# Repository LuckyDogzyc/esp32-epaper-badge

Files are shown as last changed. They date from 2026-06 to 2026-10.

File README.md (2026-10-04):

> ⚠️ **当前有效需求为 V2.2：《[改板需求说明-V2.2-ESP32C3-降本](改板需求说明-V2.2-ESP32C3-降本.md)》**（Word 版同名 `.docx`）
> **V2.2 = 换主控 ESP32-C6 → ESP32-C3-MINI-1-N4（pin-to-pin 兼容，省 ¥4.73/台）+ 全线降本**，单台降本约 **¥7.6–10.7**（屏若由三色改黑白可再省 ¥8–13）。
> **器件选型以《[BOM锁定表-V2.2](BOM锁定表-V2.2.md)》为准**（含立创编号、库存、"不接受"项）。
> V2.2 要点：C3 主控（重排引脚：**USB 改到模组脚 26/27**、**脚 15/17/24/25 在 C3 上是 NC**、电量采样改 **IO4/ADC1_CH4**、VBUS 检测改 **IO20**）+ 板载 **AHT20 温湿度**（IO0/IO1，外壳需透气孔）+ 板 **67×28×0.6mm**、无安装孔、堆叠"屏朝外 → 电芯 → PCB"、电芯 ≤4mm、两个侧按键、整机厚 ≈9.1–9.6mm。
> ⚠️ **出图前红线**：FPC 针数/间距/金手指朝向（图纸 ↔ 屏厂规格 ↔ 实机来料）必须核对一致。
> **以下"硬件方案/GPIO 分配"等段落描述的是 V1 版本，仅作对照，冲突处一律以 V2.2 为准。**

## 文档索引

| 文件 | 版本 | 用途 |
|---|---|---|
| `改板需求说明-V2.2-ESP32C3-降本.md` / `.docx` | **V2.2（当前有效）** | 换 C3 + 降本：C3 引脚映射全表、USB 走线变更、降本项清单、温湿度要求、验收 |
| `BOM锁定表-V2.2.md` / `.xlsx` | **V2.2（当前有效）** | 器件锁定 BOM：锁定件给立创编号与库存，参数锁定件给硬指标与"不接受"项 |
| `改板需求说明-V2.1-ESP32C6-含温湿度.md` / `.docx` | V2.1（历史） | C6 版 + 温湿度增补；仅作沿革对照 |
| `BOM锁定表-V2.1.md` / `.xlsx` | V2.1（历史） | C6 版锁定表；仅作对照 |
| `改板需求说明-V2-ESP32C6.md` / `.docx` | V2（历史） | 换 C6、删桥片与烧录开关、修正电池分压、新增 VBUS 检测 |
| `外包需求文档.md` | V1（历史） | 初版外包需求 |

低功耗 ESP32 + 2.13" 三色电子纸显示器，用于每日自动更新数据展示。当前参考原理图版本为 v1.2：已补充 USB-C 直供电、电池自动切换、103040 软包电池 PH2.0 接口、电池电量检测，以及独立的 USER_BTN 用户按键。**本版本仅用于下一版 PCB/reference schematic；现有外部原型 GPIO 映射不同，不能据此改线或直接刷写。**

## 硬件方案

| 模块 | 方案 | 说明 |
|---|---|---|
| MCU | ESP32-WROOM-32D | WiFi + BLE，deep sleep 10µA |
| 屏幕 | DEPG0213RWS 2.13" | 三色(黑白红)，SSD1680 驱动 |
| 充电/直供电 | TP4056 + D3/D4 SS14 | USB-C 充电，支持无电池 USB 直供电 |
| 保护 | DW01A + FS8205A | 过充/过放/过流保护 |
| LDO | HT7333-1 | 超低 Iq=1µA |
| 电池 | 103040 软包锂电池 PH2.0 | 1200mAh，外接插头，deep sleep 续航目标 >1 年 |

## 电路模块

1. **ESP32 最小系统** — 抄 Espressif 官方设计指南 v4.4
2. **SSD1680 驱动电路** — 抄已验证驱动板 v1.3 原理图
3. **TP4056 充电 + D3/D4 电源路径切换** — USB-C VBUS 与 VBAT 通过 SS14 汇聚到 VCC_RAIL
4. **DW01A+FS8205A 保护** — 抄数据手册参考设计
5. **HT7333 LDO** — VCC_RAIL 转 3.3V 系统电源
6. **VBAT_SENSE 电量检测** — R12/R13 100k 分压 + C21 100nF 滤波 → GPIO34
7. **USER_BTN 独立用户按键** — SW2 常开按键把 `USER_BTN_N` 拉低；R14 10k 外部上拉至 3V3，C22 100nF 去抖；连接 GPIO33，绝不接 ESP32 EN/RST

## GPIO 分配

| GPIO | 功能 | 目标 |
|---|---|---|
| 18 | SPI CLK | SSD1680.CLK |
| 23 | SPI MOSI | SSD1680.DIN |
| 5 | Reset | SSD1680.RST |
| 17 | D/C | SSD1680.DC |
| 16 | CS | SSD1680.CS |
| 4 | Busy | SSD1680.BUSY |
| 2 | Debug Switch | SW1 (LOW=调试) |
| 19 | LED | D5 状态指示 |
| 33 | USER_BTN | `USER_BTN_N`，独立 active-low 用户按键（短按状态；按住 ≥5 秒网络配网） |
| 34 | ADC | VBAT_SENSE 电池电量检测 |

### USER_BTN firmware contract (next PCB)

- Configure GPIO33 as an input; `USER_BTN_N` is **active-low** and has the fitted external R14 10k pull-up, so firmware must not rely on an internal pull-up.
- Apply a ≥20 ms software debounce; on a debounced press/release shorter than 5 seconds, show the device status.
- On a continuous debounced low level of **at least 5 seconds**, enter/keep awake for network provisioning. It is not a reset action.
- ESP32 EN/RST remains the normal reset/enable circuit only; do not connect USER_BTN firmware or PCB wiring to EN.

## 文件说明

| 文件 | 说明 |
|---|---|
| `esp32-epaper.kicad_pro` | KiCad 7 项目文件 |
| `esp32-epaper.kicad_sch` | v1.2 下一版 PCB 参考原理图，55 个组件已放置（含 GPIO33 USER_BTN） |
| `esp32-epaper-lib.kicad_sym` | 自定义符号库 |
| `DESIGN.md` | 完整设计文档 (BOM/网络表/引脚定义) |
| `schematic-preview.html` | 浏览器可查看的可视化原理图 |
| `gen_symbols.py` | 符号库生成脚本 (kiutils) |
| `gen_schematic.py` | 原理图生成脚本 (kiutils) |

## 使用方法

1. 安装 [KiCad 7+](https://www.kicad.org/)
2. 打开 `esp32-epaper.kicad_pro`
3. 运行 ERC 检查
4. 审查所有连线，重点检查 D3/D4 电源路径、J3 电池接口和 VBAT_SENSE
5. 分配封装 (footprints)
6. 进入 PCB 布局

## 设计原则

- 每块电路抄原厂参考设计，不发明电路
- 所有被动件值严格遵循数据手册
- HT7333 (Iq=1µA) 是续航关键，不用 AMS1117 (Iq=5mA)
- SSD1680 外围电路完全复制已验证的驱动板 v1.3

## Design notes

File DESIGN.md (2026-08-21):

# ESP32 电子纸显示器 — 硬件设计文档

## 项目概述
- 每日自动唤醒、WiFi连接、更新数据、刷新屏幕、deep sleep
- 拨动开关切调试/正常模式
- USB-C 充电 + USB 直供电 + 103040 软包电池 PH2.0 接口供电
- 2.13" 三色电子纸 (DEPG0213RWS, SSD1680)
- **v1.2 is the next-PCB/reference schematic only.** The external prototype has a different GPIO map; do not apply this wiring to it without a board-specific review.

## 方案确认
- MCU: ESP32-WROOM-32D (经典款，与用户现有开发板一致)
- 屏幕: DEPG0213RWS (2.13" 黑白红三色, SSD1680驱动)
- 供电: USB-C VBUS / 103040 VBAT → D3/D4 SS14 自动切换 → VCC_RAIL → HT7333 → 3.3V

---

## 1. GPIO 分配表

| 功能 | ESP32 GPIO | 方向 | 说明 |
|---|---|---|---|
| SPI CLK | GPIO18 | OUTPUT | VSPI CLK |
| SPI MOSI  | GPIO23 | OUTPUT | VSPI MOSI |
| EPD_RST | GPIO5 | OUTPUT | 屏幕复位 |
| EPD_DC | GPIO17 | OUTPUT | 数据/命令选择 |
| EPD_CS | GPIO16 | OUTPUT | SPI 片选 |
| EPD_BUSY  | GPIO4 | INPUT  | 屏幕忙状态 |
| DEBUG_SW  | GPIO2 | INPUT  | LOW=调试模式, HIGH=正常|
| LED | GPIO19 | OUTPUT | 状态指示灯(刷新时亮) |
| USER_BTN  | GPIO33 | INPUT  | `USER_BTN_N`，独立 active-low 按键；非 strapping GPIO；短按状态、连续按住 ≥5s 配网 |
| VBAT_SENSE| GPIO34 | INPUT  | 电池电量 ADC1_CH6 |

## 2. 电路模块

### 模块A: ESP32-WROOM-32 最小系统
来源: ESP32 Hardware Design Guidelines v4.4

组件:
- U1: ESP32-WROOM-32D 模组
- C1: 10μF 0805 (3.3V退耦)
- C2: 100nF 0805 (3.3V高频退耦)
- C3: 10μF 0805 (EN脚滤波)
- R1: 10kΩ 0805 (EN上拉)
- R2: 10kΩ 0805 (IO0上拉)
- R3: 10kΩ 0805 (IO2上拉, 调试开关)

连接:
- VDD (Pin 2) → 3V3
- GND (Pin 1,15,38,39) → GND
- EN (Pin 3) → R1上拉到3V3, C3到GND
- IO0 (Pin 25) → R2上拉到3V3
- IO2 (Pin 24) → R3上拉到3V3, 拨动开关到GND

### 模块B: SSD1680 电子纸驱动电路
来源: 用户提供的墨水屏驱动板v1.3原理图 (已验证可用)

组件:
- U2: SSD1680 (EPD驱动IC)
- L1: 68μH (电荷泵电感, 贴片功率电感)
- Q1: AO3400A (N-MOSFET SOT-23)
- D6, D7, D8: MBR0530 (肖特基二极管 SOD-123)
- R7: 10kΩ 0805
- R8: 0.47Ω (470mΩ) 0805
- C7~C15: 9× 1μF 0805
- C16: 100nF 0805
- C17: 100nF 0805
- C18: 4.7μF 0805
- FPC1: 26P 0.5mm FPC座 (下接或双侧触点)

SSD1680 SPI连接:
- CLK ← GPIO18
- DIN (SDA) ← GPIO23 (MOSI)
- CS ← GPIO16
- DC ← GPIO17
- RST ← GPIO5
- BUSY → GPIO4

### 模块C: TP4056 充电电路
来源: TP4056 Datasheet Rev 1.05 Typical Application

组件:
- U3: TP4056 (SOP-8)
- R4: 1.2kΩ 0805 (PROG, 设定充电电流500mA)
- C4: 10μF 0805 (BAT滤波)
- C5: 10μF 0805 (IN滤波)

连接:
- VCC (Pin 4) ← USB-C 5V (VBUS)
- GND (Pin 3) → GND
- BAT (Pin 5) → VBAT → 103040软包电池正极/J3 pin1
- PROG (Pin 2) → R4到GND
- CHRG (Pin 1) → 悬空或接LED指示
- STDBY (Pin 6) → 悬空或接LED指示
- CE (Pin 8) → VBUS (有USB时自动使能)

### 模块D: DW01A + FS8205A 电池保护电路
来源: DW01A Datasheet Typical Application

组件:
- U4: DW01A (SOT-23-6)
- U5: FS8205A (双N-MOSFET, TSSOP-8)
- R5: 100Ω 0805 (CS电阻)
- C6: 100nF 0805 (滤波)

连接: 标准DW01A+FS8205A参考设计

### 模块E: D3/D4 电源路径切换 + HT7333-1 超低功耗LDO
来源: HT7333 Datasheet

组件:
- U6: HT7333-1 (SOT-89)
- C19: 10μF 0805 (输入滤波)
- C20: 10μF 0805 (输出滤波)

连接:
- VIN ← VCC_RAIL（D3/D4 汇聚后的 USB 或电池输入）
- VOUT → 3V3 系统电源
- GND → GND

电源路径:
- USB-C VBUS → D3(SS14) → VCC_RAIL
- VBAT/J3 pin1 → D4(SS14) → VCC_RAIL
- USB 插入且无电池时，VBUS 经 D3 直接给 HT7333 供电，系统可运行
- USB 拔掉且有电池时，VBAT 经 D4 给 HT7333 供电

### 模块F: USB-C 母座
组件:
- J1: USB-C 16pin 母座 (沉板式)
- R9: 5.1kΩ 0805 (CC1下拉)
- R10: 5.1kΩ 0805 (CC2下拉)

连接:
- VBUS → TP4056 VCC
- CC1 → R9 → GND
- CC2 → R10 → GND
- GND → GND
- D+/D- → 预留给 USB 转串口/调试，如不贴 CH340 可悬空

### 模块H: 103040 电池接口 + 电量检测
组件:
- J3: PH2.0 2pin 电池接口
- R12/R13: 100kΩ/100kΩ 电池分压
- C21: 100nF 滤波

连接:
- J3 pin1 BAT+ → VBAT
- J3 pin2 BAT- → GND
- VBAT → R12 → VBAT_SENSE → R13 → GND
- C21 与 R13 并联到 GND
- VBAT_SENSE → ESP32 GPIO34 (ADC1_CH6)

### 模块G: 调试开关 + 状态LED
组件:
- SW1: 拨动开关 (3pin贴片)
- R11: 1kΩ 0805 (LED限流)
- D5: LED 0805 (绿色)

连接:
- SW1 COM → GND
- SW1 NO → GPIO2
- D5正极 → R11 → GPIO19
- D5负极 → GND

### 模块I: USER_BTN 独立用户按键（v1.2，下一版 PCB）
组件:
- SW2: 常开轻触按键，`Button_Switch_SMD:SW_SPST_TL3301AN`
- R14: 10kΩ 0603，外部上拉
- C22: 100nF 0603，硬件去抖/EMI 滤波（RC = 1ms）

连接:
- `USER_BTN_N` → ESP32 GPIO33（U1 pin 23）
- R14: 3V3 → `USER_BTN_N`
- C22: `USER_BTN_N` → GND
- SW2: `USER_BTN_N` → GND；按下时为低电平
- **EN/RST 仅保留 ESP32 正常 reset/enable 网络；SW2 与 EN 没有任何连接。** GPIO33 在当前原理图中未使用，且不是 ESP32 strapping pin；GPIO34 保留给 VBAT_SENSE。

Firmware contract:
- GPIO33 作为输入，使用外部上拉；以 ≥20ms 软件去抖。
- 小于 5 秒的已去抖按键动作用于状态显示；连续低电平 ≥5 秒进入并保持唤醒的网络配网流程，绝不复位芯片。

---

## 3. 完整 BOM

| Ref | 值/型号 | 封装 | 数量 | 参考单价(¥) |
|---|---|---|---|---|
| U1 | ESP32-WROOM-32D | 模组 | 1 | 7.00 |
| U2 | SSD1680 | QFN-48 | 1 | 1.50 |
| U3 | TP4056 | SOP-8 | 1 | 0.50 |
| U4 | DW01A | SOT-23-6 | 1 | 0.20 |
| U5 | FS8205A | TSSOP-8  | 1 | 0.30 |
| U6 | HT7333-1 | SOT-89 | 1 | 0.30 |
| L1 | 68μH | 4×4mm | 1 | 0.50 |
| Q1 | AO3400A | SOT-23 | 1 | 0.15 |
| D5 | LED 0805 | 0805 | 1 | 0.05 |
| D6 | MBR0530 | SOD-123  | 1 | 0.10 |
| D7 | MBR0530 | SOD-123  | 1 | 0.10 |
| D8 | MBR0530 | SOD-123  | 1 | 0.10 |
| C1~C5 | 10μF 0805 | 0805 | 5 | 0.25 |
| C6 | 100nF 0805 | 0805 | 1 | 0.05 |
| C7~C15| 1μF 0805 | 0805 | 9 | 0.45 |
| C16~C17| 100nF 0805 | 0805 | 2 | 0.10 |
| C18 | 4.7μF 0805 | 0805 | 1 | 0.05 |
| C19~C20| 10μF 0805 | 0805 | 2 | 0.10 |
| R1~R3 | 10kΩ 0805 | 0805 | 3 | 0.06 |
| R4 | 1.2kΩ 0805 | 0805 | 1 | 0.02 |
| R5 | 100Ω 0805 | 0805 | 1 | 0.02 |
| R7 | 10kΩ 0805 | 0805 | 1 | 0.02 |
| R8 | 0.47Ω 0805 | 0805 | 1 | 0.05 |
| R9~R10| 5.1kΩ 0805 | 0805 | 2 | 0.04 |
| R11 | 1kΩ 0805 | 0805 | 1 | 0.02 |
| J1 | USB-C 16pin母座 | 沉板式 | 1 | 0.30 |
| FPC1  | 26P 0.5mm FPC座 | 下接 | 1 | 0.50 |
| SW1 | 拨动开关 3pin | 贴片 | 1 | 0.20 |
| BT1 | 103040软包电池标注 | 外购 | 1 | - |
| J3 | PH2.0 2P电池接口 | 卧式/贴片 | 1 | 0.10 |
| D3,D4 | SS14肖特基二极管 | SMA | 2 | 0.10 |
| R12,R13| 100kΩ | 0402/0805 | 2 | 0.02 |
| R14 | 10kΩ | 0603 | 1 | 0.01 |
| C21 | 100nF | 0402/0805 | 1 | 0.01 |
| C22 | 100nF | 0603 | 1 | 0.01 |
| SW2 | USER_BTN, 常开轻触按键 | TL3301AN/SMD | 1 | 0.15 |

**BOM总计(不含屏幕电池): ~¥15.17**
**含屏幕(¥9) + 103040电池(¥12): ~¥36.17**

---

## 4. 网络连接表 (Netlist)

### 电源网络
- VBUS: USB-C 5V → TP4056 VCC → D3 阳极
- VBAT: TP4056 BAT / DW01A+FS8205A / J3 BAT+ / D4 阳极 / R12 上端
- VCC_RAIL: D3/D4 阴极汇聚 → HT7333 VIN
- 3V3: HT7333 VOUT / ESP32 VDD / SSD1680 VDD / 所有上拉电阻
- GND: 公共地
- VBAT_SENSE: R12/R13 中点 + C21 → ESP32 GPIO34

### SPI 总线
- EPD_CLK:  GPIO18 → SSD1680 CLK → FPC1
- EPD_MOSI: GPIO23 → SSD1680 DIN → FPC1
- EPD_CS:   GPIO16 → SSD1680 CS
- EPD_DC:   GPIO17 → SSD1680 DC
- EPD_RST:  GPIO5  → SSD1680 RST
- EPD_BUSY: GPIO4  ← SSD1680 BUSY

### SSD1680 电荷泵
- GDR:   SSD1680 → L1 → D6/D7/D8 → PREVGH/PREVGL
- RESE:  SSD1680 → R8
- PREVGH: D6/D7 → C10/C11/C12 → SSD1680
- PREVGL: D8 → C13/C14/C15 → SSD1680

### 其他
- DEBUG: GPIO2 ← SW1 (开关到GND)
- LED:   GPIO19 → R11 → D5 → GND
- USER_BTN_N: GPIO33 ↔ R14(3V3 上拉) + C22(GND 去抖) + SW2(GND，按下为 LOW)；EN/RST 不参与
- CC1:   J1 CC1 → R9 → GND
- CC2:   J1 CC2 → R10 → GND

---

## 5. 参考文档
1. ESP32 Hardware Design Guidelines v4.4 — 模组最小系统
2. SSD1680 Datasheet v1.2 — 驱动IC参考设计
3. 墨水屏驱动板 v1.3 原理图 (用户提供, 已验证) — SSD1680外围电路
4. TP4056 Datasheet Rev 1.05 — 充电电路
5. DW01A+FS8205A Datasheet — 电池保护
6. HT7333 Datasheet — LDO

---

## 6. SSD1680 FPC 26P 引脚定义 (DEPG0213RWS)

| Pin | 名称 | 连接到 |
|-----|---|---|
| 1 | GND | GND |
| 2 | GND | GND |
| 3 | GDR | Q1 Gate, L1 |
| 4 | GDR | Q1 Gate, L1 |
| 5 | PREVGL  | D8, C13-C15 |
| 6 | PREVGL  | D8, C13-C15 |
| 7 | PREVGH  | D6-D7, C10-C12 |
| 8 | PREVGH  | D6-D7, C10-C12 |
| 9 | GDR | Q1 Gate |
| 10  | GDR | Q1 Gate |
| 11  | RESE | R8 |
| 12  | RESE | R8 |
| 13  | PREVGH  | D6-D7 |
| 14  | PREVGH  | D6-D7 |
| 15  | PREVGL  | D8 |
| 16  | PREVGL  | D8 |
| 17  | RESE | R8 |
| 18  | RESE | R8 |
| 19  | 3V3 | 3V3 |
| 20  | 3V3 | 3V3 |
| 21  | EPD_CLK | SSD1680 CLK |
| 22  | EPD_DIN | SSD1680 DIN |
| 23  | EPD_RST | SSD1680 RST |
| 24  | EPD_DC  | SSD1680 DC |
| 25  | EPD_CS1 | SSD1680 CS |
| 26  | EPD_BUSY| SSD1680 BUSY  |

注: 实际引脚顺序以DEPG0213RWS数据手册为准，此处基于常见2.13寸三色屏FPC定义。

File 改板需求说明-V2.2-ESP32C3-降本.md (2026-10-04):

# ESP32 墨水屏胸牌 —— PCB 改板需求说明（V2.2 · 换 ESP32-C3 主控并全线降本）

> **文件性质**：本文件是在《ESP32 墨水屏胸牌 PCB 设计外包需求（V1）》基础上的**变更说明**。
> 未提到的内容**沿用 V1**；凡与本文件冲突处，**以本文件为准**。
> 适用对象：PCB 设计外包方。变更原因栏为实测/原理依据，可据此判断改动的必要性。
>
> **V2.2 说明（本版核心变更）**：主控由 **ESP32-C6-MINI-1-N4 改为 ESP32-C3-MINI-1-N4**（**封装焊盘完全兼容**，仅**引脚映射与 USB 走线**需按 §5.1 重排），并同步执行 §3.5 的**降本项**。**单台可省约 ¥10–17**（主控 ¥4.7 + 其余项）。
> 除标注 V2.2 的条款外，**其余一切沿用 V2.1**；冲突处**以 V2.2 为准**。
>
> **换 C3 的依据（实测/数据手册）**：C3-MINI-1 与 C6-MINI-1 **pin-to-pin 兼容**（乐鑫官方口径，模组焊盘与外形一致）；C3 实测固件 **1,331,535 B（1.27MB）**，比 C6 还小 22KB；原生 USB-Serial/JTAG **同样具备**（免按键烧录保住了）；ADC1 有 5 路（我们只用 1 路）；strapping 脚只剩 **GPIO2/GPIO8/GPIO9**。代价是 **Wi-Fi 4 而非 Wi-Fi 6/TWT**——本产品一天连一次、每次十几秒，**该差异无实际影响**。
> **价格**：C3-MINI-1-N4（立创 C2838502）**¥12.48 @650+** vs C6-MINI-1-N4（C5736265）**¥17.21 @1300+** → **省 ¥4.73/台（27%）**。
>
> **器件选型以附件《BOM锁定表-V2.1》为准**（需求方出具，与本文同等效力；两文件冲突处以 BOM 锁定表为准）。
> 锁定件必须照单采购；参数锁定件可等效替代，但**替代须经需求方书面同意**。

---

## 一、变更摘要（一句话）

主控由 **经典 ESP32-WROOM-32D + CH340N USB 转串口桥片**，更换为 **ESP32-C3-MINI-1-N4（自带 PCB 天线、原生 USB、4MB 片内 Flash）**（V2.2：由 C6 调整为 C3，原因与价格见文首）；随之**删除 USB 转串口电路、手动烧录按键与拨动开关**，**修正电池电量采样电路**，并**重新定义两个按键的功能**。

**V2.2 一句话**：主控换 **ESP32-C3-MINI-1-N4**（同封装，省 ¥4.73/台），按 §5.1 重排引脚与 USB 走线，并按 §3.5 执行降本。
**V2.1 已定**：尾部区/板边加一颗 I2C 温湿度传感器（U7 = AHT20），配 **2×10kΩ 上拉 + 100nF**，接 **IO0(SDA)/IO1(SCL)**；外壳对应位置留透气孔（§5.7 末）。

**本文件的使用方式**：你们（设计方）已交付并制作过 V1 板，本文件即**在你们那版 V1 基础上的改板制造说明**——请按"三、器件变更总表"逐项增删改，未提及处一律沿用 V1 画法与你们既有的工艺。有冲突处以本文件为准。

**机械结论（本版已定）**：板 **67 × 28 mm**（屏区 + 8mm 尾部区）；堆叠为 **屏朝外 → 电芯 → PCB（元件面朝卡片背面）**；电芯 **≤4mm 厚**；USB-C 与两个侧按键布置在**屏外尾部区**；**板厚 0.6mm、不设安装孔**，整机总厚 **≈9.1–9.6mm**。详见 §5.5。**V2.1 增补**：温湿度传感器置于**尾部区靠板边**（高度 ≤1.0mm，**不影响总厚**），外壳需在该位置留透气孔（§5.7）。

---

## 二、变更原因（实测依据，供理解改动必要性）

| 序号 | 问题 | 实测/原理 |
|---|---|---|
| 1 | 烧录必须手动拨开关进下载模式 | 板上 **CH340N 是 SOP-8 精简版，只有 UART+RTS，没有 DTR**；ESP32 自动下载时序必须同时用 DTR 和 RTS，因此这版硬件**做不出自动下载**。另外该拨动开关接在 **IO2**（strapping 脚）上，上电拉低会影响启动/下载判定，属隐患 |
| 2 | 换 C6/C3 后是否还会卡在烧录 | **C3（与 C6 相同）**具备**片内 USB-Serial/JTAG**，由 ROM 控制：常规烧录**不需要任何按键**，固件损坏也仍可恢复（砖了能救）。**注意 C3 的 USB 固定在 GPIO18/19（模组脚 26/27）** |
| 3 | 16MB Flash 是否必要 | 用本项目固件实测编译（`arduino-cli` 真编）：**经典 ESP32 = 1,355,704 B；ESP32-C6 = 1,353,644 B；ESP32-C3 = 1,331,535 B**。**4MB Flash 足够**（C3 上余量更大），原 16MB 要求取消 |
| 4 | 电池电量显示无效 | 实测：**采样脚直连 VBAT，满电时 ADC 饱和（raw=4095、≈3.14V）**；图纸标注的 GPIO34 分压点**无信号**。直连 4.2V 超出 ADC 量程，且经输入 ESD 二极管向 3.3V 轨漏电、影响待机功耗。**必须补分压并固定采样脚** |
| 5 | 体积/成本 | 模组面积由 18.0×25.5 = **459mm²** 降至 13.2×16.6 = **219mm²**（**-52%**），厚度 3.1→**2.4mm**；删除器件再省约 **165mm²** |
| **6（V2.1）** | **新增温湿度检测的代价** | **固件侧已实测**：同一 C6 目标用 `arduino-cli` 真编对比，加自写最小 I2C 驱动后 **Flash +1,086 B（1.06 KB）**、**常驻 RAM +16 B**（基线 1,327,460 B / 55,876 B）→ 3MB app 槽里占 **0.03%**，**空间上可忽略** |
| **7（V2.1）** | **检测一次要多久（会不会拖慢每日刷新）** | 传感器**自身测量时间**：AHT20 **80 ms**（规格书原文「Wait for 80ms…」）、SHT4x **8.3 ms**（Sensirion 规格书 −6.9/+8.3 ms）；**I2C 传输**在 100kHz 下 10 字节 ≈ **0.9 ms** → **单次合计 9–81 ms**。相对一次唤醒刷新的主耗时（Wi-Fi 连接 + 取价 + 三色墨水屏全刷，**秒级~十几秒级**）占 **0.05%–0.4%**，**完全可并入每日启动刷新，无感知** |

---

## 三、器件变更总表

### 3.1 删除项（V1 位号）

| 位号 | 器件 | 处理 | 原因 |
|---|---|---|---|
| U6 | CH340N USB 转串口 | **删除** | C6 使用原生 USB，不需要桥片 |
| R8, R9 | 1kΩ（TX/RX 串阻） | **删除** | 随 CH340N 一并废弃 |
| J4 | 排针 2×3 2.54mm（烧录口） | **删除** | USB-C 直连即可烧录/调试，无需排针 |
| C（CH340 相关） | CH340 的 V3/VCC 去耦 | **删除** | 随 U6 删除（具体位号由设计方在网表中识别） |
| SW（IO2 拨动开关） | 调试模式拨动开关 | **删除** | 功能移入固件；且 IO2 为 strapping 脚，不可外挂开关 |
| R2 | 10kΩ（IO0 上拉） | **删除** | BOOT 按键取消，上拉一并废弃 |
| **J3** | **PH2.0 电池插座** | **删除** | 本版改为**电芯极耳直接焊在 PCB 背面**，PCB 上新增 B+/B- 焊接焊盘（见 §5.4） |

### 3.2 替换项

| 位号 | 原 | 新 | 说明 |
|---|----|----|---|
| U1 | ESP32-WROOM-32D（18.0×25.5×3.1） | **ESP32-C3-MINI-1-N4**（13.2×16.6×2.4，自带 PCB 天线，4MB Flash 片内） | **V2.2 由 C6 改为此颗**：与 C6-MINI-1 **pin-to-pin 兼容**（焊盘/外形不变），**省 ¥4.73/台**。**注意选型：必须 `ESP32-C3-MINI-1`（PCB 天线版），不要 -1U（外置天线版）** |

### 3.3 保留项（不要动）

- EN 上拉 **R1(10k) + C10(100nF)**（EN 脚不可悬空，模组数据手册明确要求）
- 电源路径 **D3/D4（SS14）**、**FB1**、**HT7333（U2）**：**本版确认保留、不更换**（需求方决定：不换 LDO、不加 buck-boost）。请在 3.3V 侧加强储能——模组旁 **100µF 低 ESR + 10µF + 100nF**，用于顶住 Wi-Fi 发射的毫秒级峰值电流
- 充电与保护 **TP4056(U3) / DW01A(U4) / 8205A(U5)** 及**指示 LED D1/D2（保留，行为与现在一致：充电中红灯亮、充满绿灯亮）**
  - 请确保 U3 的 **CHRG → R4 → D1**、**STDBY → R5 → D2** 两条支路连线完整（按 V1 §4.2），否则指示灯不亮
- **USB-C（J1）及 CC 5.1k×2 下拉、USB ESD 保护**（USB-C 供电必需，切勿删）
- **墨水屏 FPC（J2）及其 SPI 网络**
- **板载电池保护（DW01A+8205A）继续使用**：因取消 PH2.0 插座、电芯直接焊接，过充/过放/短路保护必须依靠板载保护电路，不可省略
- 电池分压 **R12/R13（100kΩ）+ C21(100nF)**（见 §5.2，仅接线改向）

### 3.4 新增项（V2.1）

| 位号 | 器件 | 规格 | 说明 |
|---|---|---|---|
| **U7** | **温湿度传感器（I2C）** | **AHT20**（DFN-4，3.0×3.0×1.0mm，广州奥松，地址 **0x38**） | **本版按 AHT20 出图**。如需更高精度（±1.8%RH/±0.2℃、测量 8.3ms）可改 **Sensirion SHT40/SHT41**（1.5×1.5mm，地址 0x44），但**封装与走线需另开一版**，请先与需求方确认 |
| **R16、R17** | I2C 上拉电阻 | **10kΩ 1%（0402）**，上拉到 **3.3V** | 缺上拉会导致 I2C 完全不通（这是最常见的返工原因，务必装） |
| **C23** | 去耦电容 | **100nF（0402）** | 靠近 U7 的 VDD 脚（≤2mm） |

- 总线速率按 **100 kHz** 出图（本产品一天只读一次，无需 400kHz）
- U7 供电直接挂 **3.3V 常供**：AHT20 待机约 **0.25µA**，对整机日均耗电（1–6 mAh/天）**无影响**，因此**不需要**做 GPIO 供电门控（少两颗器件、少一处失效点）
- **封装高度 1.0mm**，低于屏区最高件（FPC 座 2.0mm）→ **不改变整机总厚**

> **U7 与整份 BOM 的选型依据见附件《BOM锁定表-V2.1》**：U7 锁定 **AHT20（立创 C2757850）**；
> 若要换 Sensirion SHT40/SHT41（封装不同）**必须另开一版并书面通知需求方**；
> **不接受** DHT11/DHT22 等单总线器件替代（待机 50–60µA，超出本产品日均耗电预算）。

### 3.5 降本项（V2.2，逐项说明取舍）

| 项 | 原 | 现 | 省 | 依据/风险 |
|----|----|----|----|---|
| U1 主控 | ESP32-C6-MINI-1-N4 | **ESP32-C3-MINI-1-N4** | **¥4.73** | pin-to-pin；仅丢 Wi-Fi 6/TWT，本产品用不到 |
| 电芯 | 电芯需带保护板 PCM | **改为不带 PCM 的裸电芯 + 镍带** | **¥0.5–1.0** | **板载已有 DW01A+8205A**，重复保护没必要；电芯厂按焊盘间距点焊镍带 |
| 充电指示 | （保持） | **保留 TP4056（CHRG+STDBY 双灯）** | — | **不改**：需求方要求"充电中红、充满绿"，换 SOT23-5 单灯充电 IC 会丢掉 STDBY ✗ |
| 电芯采购 | 经销 | **电芯厂直供**（去中间层） | ¥0.5–1.0 | 需供应商确认可下单型号 |
| PCB 表面处理 | 沉金 | **喷锡（HASL）** | ¥0.1–0.3 | 本板无细间距 BGA，喷锡足够；**FPC 座焊盘仍建议局部加厚** |
| PCB 拼板 | 单片 | **多拼一板**（拼板出货） | ¥0.2–0.5 | 提高贴片与打件效率 |
| SMT | — | **单面贴装 + 拼板** | ¥0.5–1.5 | 本板元件全在元件面（电芯在板背面但不贴片），单面可省一次过炉 |
| 阻容/磁珠/LED | — | **国产通用件、按参数采购** | ¥0.2–0.5 | 不锁 C 编号（见 BOM 锁定表说明） |
| 侧按键 | 进口/松下 | **国产 2×4mm 卧式侧按** | ¥1.0–1.5 | 只要满足 **160–250gf、寿命≥10 万次**；型号仍由需求方锁定 |
| U4/U5 保护 | 高价品牌 | 可选更便宜品牌（如 JSMSEMI ¥0.061 / TSOP-6 类 ¥0.13） | ¥0.05 | **不建议为 5 分钱换品牌**，优先保留现货好的（HL/台舟）；如换需书面确认 |
| **屏** | 2.13″ 三色 | **三选一：①继续三色但多厂比价直采 ②改黑白双色** | **①¥2–8 ②¥8–13** | **最大杠杆**。**改黑白是产品决策**：省 ¥8–13/台，**且黑白屏可局部刷新**（更快更省电）；代价是丢掉红色（现固件用红色显示 "NO DATA" 等强调信息） |

**降本合计**：主控 ¥4.73 + 电芯/采购 ¥1.0–2.0 + PCB/SMT ¥0.8–2.3 + 通用件/按键 ¥1.2–2.0 = **约 ¥7.7–11.0/台**；**若屏改黑白再省 ¥8–13**（合计最高约 **¥20/台**）。

> ⚠️ **不做的事（明确列出，避免为省小钱踩大坑）**：不换裸芯片 chip-down（RF/认证风险 ✗）、不换非乐鑫模组（封装不兼容 ✗）、不换单灯充电 IC（丢 STDBY ✗）、不砍充电/保护/ESD（安全件 ✗）、不砍 EN 的 RC（起振不可靠 ✗）。

---

## 四、按键与用户交互（重新定义，重要）

V1 中的"SW1-SW2 = RST/BOOT"作废。新定义如下（两个键都保留，**均为侧按式**）：

| 位号 | 功能 | 连接 | 说明 |
|---|---|---|---|
| **SW1** | **复位（实体键）** | **EN** → SW1 → GND（保留 R1 10k 上拉、C10 100nF） | **本版按实体按键出图**；硬件复位，也是固件卡死/深睡时唯一的恢复手段 |
| **SW2** | **功能键** | **IO3** → SW2 → GND，配 **10kΩ 外部上拉**（R10），可选并联 100nF 去抖 | 低电平有效；详见下方功能定义 |

**SW2 功能定义（固件侧实现）**
- **短按（<1s）**：立即刷新——取价 + 重刷墨水屏
- **长按 ≥5s**：进入配网模式——清除 Wi-Fi 配置并开启 AP 热点（手机连接配网）
- **长按 ≥15s**（可选档，建议保留）：恢复出厂设置（清除全部配置）

**按键选型与结构（本版全部改为「侧按式」，需求方已确认）**
- **SW1、SW2 都改用"侧按式"贴片轻触开关**：作动方向**平行于板面**、从卡片**侧边**按压；开关贴板边安装，按钮端突出板边约 **0.3–1.0mm**
- 可选型号（三选一，或由设计方提供等效件并注明型号）：
  | 型号 | 尺寸 | 关键参数 |
  |------|------|---------|
  | **Panasonic EVQ-P7A01P 类** | 3.5 × 2.9mm，安装高度 1.35mm | 侧按、约 220gf、回流焊，通用性最好 |
  | Panasonic EVP-AK 系列 | 3.8 × 1.9mm | 行程 0.12mm，寿命可达 500,000 次（最薄） |
  | 国产等效（2×4mm / 2.3×2.95mm 卧式贴片侧按键） | 约 2×4mm | 成本更低、交期更快 |
- 共同要求：**操作力 160–250gf**、**寿命 ≥100,000 次（推荐 200,000+）**、回流焊、RoHS
- **位置**：放在**屏外尾部区的侧边**（见 §5.5/§5.6），两键中心距 ≥6mm 防连按；避开墨水屏 FPC 弯折区与电芯位置
- **按键位置**：置于尾部区板边、作动方向朝板外；机械按压通道由需求方后续处理（见 §5.6）
- 建议按键两侧加小电容/TVS 抗 ESD（人手接触）
- 仍建议在 EN/GND 旁并两个测试盘（产线复位用，与 SW1 并联）

**技术约束（务必遵守，否则按键唤不醒芯片）**
- 功能键必须接在 **RTC/LP GPIO（IO0–IO7 之一）**，才支持深睡中被按键唤醒；本方案选 **IO3**
- **禁止**将按键接在 strapping 脚 **IO4、IO5、IO8、IO9、IO15** 上
- **IO8、IO9 必须保持默认（不外挂上拉/下拉）**——它们决定启动模式；**IO15 也不得外挂上下拉**（决定 JTAG 信号源，默认即片内 USB）

---

## 五、原理图连线变更（Pin-to-Pin，请按此重连）

### 5.1 主控引脚映射（ESP32-C3-MINI-1-N4，V2.2 重排）

⚠️ **本节的引脚号与 V2.1（C6 版）完全不同，请勿沿用旧表。** 两份数据手册的**同一脚号对应的 GPIO 不同**，且 C6 用过的 **脚 15、17、24、25 在 C3 上是 NC**、**USB 在 C3 上是脚 26/27（C6 是 17/18）**。

| 功能 | 模组脚号 | GPIO | 备注 |
|---|---|---|---|
| EPD_SCLK | 20 | **IO6** | 默认 FSPICLK，信号完整性最佳 |
| EPD_MOSI | 21 | **IO7** | 默认 FSPID |
| EPD_CS | 16 | **IO10** | 默认 FSPICS0，最合适 |
| EPD_DC | 23 | **IO9** | strapping 脚，**仅作输出**（GPIO9 片内弱上拉保证启动为高）；**不得外挂上下拉** |
| EPD_RST | 22 | **IO8** | strapping 脚。C3 数据手册 Table 4-3：SPI 启动模式下 **GPIO8“任意值均可”**，故可安全用作输出；**不得外挂上下拉** |
| EPD_BSY | 19 | **IO5** | 普通 GPIO，输入 |
| VBAT_SENSE | 18 | **IO4** | **ADC1_CH4**（ADC1 仅 GPIO0–GPIO4）；见 §5.2 |
| USER_BTN（SW2） | 6 | **IO3** | LP_GPIO3，支持深睡唤醒；10k 上拉 + 按下接地（§4） |
| TH_SDA | 12 | **IO0** | ADC1_CH0 兼 I2C；**10k 上拉到 3.3V**（R16） |
| TH_SCL | 13 | **IO1** | ADC1_CH1 兼 I2C；**10k 上拉到 3.3V**（R17） |
| VBUS_DET | 30 | **IO20（RXD0）** | VBUS 检测；见 §5.3。用作 GPIO 输入后，串口日志请走 **USB CDC** |
| USB_D− | 26 | **IO18** | **V2.2 改接**（V2.1 接的是脚 17） |
| USB_D+ | 27 | **IO19** | **V2.2 改接**（V2.1 接的是脚 18） |
| EN（SW1 复位） | 8 | EN | 10k 上拉 + 100nF 到 GND，不可悬空 |
| 3V3 | 3 | 3V3 | 加 10µF + 100nF 去耦 |
| GND | 1、2、11、14、36–53 | GND | 全部接地 |
| 备用（建议留测试盘） | 5、31 | IO2、TXD0(IO21) | 留测试盘；**IO2 为 strapping 脚，不得外挂上下拉/按键**（数据手册建议上拉，故直连测试盘即可） |
| NC（C3 上无功能，勿接） | 4、7、9、10、15、17、24、25、28、29、32–35 | — | **V2.1 曾用到的脚 15/17/24/25 在此为空脚**，务必核对 |

**换 C3 必须同步改动的地方（清单，供设计方逐条勾）**

1. **USB 网络改向**：D−/D+ 从脚 17/18 → **脚 26/27**（C3 的 USB 固定占 IO18/IO19）
2. **EPD 六根线全部改脚**（见上表）；SPI 三根落到 FSPI 默认脚 IO6/IO7/IO10
3. **电量采样脚由 IO2 改到 IO4**（IO2 在 C3 上是 strapping 脚，不可挂分压电阻）
4. **VBUS 检测由脚 24 改到脚 30（IO20）**
5. 脚 **15/17/24/25 是 NC**，请检查旧版图上有无残留网络
6. 固件侧同步项（需求方负责，告知设计方以便核对）：ADC 通道常量改为 **ADC1_CH4**、深睡唤醒仍用 **ext1**（C3 无 ext0，与 C6 相同）、串口日志改走 **USB CDC**

### 5.2 电池电量采样（必须修正，V1 §4.7 作废）

```
VBAT(电池正极) ── R12(100kΩ) ──┬── VBAT_SENSE ── ESP32-C3 IO4 (脚 18, ADC1_CH4)
                               │
                            C21(100nF)
                               │
                            R13(100kΩ)
                               │
                              GND
```

- 分压比 **2:1**（4.2V → 2.1V，落在 ADC 量程内）
- **禁止把 VBAT 直接接到任何 GPIO**（V1 当前的实测问题即由此产生）
- 采样节点（IO2）到 GND 之间加 **100nF** 滤波
- **可选优化（建议）**：在 R12 前串一个高边 P-MOS 开关，仅在测量瞬间导通，可把分压常耗电流从约 21µA 降到 0（对深睡电流目标有意义）

### 5.3 USB 供电检测（新增，V1 无此电路）

现状说明：**V1 及目前实物均没有 USB 检测电路**（固件注释明确写着 "No USB-present signal is wired"），现在界面上的"USB/未接电池"只是固件在 ADC 读数无效时的兜底文案，并非真实检测。

```
USB-C VBUS(5V) ── R14(100kΩ) ──┬── VBUS_DET ── ESP32-C3 IO20 (脚 30, RXD0)
                               │
                            C22(100nF)
                               │
                            R15(100kΩ)
                               │
                              GND
```

- 分压比 2:1（5V → 2.5V），插 USB 时 IO18 读到高电平，固件据此显示"USB 供电 / 充电中"
- **该分压接在 VBUS 侧，不插 USB 时不通电，不会消耗电池**（与 §5.2 的电池分压不同）
- 保留 §5.2 的电池分压，两者配合即可实现"供电来源 + 电池电量"同时显示

### 5.4 电池：取消插座，改为背贴焊接（本版变更）

**取消 J3（PH2.0 插座）**，电芯极耳直接焊到 PCB 背面焊盘。要求：

1. **新增焊盘**：BAT+ / BAT- 两个焊盘，位置与所选电芯极耳位置对应；丝印标注极性（B+/B-），**极性标反会烧板，务必双人复核**
2. **电芯必须带焊片/镍带（Tab）**，不接受裸极耳；焊接工艺：烙铁 ≤350℃、单点 ≤3s、焊点离电芯本体 ≥2mm，焊后用硅胶/UV 胶加固
3. **背面电池区域**：不得有过孔、不得有裸露走线（防刺穿短路）；电芯与 PCB 之间垫绝缘片（青稞纸/PET）
4. **必须避开模组天线净空区**：电芯不得压在天线正下方及其前方净空区内（见 §6）
5. 四周留 **0.5mm** 膨胀余量，厚度方向留 **1mm**；电芯与板边平行放置

**电芯选型（依 §5.5 堆叠：电芯夹在墨水屏与 PCB 之间；已锁定厚度 ≤4mm）**

| 方案 | 尺寸（厚×宽×长 mm） | 标称容量 | 说明 |
|---|---|---|---|
| 标准现货（推荐先打样用） | **402550：4×25×50** | **450mAh** | 现货可买，长度 50mm ≤ 可用 52mm ✓ |
| 标准现货（备选） | 402540：4×25×40 | 400–420mAh | 更短，容量略小 |
| 定制（量产最优） | **4×27×52** | **约 560–620mAh** | 面积做满；软包按尺寸裁切，一般 MOQ 500–1000 |

**可用电芯区**（板 67×28，见 §5.5）：**约 52 × 27 mm**

**续航估算**（可用容量按 80%、自放电 2%/月计；"不刷屏"= 价格未变化时跳过墨水屏刷新）

| 电芯 | 60 分钟唤醒 | 60min + 不刷屏 | 120 分钟唤醒 | 120min + 不刷屏 |
|---|---|---|---|---|
| 402540（420mAh） | 41 天 | 58 天 | 77 天 | 108 天 |
| **402550（450mAh）** | **43 天** | **62 天** | **82 天** | **115 天** |
| 定制 4mm（600mAh） | 57 天 | 81 天 | 107 天 | 148 天 |
| 定制 4mm（620mAh） | 59 天 | 84 天 | 110 天 | 153 天 |

> 说明：4mm 厚度下容量由**面积**决定，因此定制 27×52 比标准 25×50 多约 30% 容量。若续航不满意，最有效的杠杆是**延长唤醒周期**（60→120 分钟几乎翻倍）与**价格未变不刷屏**，而不是加厚电芯。

### 5.5 整机堆叠与厚度（本版新增，决定性章节）

**堆叠顺序（由外到内）**

```
[卡片正面] 墨水屏（屏幕朝外）
              ↓
           电芯（夹在屏与板之间，可用约 55×27mm）
              ↓
           PCB（元件面朝卡片背面：模组、USB-C、按键、电源）
              ↓
[卡片背面] 背壳（塑料，需留按键按点与 USB 开孔）
```

**射频判断**：该堆叠下模组的 PCB 天线位于**元件面**，朝卡片背面辐射；屏与电芯都在板的另一侧，不再挡在天线正前方 → **射频环境比"屏盖板"方案好得多，方向性判断成立**。但仍须遵守三条：

1. **天线净空区必须全层无铜**（天线下方、模组投影区内，板的正反两面都不铺铜、不走线）——这条与堆叠无关，是硬要求；
2. **电芯的投影不要压在天线正上方**：虽然电芯在板的另一侧，但大面积金属膜仍会失谐 → 建议电芯与天线区间隔 **≥5mm**；
3. **背壳本体必须是塑料（非金属）**；装配后**必须实测 RSSI 与连接距离**（不能只看理论）。
4. **V2.2 新增：外壳含"正面外观金属件"（拉丝质感，纯外观、仅正面）**。**正面金属的射频风险远小于背面金属**，原因是：模组的 PCB 天线位于**元件面、朝卡片背面辐射**，而正面金属与天线之间**隔着 PCB 的地平面**。但仍须遵守以下要求：
   - **不得覆盖墨水屏显示区**：只做**前框/装饰环**，按屏可见区（**48.55 × 23.71mm**）开显示窗，四周留 **0.3–0.5mm**
   - **不得遮挡温湿度透气孔**（§5.7）——外观件与透气通道不能互相打架
   - **尽量避让天线正对的那一段（尾部区）**：前框在尾部区一侧**尽量收窄或断开**；若结构上无法避免，金属件边缘与天线区投影**至少留 15mm**
   - **材料建议：用"拉丝铝 + 阳极氧化"，不要用铁/碳钢**——①**铁会生锈**，必须电镀/喷涂，盐雾风险高；②**铁是铁磁性材料**，对磁吸/磁场不友好；③**重量差 3 倍**（同 0.3mm：铝 **1.5g** vs 铁 **4.4g**，本表下方已实算）；④铝拉丝+阳极的**质感与抗指纹**更好
   - **验收必须做**：装配完整机（塑料壳 + 正面金属件 + 电芯 + 屏）后**实测 RSSI 与可用连接距离**，与"裸板"对比，**衰减超过 6dB 即判不合格**，需调整金属件位置/面积

   **附：外观件重量实算（67×28mm 未扣窗，厚 0.3 / 0.5mm）**

   - 铝（2.7 g/cm³）：**1.52g / 2.53g**
   - 铁·钢（7.87 g/cm³）：**4.43g / 7.38g**

**厚度账（分区域取最大值，单位 mm）**

厚度**不是各层相加**，而是"屏区"与"尾部区"各自计算后**取较大值**（模组、USB-C 都在尾部区，不与屏/电芯叠加）：

- **屏区** = 屏 1.05 + 屏胶 0.2 + 电芯 T + 缓冲 0.3 + **PCB** + 屏区最高元件 + 背壳内隙 0.4 + 背壳 0.6
- **尾部区** = PCB + 模组 2.4 + 背壳内隙 0.4 + 背壳 0.6 + 前壳 0.6 ≈ 4.6（**不是瓶颈**）

| PCB 厚度 | 电芯 3.0mm | 电芯 3.5mm | 电芯 4.0mm |
|---|---|---|---|
| **0.6mm（推荐）** | ≈8.6 | ≈9.1 | **≈9.6** |
| 0.8mm | ≈8.8 | ≈9.3 | ≈9.8 |

（屏区最高元件按 FPC 座 2.0mm 计；若屏区元件压到 1.5mm，可整体再减 0.5mm）

**✅ 本版已确定的机械配置**

| 项目 | 取值 |
|---|---|
| 板子尺寸 | **67 × 28 mm**（屏区 59.2 + 尾部区 8） |
| **板厚** | **0.6mm（推荐）**，可选 0.8mm |
| **安装孔** | **不设安装孔/定位孔**（板在壳内以双面胶/泡棉胶固定） |
| USB-C 位置 | 屏外尾部区（不在屏下 → 3.2mm 不计入总厚） |
| 电芯 | 厚度 **≤4mm**，面积约 52×27mm（见 §5.4） |
| 整机总厚 | **≈9.1–9.6mm**（0.6mm 板 + 4mm 电芯） |

**尾部区（8mm）建议布置**：模组（天线朝卡片外端）+ USB-C（与模组并排于短边）+ 两个侧按键；屏的 FPC 座放在屏区外侧短边。

**再减薄的空间（可选）**：电芯 3.5mm → -0.5；屏区最高元件压到 1.5mm → -0.5；缓冲 0.3→0.2、背壳 0.6→0.5 → 各 -0.1。

**结构要求**
- 电芯四周留 **0.5mm**、厚度方向留 **1mm** 膨胀空间；电芯与屏之间加 **0.2–0.3mm** 缓冲垫（防压屏）
- 电芯极耳/镍带走向与 PCB 焊盘对齐（见 §5.4），**不得跨过 FPC 弯折区**
- **板子固定方式**：双面胶/0.5mm 泡棉胶贴装（3M 200MP 类）→ 因此**板面不设螺丝孔与定位孔**
- **0.6mm 板注意**：USB-C 座的焊接强度会下降，请加大固定焊盘/加锡量或做局部补强（**不要因此改回 1.6mm**）

### 5.6 结构固定与按键通道（与外壳解耦）

- **本版不与外壳/开孔绑定**：设计方按 §5.5 的板尺寸与堆叠出图即可，**无需等待外壳资料，也不必做外壳干涉核对**
- **板子不设安装孔**：靠双面胶/泡棉胶固定在壳内（省下孔位及周围禁布区约 40–120mm²，也省掉螺丝高度）
- **两个侧按键**：位于板边、作动方向朝板外、按钮端突出板边 **0.3–1.0mm**；机械按压通道由需求方后续与外壳方案一并处理。设计方只需保证：位于**尾部区侧边**、两键中心距 ≥6mm、不与电芯/FPC 冲突、丝印标注功能（SW1 复位 / SW2 短按刷新·长按重置）
- **屏与板的相对定位**由电芯缓冲垫与胶带保证；屏 59.2mm 与板 67mm 的 8mm 差值即尾部区

### 5.7 温湿度检测（V2.1 新增）

**电路（请按此连线）**

```
3V3 ── R16(10kΩ) ──┬── TH_SDA ── ESP32-C3 IO0 (脚 12)
                   └── U7 SDA (AHT20 pin 1)

3V3 ── R17(10kΩ) ──┬── TH_SCL ── ESP32-C3 IO1 (脚 13)
                   └── U7 SCL (AHT20 pin 2)

3V3 ──┬── U7 VDD (pin 4)
      └── C23(100nF) ── GND

U7 GND (pin 3) ── GND
```

- **R16/R17 必须装**（10kΩ 上拉到 3.3V）；AHT20 地址固定 **0x38**，无需地址配置
- **禁止**把 I2C 改到 **IO4/IO5/IO8/IO9/IO15**——这些是 strapping 脚，**不允许外挂上拉电阻**
- 若贵方布局上 IO0/IO1 不便，可改用 **IO22/IO23**（同为普通 GPIO，非 strapping），但需在文件与丝印中同步修改，并通知需求方（固件要跟着改）

**布局要求（有 datasheet 依据，请照做）**

1. **传感器下方与四周尽量少铺铜**：AHT20 规格书明确要求「保持外壳良好通风，AHT20 与板面其他部分的铺铜应尽可能小，或在两者之间留出间隙」——IO0/IO1 与 U7 周围做**禁铺铜/稀疏地**，U7 与 3.3V 地铜之间留 ≥1mm 间隙
2. **远离热源**：U7 距 ESP32 模组、TP4056、HT7333、充电回路及 USB-C 至少 **10mm**（充电/LDO/模组发热会直接抬高温度读数）；**不要放**在模组投影区与电源入口附近
3. **U7 尽量靠板边**，与外壳的透气开孔对齐（见下）；远离开水（FPC 弯折区）与电芯投影区
4. I2C 两根线**短而平行、不跨分割、不加长分支**；时钟线与 SPI/USB 差分线保持间距
5. 传感器位置**不需要**做元件面/焊接面特殊处理，按常规 SMT 贴装（DFN-4，回流焊）

**结构要求（本版明确）**

- **外壳必须在传感器位置留透气通道**：小孔（建议 **≥φ1.5mm** 或等效面积缝隙）或**防水透气膜（Gore 类）**；**完全密封的壳体内测出的湿度是壳体内部值，毫无意义**——这是本项目对结构的**硬要求**
- 传感器**不得被电芯、屏、胶带覆盖**；感湿面朝向外壳开孔方向
- 若无开孔空间，需**提前反馈**，由需求方调整结构方案（不要默认按密封做）

**产品用途与由此产生的硬要求（V2.1 补充，务必按此执行）**

本产品的温湿度功能**面向卡牌/球星卡收藏的保存环境监测**（不是消费级"室内舒适度"），因此下面几条**是产品功能的一部分，不是可选的优化项**：

1. **测点必须与壳体外部空气相通**：传感器感湿面**不得**被灌封胶、泡棉、双面胶、标签、结构件或电芯遮挡。产线**禁止在 U7 上点胶/覆膜**（这是最常见的返工点）
2. **透气通道加防水透气膜（Gore 类）或细密网**：既保证空气交换，又防止灰尘/水汽直接冲击感湿孔；**不得用密封胶堵孔**
3. **量程与精度要求**：0–100%RH、−20~+60℃ 级；**精度优于 ±2%RH / ±0.3℃**——这是为了能判读"目标区 40–50%RH"与"报警线 65%RH"。AHT20（±2%RH/±0.3℃）满足；若换用更差精度的器件，需求方不认可
4. **热源隔离量化（理由）**：U7 距模组/TP4056/HT7333/USB-C **≥10mm**。器件**自发热会同时抬高温度读数、拉低湿度读数**——这是"读数不可信"的主要原因，不是纯粹的理论担忧
5. **外壳材料限制（保存场景特有）**：外壳与壳内配件**不得使用 PVC 或含增塑剂塑料、木质/密度板(MDF)、普通纸板、酸性胶粘剂/泡棉**——它们会逸出乙酸/甲醛类污染物或使增塑剂迁移，对卡纸是长期损伤；建议 **PP / ABS / PC** 壳体 + **中性（无酸）双面胶**；**壳内不得贴酸性标签/纸卡**
6. **展示面（墨水屏/前框）不承担透气功能**：透气孔独立于显示区，避免影响外观与密封

---

## 六、布局与射频要求（更新 V1 §3.2）

1. **PCB 天线净空（重点）**：模组天线端应**伸出板边**；**天线区域及其正下方所有层不得铺铜、不得走线**；天线前方约 **15mm** 范围内不放置金属件/电池/大块铜箔；模组尽量远离电芯与大块金属。**V2.2 补充：外壳的正面外观金属件（拉丝铝/铁）按 §5.5 第 4 条执行；天线净空区内不得有任何金属（含外观件伸入）。**
2. **USB 差分线 D+/D-**：尽量短、等长、避免跨分割，串阻/ESD 器件靠近 USB-C。
3. **SPI（模组→墨水屏）走线尽量短**；EPD 的去耦电容靠近 FPC 座。
4. **ADC 分压（VBAT_SENSE）**远离 SPI、USB、充电电路等高频/大电流区域。
5. **充电电路**（TP4056）走线足够宽；D3/D4 靠近电源入口。
6. 模组下方地平面完整，模组四周多打地过孔（散热与射频回流）。
7. **电芯区（屏与板之间，见 §5.5）**：PCB 上该区域对应的走线/过孔允许（电芯不在 PCB 表面），但**丝印须标出电芯外形与极性**；电芯投影不得进入天线净空区，且与天线区间隔 ≥5mm。
8. **两个侧按键（SW1/SW2）**位于尾部区板边，丝印标注功能（SW1 复位 / SW2 短按刷新·长按重置）；**板面不设安装孔**。
9. **（V2.1）温湿度传感器 U7**：尾部区靠板边；周围**稀疏铺铜**、距热源 ≥10mm；I2C 上拉电阻（R16/R17）**靠近 U7** 放置；丝印标注 **U7 用途**与**感湿面朝向**（见 §5.7）

---

## 七、Flash 与分区要求（需求方固件侧负责，设计方仅需按此选型/留分区）

- **Flash 容量 4MB 即可**（C3 实测固件 **1,331,535 B / 1.27MB**）；选型后缀 **-N4**（**片内 Flash，模组内已含，无需外挂**）；如需 OTA 余量可选 -N8，但非必须
- 分区表必须包含：
  - `nvs` ≥ 20KB（设备配置、渲染指令、槽位参数）
  - **`fat`（FFat）分区 ≥ 64KB** —— 固件用 FFat 存放位图帧文件（约 8KB）。**若分区表中只有 spiffs 分区，FFat 将挂载失败**，请务必保留一个 `data, fat` 分区
  - `app` ≥ 2MB
- **注意**：Arduino 默认的 4MB 分区方案（app 槽仅 1.2MB）**装不下本固件**，请使用自定义分区表

---

## 八、交付物与验收标准（增补 V1 §3.3 / §七）

**交付物（在 V1 基础上补充）**
1. KiCad 7 原理图（已完成全量连线、ERC 通过）+ PDF
2. PCB 源文件 + Gerber（RS-274X）+ 钻孔（Excellon）+ BOM（Excel）+ 贴片坐标
3. **位号图/装配图**（标注 SW1/SW2 位置与功能）
4. BOM 中 U1 必须写**完整型号**（`ESP32-C3-MINI-1-N4`），且**整份 BOM 须与附件《BOM锁定表-V2.2》逐项一致**（位号、型号、品牌、封装、参数）；凡锁定件不得自行替换

**验收标准（新增/修改）**
1. ✅ 原理图 ERC 通过、PCB DRC 通过，所有网络连通
2. ✅ **天线区域净空检查通过**（天线区及正下方无铜、无走线）
3. ✅ **USB-C 直连电脑即可烧录，全程不需要按任何按键**
4. ✅ **电池分压输出实测**：满电时采样点电压 ≈ VBAT/2（约 2.1V），不得出现饱和
5. ✅ 两个侧按键按压力/手感正常（160–250gf），短按与长按均能被固件识别（电气验证由需求方固件侧完成）
6. ✅ 无电池时插 USB-C 系统可正常运行
7. ✅ 分区表含 fat 分区（见 §7）
8. ✅ **插 USB 时 VBUS_DET（IO18）读到高电平**，拔掉后为低电平
9. ✅ **充电电流按所选电芯的 0.5C 实测**（R3 按 §5.4 调整），充电中红灯亮、充满绿灯亮
10. ✅ 电池焊盘极性丝印正确、电芯可完整放入"屏与板之间"的位置且不压天线净空区
11. ✅ **两个侧按键按压力 160–250gf 手感正常**，按钮端突出板边 0.3–1.0mm
12. ✅ **板面无安装孔**；整机总厚按 §5.5 区域法计算 **≤9.6mm**（0.6mm 板 + 4mm 电芯）
13. ✅ **（V2.1）I2C 上拉电阻 R16/R17 已装**（10kΩ → 3.3V），且 U7 的 SDA/SCL 走线无断线、无短路
14. ✅ **（V2.1）U7 位置检查**：距模组/TP4056/HT7333/USB-C ≥10mm；U7 下方与四周铺铜已按要求稀疏化；丝印标注完整
15. ✅ **（V2.1）上电后固件读数合理**：温度接近室温、湿度在 20–80%RH 区间（不在密封壳内时的读数才算数；样机阶段可先不装壳验证）

---

## 九、改板步骤（建议顺序，供设计方参考）

1. 在 V1 工程中**替换 U1** 库符号/封装为 `ESP32-C3-MINI-1`（含 keepout 区，**焊盘与 C6 版一致**），按 §5.1 **重排全部网络**；⚠️ 重点是 **USB D−/D+ 改到脚 26/27**、**脚 15/17/24/25 在 C3 上是 NC 需清残留网络**、**IO8/IO9 不得外挂上下拉**
2. **删除** CH340N 及其外围、R2、R8/R9、J4、IO2 拨动开关（§3.1）
3. **USB 网络改向**：USB-C D+/D- 直接接模组 IO12/IO13（§5.1）
4. **补/改电池分压**：R12/R13/C21 接到 IO2（§5.2）
5. **按键重接**：SW1（侧按键）→ EN、SW2（侧按键）→ IO3 + 10k 上拉（§4）
6. **删除 J3**，背面新增 BAT+/BAT- 焊盘，按 §5.4 布置电芯区（避开天线净空）
7. **新增 VBUS 检测**（VBUS→100k→IO18→100k→GND + 100nF，§5.3），并**按最终电芯容量调整 R3**（§5.4）
8. 按 §5.5/§5.6 核对板尺寸、**板厚 0.6mm**、**无安装孔**三项，再按 §6 完成布局与净空，跑 ERC/DRC，导出制造文件
9. **（V2.1）新增温湿度检测**：按 §5.7 放置 U7、R16/R17、C23；I2C 走 IO0/IO1；U7 靠板边、周围稀疏铺铜、远离开关电源与充电回路；同步在结构件上留透气孔（§5.7）
10. 样机回来后按下述顺序验证：USB 直连烧录（免按键）→ 电池分压电压（≈VBAT/2）→ VBUS 检测电平 → **温湿度 I2C 读数（温度≈室温、湿度合理）** → 充电电流与 LED → 按键短按刷新/长按重置

---

## 十、待确认事项（请贵方答复或标注）

**已确认（需求方答复，设计方照此执行）**
1. ✅ **D1/D2 充电指示 LED 保留**，行为与现在一致（充电中红、充满绿）
2. ✅ **增加 USB VBUS 检测**（§5.3），与本版电量显示配合实现"供电来源 + 电池电量"
3. ✅ **取消 PH2.0 插座**，电芯极耳直接焊在 PCB 上；**电芯位置改为夹在屏与 PCB 之间**（§5.5）
4. ✅ **SW1、SW2 两个按键都做实体键**（§4）
5. ✅ **整机堆叠：屏朝外 → 电芯 → PCB（元件面朝背面）**（§5.5）
6. ✅ 电芯走"**减薄 + 面积做满**"路线，**厚度 ≤4mm**（§5.4）

7. ✅ **接受"屏外尾部区"**：板尺寸定为 **67×28mm**（屏区 59.2 + 尾部 8），USB-C 放尾部区
8. ✅ **电芯厚度 ≤4mm**（容量 450–620mAh，见 §5.4）

9. ✅ **两个按键改为侧按式**（从卡片侧边按，型号见 §4）
10. ✅ **外壳条件不纳入本版约束**：设计方无须等待外壳资料、无须做外壳干涉核对
11. ✅ **HT7333 保留不换**，3.3V 侧加强储能电容（见 §3.3）
12. ✅ **板厚 0.6mm、板面不设安装孔**（双面胶/泡棉胶固定）

**需设计方反馈（不影响开工，出图后一并答复）**
- 所选侧按键的**具体型号与尺寸**（需求方据此确认手感与采购）
- 电芯容量最终档：**现货 402550（4×25×50，450mAh）** 还是 **定制 4×27×52（≈560–620mAh）**——请给交期与单价
- 若 0.6mm 板影响 USB-C 座焊接强度，请提出**加强做法**（加大焊盘/补强），不要改回 1.6mm

- **【V2.2 待需求方提供】正面外观件资料**：**尺寸/厚度/开窗（显示窗 + 透气孔）/拉丝方向/阳极颜色**，以及**是否含磁吸件**。用于与天线净空区做干涉核对（§5.5 第 4 条）。**资料未到前**，天线净空区按"正对区域全避让"出图，并在图纸/丝印上标出**天线禁布区边界**，便于结构件对齐。**材料按"拉丝铝 + 阳极氧化"准备**（不建议铁/碳钢）。
- **【V2.2 已更新成本口径】**墨水屏按 **¥9（需求方给定）** 计入；详见《BOM锁定表-V2.2》。**请确认该 ¥9 屏是"黑白双色"还是"红黑白三色"**——两者 **FPC 针数可能不同**，且影响固件是否使用红色。

**⚠️ 出图前必须先闭环的红线项（不闭环不许打样）**

- **FPC 针数/间距/金手指朝向核对**：V1 图纸用的是 **FPC-26P**；本版选定的屏为 **GDEY0213Z98**，而现役实机面板是 **QYEG0213RYF661**。三者（图纸 ↔ 屏厂规格书 ↔ 实机来料）**必须逐一核对一致**。请设计方**在打样前向屏厂索取该型号的 FPC 定义图**并与图纸比对，把结论写回文件——**此项不一致会导致整批屏装不上**。

**V2.1 需设计方反馈**
- 温湿度传感器选型确认：**按 AHT20 出图**（推荐，¥2.68/片 @1000pcs 级），还是改 **SHT40/SHT41**（±1.8%RH、测量 8.3ms，约 ¥6.5/片，**封装不同需另开一版**）？
- **外壳透气方案**：设计方是否同步负责开孔？孔径/膜方案请给建议——**密封壳体内测湿度无效，此项为硬要求**
- IO0/IO1 改用 I2C 后，贵方原计划的测试盘是否受影响？若不便请提出，改用 IO22/IO23（需双方同步确认）
- **【V2.2 待需求方最终确认】屏是否由"三色"改"黑白双色"？** 可再省 **¥8–13/台**，并换来**局部刷新**（更快、更省电）；代价是丢掉红色强调显示。**未确认前，设计方按现有"三色 + FPC 定义"出图**，但**请把 FPC 座的选型留到最后确认**（针数可能不同）。
- **【V2.2 待设计方确认】C3 引脚重排后**，请回报：①USB 走线已改到脚 26/27；②脚 15/17/24/25 无残留网络；③IO8/IO9 仅作输出、**无任何外挂上下拉**；④电量采样已到 IO4（ADC1_CH4）。
- **【待需求方决定，不在本版出图范围】是否预留一个环境光/UV 传感器位？** 保存场景里"褪色"的主因之一是**直射光与 UV**，若后续做"被晒到提醒"，**本期留位成本最低**（1 路 I2C 从机位，可与 U7 共总线，或用一个普通 GPIO）。**不预留则本期按不加处理**，请贵方在图中预留一个 0603/DFN 空位即可（是否贴件由需求方决定）

**关于 HT7333（第 6 项的区别说明）**
- HT7333-A：3.3V、额定输出 **150mA 级**（部分渠道标 250mA）、**静态电流低（µA 级）**，但**额定电流远低于 Wi-Fi 发射瞬态峰值**
- 500mA 级替代品的差别在三个指标上互相拉扯：
  - **TPS77x33 类**：500mA、压差 169mV@500mA，但 **Iq ≈ 92µA** → 直接打破 deep sleep <20µA 的目标，**不可用**
  - **ME6211 类**：500mA，Iq ≈ 40µA → 同样超预算
  - **TPS7A02 类**：Iq 仅 25nA，但只有 200mA，且压差 270mV(max)@200mA → 电池 3.4V 时输出不足 3.3V，**压差不够**
- **结论（建议）**：本版**保持 HT7333 不变**，把 3.3V 侧储能做足（模组旁 100µF 低 ESR + 10µF + 100nF），用容性储能顶住 Wi-Fi 发射的毫秒级峰值——这与现版做法一致，C3 的峰值电流与 C6/WROOM-32 同量级，**不会比现在更差**。若样机实测出现发射瞬间掉线/复位，再改 **TPS63802 类 buck-boost（2A、Iq ≈11µA）** 根治（需加电感，增加面积与成本）。

---

## 十一、参考文档（新增）

- **ESP32-C3-MINI-1 数据手册（本版采用）**：Table 3-1 引脚定义、Table 4-1/4-3 strapping 与启动模式、ADC1 = GPIO0–GPIO4、USB = GPIO18/19
- ESP32-C6-MINI-1 / C6 系列数据手册（**仅作 V2.1 沿革对照，本版不采用**）
- V1 文件：《ESP32 墨水屏胸牌 PCB 设计外包需求》
- **AHT20 规格书**（广州奥松）：测量时间 80ms、上电等待 40ms、建议 ≥2s 测一次、**要求外壳通风与铺铜稀疏**
- **Sensirion SHT4x 规格书**（可选方案）：高重复率测量 **−6.9/+8.3 ms**
- **GoodDisplay GDEY0213Z98** 面板规格（本机所用 2.13" 三色屏，控制器 SSD1680）
- **ESP32-C3-MINI-1 数据手册**（Table 3-1 引脚定义、Table 4-1/4-3 strapping 与启动模式、ADC1 = GPIO0–GPIO4、USB = GPIO18/19）

---
*本说明由需求方出具；如与 V1 冲突，以本说明为准。*

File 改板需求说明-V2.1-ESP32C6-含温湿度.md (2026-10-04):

# ESP32 墨水屏胸牌 —— PCB 改板需求说明（V2.1 · 增补温湿度检测）

> **文件性质**：本文件是在《ESP32 墨水屏胸牌 PCB 设计外包需求（V1）》基础上的**变更说明**。
> 未提到的内容**沿用 V1**；凡与本文件冲突处，**以本文件为准**。
> 适用对象：PCB 设计外包方。变更原因栏为实测/原理依据，可据此判断改动的必要性。
>
> **V2.1 说明（本次增补）**：在 V2 已定稿的 C6 改板方案上，**新增板载温湿度检测**（I2C 数字传感器，占用 2 个 GPIO 与约 15mm² 板面）。
> 除本文件标注 V2.1 的条款外，**其余一切沿用 V2**；V2 与 V2.1 冲突处，以 V2.1 为准。
>
> **器件选型以附件《BOM锁定表-V2.1》为准**（需求方出具，与本文同等效力；两文件冲突处以 BOM 锁定表为准）。
> 锁定件必须照单采购；参数锁定件可等效替代，但**替代须经需求方书面同意**。

---

## 一、变更摘要（一句话）

主控由 **经典 ESP32-WROOM-32D + CH340N USB 转串口桥片**，更换为 **ESP32-C6-MINI-1-N4（自带 PCB 天线、原生 USB、4MB Flash）**；随之**删除 USB 转串口电路、手动烧录按键与拨动开关**，**修正电池电量采样电路**，并**重新定义两个按键的功能**。

**V2.1 新增一句话**：在尾部区/板边**加一颗 I2C 温湿度传感器**（U7），配 **2×10kΩ 上拉 + 100nF 去耦**，接 **IO0(SDA)/IO1(SCL)**；并在**外壳对应位置留透气孔**（结构件要求，见 §5.7 末）。

**本文件的使用方式**：你们（设计方）已交付并制作过 V1 板，本文件即**在你们那版 V1 基础上的改板制造说明**——请按"三、器件变更总表"逐项增删改，未提及处一律沿用 V1 画法与你们既有的工艺。有冲突处以本文件为准。

**机械结论（本版已定）**：板 **67 × 28 mm**（屏区 + 8mm 尾部区）；堆叠为 **屏朝外 → 电芯 → PCB（元件面朝卡片背面）**；电芯 **≤4mm 厚**；USB-C 与两个侧按键布置在**屏外尾部区**；**板厚 0.6mm、不设安装孔**，整机总厚 **≈9.1–9.6mm**。详见 §5.5。**V2.1 增补**：温湿度传感器置于**尾部区靠板边**（高度 ≤1.0mm，**不影响总厚**），外壳需在该位置留透气孔（§5.7）。

---

## 二、变更原因（实测依据，供理解改动必要性）

| 序号 | 问题 | 实测/原理 |
|---|---|---|
| 1 | 烧录必须手动拨开关进下载模式 | 板上 **CH340N 是 SOP-8 精简版，只有 UART+RTS，没有 DTR**；ESP32 自动下载时序必须同时用 DTR 和 RTS，因此这版硬件**做不出自动下载**。另外该拨动开关接在 **IO2**（strapping 脚）上，上电拉低会影响启动/下载判定，属隐患 |
| 2 | 换 C6 后是否还会卡在烧录 | C6 具备**片内 USB-Serial/JTAG**，由 ROM 控制：常规烧录**不需要任何按键**，固件损坏也仍可恢复（砖了能救） |
| 3 | 16MB Flash 是否必要 | 用本项目固件实测编译：**经典 ESP32 = 1,355,704 B；ESP32-C6 = 1,353,644 B**（约 1.29MB）。**4MB Flash 足够**，原 16MB 要求取消 |
| 4 | 电池电量显示无效 | 实测：**采样脚直连 VBAT，满电时 ADC 饱和（raw=4095、≈3.14V）**；图纸标注的 GPIO34 分压点**无信号**。直连 4.2V 超出 ADC 量程，且经输入 ESD 二极管向 3.3V 轨漏电、影响待机功耗。**必须补分压并固定采样脚** |
| 5 | 体积/成本 | 模组面积由 18.0×25.5 = **459mm²** 降至 13.2×16.6 = **219mm²**（**-52%**），厚度 3.1→**2.4mm**；删除器件再省约 **165mm²** |
| **6（V2.1）** | **新增温湿度检测的代价** | **固件侧已实测**：同一 C6 目标用 `arduino-cli` 真编对比，加自写最小 I2C 驱动后 **Flash +1,086 B（1.06 KB）**、**常驻 RAM +16 B**（基线 1,327,460 B / 55,876 B）→ 3MB app 槽里占 **0.03%**，**空间上可忽略** |
| **7（V2.1）** | **检测一次要多久（会不会拖慢每日刷新）** | 传感器**自身测量时间**：AHT20 **80 ms**（规格书原文「Wait for 80ms…」）、SHT4x **8.3 ms**（Sensirion 规格书 −6.9/+8.3 ms）；**I2C 传输**在 100kHz 下 10 字节 ≈ **0.9 ms** → **单次合计 9–81 ms**。相对一次唤醒刷新的主耗时（Wi-Fi 连接 + 取价 + 三色墨水屏全刷，**秒级~十几秒级**）占 **0.05%–0.4%**，**完全可并入每日启动刷新，无感知** |

---

## 三、器件变更总表

### 3.1 删除项（V1 位号）

| 位号 | 器件 | 处理 | 原因 |
|---|---|---|---|
| U6 | CH340N USB 转串口 | **删除** | C6 使用原生 USB，不需要桥片 |
| R8, R9 | 1kΩ（TX/RX 串阻） | **删除** | 随 CH340N 一并废弃 |
| J4 | 排针 2×3 2.54mm（烧录口） | **删除** | USB-C 直连即可烧录/调试，无需排针 |
| C（CH340 相关） | CH340 的 V3/VCC 去耦 | **删除** | 随 U6 删除（具体位号由设计方在网表中识别） |
| SW（IO2 拨动开关） | 调试模式拨动开关 | **删除** | 功能移入固件；且 IO2 为 strapping 脚，不可外挂开关 |
| R2 | 10kΩ（IO0 上拉） | **删除** | BOOT 按键取消，上拉一并废弃 |
| **J3** | **PH2.0 电池插座** | **删除** | 本版改为**电芯极耳直接焊在 PCB 背面**，PCB 上新增 B+/B- 焊接焊盘（见 §5.4） |

### 3.2 替换项

| 位号 | 原 | 新 | 说明 |
|---|----|----|---|
| U1 | ESP32-WROOM-32D（18.0×25.5×3.1） | **ESP32-C6-MINI-1-N4**（13.2×16.6×2.4，自带 PCB 天线，4MB Flash） | 焊盘与 ESP32-C3-MINI-1 **pin-to-pin 兼容**，便于后续互换/防缺货。**注意选型：必须选 `ESP32-C6-MINI-1`（PCB 天线版），不要 -1U（外置天线版）** |

### 3.3 保留项（不要动）

- EN 上拉 **R1(10k) + C10(100nF)**（EN 脚不可悬空，模组数据手册明确要求）
- 电源路径 **D3/D4（SS14）**、**FB1**、**HT7333（U2）**：**本版确认保留、不更换**（需求方决定：不换 LDO、不加 buck-boost）。请在 3.3V 侧加强储能——模组旁 **100µF 低 ESR + 10µF + 100nF**，用于顶住 Wi-Fi 发射的毫秒级峰值电流
- 充电与保护 **TP4056(U3) / DW01A(U4) / 8205A(U5)** 及**指示 LED D1/D2（保留，行为与现在一致：充电中红灯亮、充满绿灯亮）**
  - 请确保 U3 的 **CHRG → R4 → D1**、**STDBY → R5 → D2** 两条支路连线完整（按 V1 §4.2），否则指示灯不亮
- **USB-C（J1）及 CC 5.1k×2 下拉、USB ESD 保护**（USB-C 供电必需，切勿删）
- **墨水屏 FPC（J2）及其 SPI 网络**
- **板载电池保护（DW01A+8205A）继续使用**：因取消 PH2.0 插座、电芯直接焊接，过充/过放/短路保护必须依靠板载保护电路，不可省略
- 电池分压 **R12/R13（100kΩ）+ C21(100nF)**（见 §5.2，仅接线改向）

### 3.4 新增项（V2.1）

| 位号 | 器件 | 规格 | 说明 |
|---|---|---|---|
| **U7** | **温湿度传感器（I2C）** | **AHT20**（DFN-4，3.0×3.0×1.0mm，广州奥松，地址 **0x38**） | **本版按 AHT20 出图**。如需更高精度（±1.8%RH/±0.2℃、测量 8.3ms）可改 **Sensirion SHT40/SHT41**（1.5×1.5mm，地址 0x44），但**封装与走线需另开一版**，请先与需求方确认 |
| **R16、R17** | I2C 上拉电阻 | **10kΩ 1%（0402）**，上拉到 **3.3V** | 缺上拉会导致 I2C 完全不通（这是最常见的返工原因，务必装） |
| **C23** | 去耦电容 | **100nF（0402）** | 靠近 U7 的 VDD 脚（≤2mm） |

- 总线速率按 **100 kHz** 出图（本产品一天只读一次，无需 400kHz）
- U7 供电直接挂 **3.3V 常供**：AHT20 待机约 **0.25µA**，对整机日均耗电（1–6 mAh/天）**无影响**，因此**不需要**做 GPIO 供电门控（少两颗器件、少一处失效点）
- **封装高度 1.0mm**，低于屏区最高件（FPC 座 2.0mm）→ **不改变整机总厚**

> **U7 与整份 BOM 的选型依据见附件《BOM锁定表-V2.1》**：U7 锁定 **AHT20（立创 C2757850）**；
> 若要换 Sensirion SHT40/SHT41（封装不同）**必须另开一版并书面通知需求方**；
> **不接受** DHT11/DHT22 等单总线器件替代（待机 50–60µA，超出本产品日均耗电预算）。

---

## 四、按键与用户交互（重新定义，重要）

V1 中的"SW1-SW2 = RST/BOOT"作废。新定义如下（两个键都保留，**均为侧按式**）：

| 位号 | 功能 | 连接 | 说明 |
|---|---|---|---|
| **SW1** | **复位（实体键）** | **EN** → SW1 → GND（保留 R1 10k 上拉、C10 100nF） | **本版按实体按键出图**；硬件复位，也是固件卡死/深睡时唯一的恢复手段 |
| **SW2** | **功能键** | **IO3** → SW2 → GND，配 **10kΩ 外部上拉**（R10），可选并联 100nF 去抖 | 低电平有效；详见下方功能定义 |

**SW2 功能定义（固件侧实现）**
- **短按（<1s）**：立即刷新——取价 + 重刷墨水屏
- **长按 ≥5s**：进入配网模式——清除 Wi-Fi 配置并开启 AP 热点（手机连接配网）
- **长按 ≥15s**（可选档，建议保留）：恢复出厂设置（清除全部配置）

**按键选型与结构（本版全部改为「侧按式」，需求方已确认）**
- **SW1、SW2 都改用"侧按式"贴片轻触开关**：作动方向**平行于板面**、从卡片**侧边**按压；开关贴板边安装，按钮端突出板边约 **0.3–1.0mm**
- 可选型号（三选一，或由设计方提供等效件并注明型号）：
  | 型号 | 尺寸 | 关键参数 |
  |------|------|---------|
  | **Panasonic EVQ-P7A01P 类** | 3.5 × 2.9mm，安装高度 1.35mm | 侧按、约 220gf、回流焊，通用性最好 |
  | Panasonic EVP-AK 系列 | 3.8 × 1.9mm | 行程 0.12mm，寿命可达 500,000 次（最薄） |
  | 国产等效（2×4mm / 2.3×2.95mm 卧式贴片侧按键） | 约 2×4mm | 成本更低、交期更快 |
- 共同要求：**操作力 160–250gf**、**寿命 ≥100,000 次（推荐 200,000+）**、回流焊、RoHS
- **位置**：放在**屏外尾部区的侧边**（见 §5.5/§5.6），两键中心距 ≥6mm 防连按；避开墨水屏 FPC 弯折区与电芯位置
- **按键位置**：置于尾部区板边、作动方向朝板外；机械按压通道由需求方后续处理（见 §5.6）
- 建议按键两侧加小电容/TVS 抗 ESD（人手接触）
- 仍建议在 EN/GND 旁并两个测试盘（产线复位用，与 SW1 并联）

**技术约束（务必遵守，否则按键唤不醒芯片）**
- 功能键必须接在 **RTC/LP GPIO（IO0–IO7 之一）**，才支持深睡中被按键唤醒；本方案选 **IO3**
- **禁止**将按键接在 strapping 脚 **IO4、IO5、IO8、IO9、IO15** 上
- **IO8、IO9 必须保持默认（不外挂上拉/下拉）**——它们决定启动模式；**IO15 也不得外挂上下拉**（决定 JTAG 信号源，默认即片内 USB）

---

## 五、原理图连线变更（Pin-to-Pin，请按此重连）

### 5.1 主控引脚映射（ESP32-C6-MINI-1）

| 功能 | 模组脚号 | GPIO | 备注 |
|---|---|---|---|
| EPD_SCLK | 15 | **IO6** | 使用默认 FSPICLK，信号完整性最佳 |
| EPD_MOSI | 16 | **IO7** | 使用默认 FSPID（SPI 主机输出） |
| EPD_CS | 19 | **IO14** | 普通 GPIO（软件片选） |
| EPD_DC | 25 | **IO19** | 普通 GPIO |
| EPD_RST | 26 | **IO20** | 普通 GPIO |
| EPD_BSY | 27 | **IO21** | 普通 GPIO，输入 |
| VBAT_SENSE | 5 | **IO2** | ADC1_CH2；见 §5.2 分压要求 |
| USER_BTN（SW2） | 6 | **IO3** | LP_GPIO3，支持深睡唤醒；10k 上拉 + 按下接地（见 §4） |
| **TH_SDA（V2.1 新增）** | **12** | **IO0** | 温湿度传感器 I2C 数据；**10k 上拉到 3.3V**（R16） |
| **TH_SCL（V2.1 新增）** | **13** | **IO1** | 温湿度传感器 I2C 时钟；**10k 上拉到 3.3V**（R17） |
| **VBUS_DET（新增）** | 24 | **IO18** | USB 供电检测；见 §5.3 |
| **BAT+ / BAT-** | — | — | 电芯极耳焊接焊盘（新增，见 §5.4） |
| EN（SW1 复位） | 8 | EN | R1 10k 上拉 + C10 100nF 到 GND，不可悬空 |
| USB_D- | 17 | IO12 | 直连 USB-C D- |
| USB_D+ | 18 | IO13 | 直连 USB-C D+ |
| 3V3 | 3 | 3V3 | 加 10µF + 100nF 去耦 |
| GND | 1、2、11、14、36–53 | GND | 全部接地 |
| 备用（建议留测试盘） | 9、10、20、22、23、28、29、30、31 | IO4、IO5、IO15、IO8、IO9、IO22、IO23、RXD0(IO17)、TXD0(IO16) | 留测试盘；**IO8/IO9/IO15 不得外挂上下拉**；TXD0/RXD0 保留为备用串口日志口。**注意：IO0/IO1 自 V2.1 起被温湿度 I2C 占用**，如需更多备用脚请与需求方确认 |
| **EN 复位（测试盘）** | 8 | EN | 见 §4：以 **EN + GND 两个测试盘**实现（推荐），或按贵方结构改为实体键 |

**说明**：`USB_D+/D-` 在 V1 中是接到 CH340 的，现**直接接 USB-C 的 D+/D-**；V1 §4.6 的连线作废。

**补充**：IO6/IO7 也是引脚级 JTAG（MTCK/MTDO）的默认位置。本方案使用片内 USB-Serial/JTAG，不影响 SPI 功能；**若贵方希望保留引脚级 JTAG 调试能力，可将 EPD_SCLK/EPD_MOSI 改用 IO22/IO23**（其余不变），或与需求方确认后调整。IO2/IO4/IO5/IO6/IO7 同时是 LP_I2C/FSPI 复用脚，作为普通 GPIO 使用没有问题。

### 5.2 电池电量采样（必须修正，V1 §4.7 作废）

```
VBAT(电池正极) ── R12(100kΩ) ──┬── VBAT_SENSE ── ESP32-C6 IO2 (脚 5, ADC1_CH2)
                               │
                            C21(100nF)
                               │
                            R13(100kΩ)
                               │
                              GND
```

- 分压比 **2:1**（4.2V → 2.1V，落在 ADC 量程内）
- **禁止把 VBAT 直接接到任何 GPIO**（V1 当前的实测问题即由此产生）
- 采样节点（IO2）到 GND 之间加 **100nF** 滤波
- **可选优化（建议）**：在 R12 前串一个高边 P-MOS 开关，仅在测量瞬间导通，可把分压常耗电流从约 21µA 降到 0（对深睡电流目标有意义）

### 5.3 USB 供电检测（新增，V1 无此电路）

现状说明：**V1 及目前实物均没有 USB 检测电路**（固件注释明确写着 "No USB-present signal is wired"），现在界面上的"USB/未接电池"只是固件在 ADC 读数无效时的兜底文案，并非真实检测。

```
USB-C VBUS(5V) ── R14(100kΩ) ──┬── VBUS_DET ── ESP32-C6 IO18 (脚 24)
                               │
                            C22(100nF)
                               │
                            R15(100kΩ)
                               │
                              GND
```

- 分压比 2:1（5V → 2.5V），插 USB 时 IO18 读到高电平，固件据此显示"USB 供电 / 充电中"
- **该分压接在 VBUS 侧，不插 USB 时不通电，不会消耗电池**（与 §5.2 的电池分压不同）
- 保留 §5.2 的电池分压，两者配合即可实现"供电来源 + 电池电量"同时显示

### 5.4 电池：取消插座，改为背贴焊接（本版变更）

**取消 J3（PH2.0 插座）**，电芯极耳直接焊到 PCB 背面焊盘。要求：

1. **新增焊盘**：BAT+ / BAT- 两个焊盘，位置与所选电芯极耳位置对应；丝印标注极性（B+/B-），**极性标反会烧板，务必双人复核**
2. **电芯必须带焊片/镍带（Tab）**，不接受裸极耳；焊接工艺：烙铁 ≤350℃、单点 ≤3s、焊点离电芯本体 ≥2mm，焊后用硅胶/UV 胶加固
3. **背面电池区域**：不得有过孔、不得有裸露走线（防刺穿短路）；电芯与 PCB 之间垫绝缘片（青稞纸/PET）
4. **必须避开模组天线净空区**：电芯不得压在天线正下方及其前方净空区内（见 §6）
5. 四周留 **0.5mm** 膨胀余量，厚度方向留 **1mm**；电芯与板边平行放置

**电芯选型（依 §5.5 堆叠：电芯夹在墨水屏与 PCB 之间；已锁定厚度 ≤4mm）**

| 方案 | 尺寸（厚×宽×长 mm） | 标称容量 | 说明 |
|---|---|---|---|
| 标准现货（推荐先打样用） | **402550：4×25×50** | **450mAh** | 现货可买，长度 50mm ≤ 可用 52mm ✓ |
| 标准现货（备选） | 402540：4×25×40 | 400–420mAh | 更短，容量略小 |
| 定制（量产最优） | **4×27×52** | **约 560–620mAh** | 面积做满；软包按尺寸裁切，一般 MOQ 500–1000 |

**可用电芯区**（板 67×28，见 §5.5）：**约 52 × 27 mm**

**续航估算**（可用容量按 80%、自放电 2%/月计；"不刷屏"= 价格未变化时跳过墨水屏刷新）

| 电芯 | 60 分钟唤醒 | 60min + 不刷屏 | 120 分钟唤醒 | 120min + 不刷屏 |
|---|---|---|---|---|
| 402540（420mAh） | 41 天 | 58 天 | 77 天 | 108 天 |
| **402550（450mAh）** | **43 天** | **62 天** | **82 天** | **115 天** |
| 定制 4mm（600mAh） | 57 天 | 81 天 | 107 天 | 148 天 |
| 定制 4mm（620mAh） | 59 天 | 84 天 | 110 天 | 153 天 |

> 说明：4mm 厚度下容量由**面积**决定，因此定制 27×52 比标准 25×50 多约 30% 容量。若续航不满意，最有效的杠杆是**延长唤醒周期**（60→120 分钟几乎翻倍）与**价格未变不刷屏**，而不是加厚电芯。

### 5.5 整机堆叠与厚度（本版新增，决定性章节）

**堆叠顺序（由外到内）**

```
[卡片正面] 墨水屏（屏幕朝外）
              ↓
           电芯（夹在屏与板之间，可用约 55×27mm）
              ↓
           PCB（元件面朝卡片背面：模组、USB-C、按键、电源）
              ↓
[卡片背面] 背壳（塑料，需留按键按点与 USB 开孔）
```

**射频判断**：该堆叠下模组的 PCB 天线位于**元件面**，朝卡片背面辐射；屏与电芯都在板的另一侧，不再挡在天线正前方 → **射频环境比"屏盖板"方案好得多，方向性判断成立**。但仍须遵守三条：

1. **天线净空区必须全层无铜**（天线下方、模组投影区内，板的正反两面都不铺铜、不走线）——这条与堆叠无关，是硬要求；
2. **电芯的投影不要压在天线正上方**：虽然电芯在板的另一侧，但大面积金属膜仍会失谐 → 建议电芯与天线区间隔 **≥5mm**；
3. **背壳必须是塑料（非金属）**，背面不得贴金属标牌、铝箔、NFC 金属贴等；装配后**必须实测 RSSI 与连接距离**（不能只看理论）。

**厚度账（分区域取最大值，单位 mm）**

厚度**不是各层相加**，而是"屏区"与"尾部区"各自计算后**取较大值**（模组、USB-C 都在尾部区，不与屏/电芯叠加）：

- **屏区** = 屏 1.05 + 屏胶 0.2 + 电芯 T + 缓冲 0.3 + **PCB** + 屏区最高元件 + 背壳内隙 0.4 + 背壳 0.6
- **尾部区** = PCB + 模组 2.4 + 背壳内隙 0.4 + 背壳 0.6 + 前壳 0.6 ≈ 4.6（**不是瓶颈**）

| PCB 厚度 | 电芯 3.0mm | 电芯 3.5mm | 电芯 4.0mm |
|---|---|---|---|
| **0.6mm（推荐）** | ≈8.6 | ≈9.1 | **≈9.6** |
| 0.8mm | ≈8.8 | ≈9.3 | ≈9.8 |

（屏区最高元件按 FPC 座 2.0mm 计；若屏区元件压到 1.5mm，可整体再减 0.5mm）

**✅ 本版已确定的机械配置**

| 项目 | 取值 |
|---|---|
| 板子尺寸 | **67 × 28 mm**（屏区 59.2 + 尾部区 8） |
| **板厚** | **0.6mm（推荐）**，可选 0.8mm |
| **安装孔** | **不设安装孔/定位孔**（板在壳内以双面胶/泡棉胶固定） |
| USB-C 位置 | 屏外尾部区（不在屏下 → 3.2mm 不计入总厚） |
| 电芯 | 厚度 **≤4mm**，面积约 52×27mm（见 §5.4） |
| 整机总厚 | **≈9.1–9.6mm**（0.6mm 板 + 4mm 电芯） |

**尾部区（8mm）建议布置**：模组（天线朝卡片外端）+ USB-C（与模组并排于短边）+ 两个侧按键；屏的 FPC 座放在屏区外侧短边。

**再减薄的空间（可选）**：电芯 3.5mm → -0.5；屏区最高元件压到 1.5mm → -0.5；缓冲 0.3→0.2、背壳 0.6→0.5 → 各 -0.1。

**结构要求**
- 电芯四周留 **0.5mm**、厚度方向留 **1mm** 膨胀空间；电芯与屏之间加 **0.2–0.3mm** 缓冲垫（防压屏）
- 电芯极耳/镍带走向与 PCB 焊盘对齐（见 §5.4），**不得跨过 FPC 弯折区**
- **板子固定方式**：双面胶/0.5mm 泡棉胶贴装（3M 200MP 类）→ 因此**板面不设螺丝孔与定位孔**
- **0.6mm 板注意**：USB-C 座的焊接强度会下降，请加大固定焊盘/加锡量或做局部补强（**不要因此改回 1.6mm**）

### 5.6 结构固定与按键通道（与外壳解耦）

- **本版不与外壳/开孔绑定**：设计方按 §5.5 的板尺寸与堆叠出图即可，**无需等待外壳资料，也不必做外壳干涉核对**
- **板子不设安装孔**：靠双面胶/泡棉胶固定在壳内（省下孔位及周围禁布区约 40–120mm²，也省掉螺丝高度）
- **两个侧按键**：位于板边、作动方向朝板外、按钮端突出板边 **0.3–1.0mm**；机械按压通道由需求方后续与外壳方案一并处理。设计方只需保证：位于**尾部区侧边**、两键中心距 ≥6mm、不与电芯/FPC 冲突、丝印标注功能（SW1 复位 / SW2 短按刷新·长按重置）
- **屏与板的相对定位**由电芯缓冲垫与胶带保证；屏 59.2mm 与板 67mm 的 8mm 差值即尾部区

### 5.7 温湿度检测（V2.1 新增）

**电路（请按此连线）**

```
3V3 ── R16(10kΩ) ──┬── TH_SDA ── ESP32-C6 IO0 (脚 12)
                   └── U7 SDA (AHT20 pin 1)

3V3 ── R17(10kΩ) ──┬── TH_SCL ── ESP32-C6 IO1 (脚 13)
                   └── U7 SCL (AHT20 pin 2)

3V3 ──┬── U7 VDD (pin 4)
      └── C23(100nF) ── GND

U7 GND (pin 3) ── GND
```

- **R16/R17 必须装**（10kΩ 上拉到 3.3V）；AHT20 地址固定 **0x38**，无需地址配置
- **禁止**把 I2C 改到 **IO4/IO5/IO8/IO9/IO15**——这些是 strapping 脚，**不允许外挂上拉电阻**
- 若贵方布局上 IO0/IO1 不便，可改用 **IO22/IO23**（同为普通 GPIO，非 strapping），但需在文件与丝印中同步修改，并通知需求方（固件要跟着改）

**布局要求（有 datasheet 依据，请照做）**

1. **传感器下方与四周尽量少铺铜**：AHT20 规格书明确要求「保持外壳良好通风，AHT20 与板面其他部分的铺铜应尽可能小，或在两者之间留出间隙」——IO0/IO1 与 U7 周围做**禁铺铜/稀疏地**，U7 与 3.3V 地铜之间留 ≥1mm 间隙
2. **远离热源**：U7 距 ESP32 模组、TP4056、HT7333、充电回路及 USB-C 至少 **10mm**（充电/LDO/模组发热会直接抬高温度读数）；**不要放**在模组投影区与电源入口附近
3. **U7 尽量靠板边**，与外壳的透气开孔对齐（见下）；远离开水（FPC 弯折区）与电芯投影区
4. I2C 两根线**短而平行、不跨分割、不加长分支**；时钟线与 SPI/USB 差分线保持间距
5. 传感器位置**不需要**做元件面/焊接面特殊处理，按常规 SMT 贴装（DFN-4，回流焊）

**结构要求（本版明确）**

- **外壳必须在传感器位置留透气通道**：小孔（建议 **≥φ1.5mm** 或等效面积缝隙）或**防水透气膜（Gore 类）**；**完全密封的壳体内测出的湿度是壳体内部值，毫无意义**——这是本项目对结构的**硬要求**
- 传感器**不得被电芯、屏、胶带覆盖**；感湿面朝向外壳开孔方向
- 若无开孔空间，需**提前反馈**，由需求方调整结构方案（不要默认按密封做）

**产品用途与由此产生的硬要求（V2.1 补充，务必按此执行）**

本产品的温湿度功能**面向卡牌/球星卡收藏的保存环境监测**（不是消费级"室内舒适度"），因此下面几条**是产品功能的一部分，不是可选的优化项**：

1. **测点必须与壳体外部空气相通**：传感器感湿面**不得**被灌封胶、泡棉、双面胶、标签、结构件或电芯遮挡。产线**禁止在 U7 上点胶/覆膜**（这是最常见的返工点）
2. **透气通道加防水透气膜（Gore 类）或细密网**：既保证空气交换，又防止灰尘/水汽直接冲击感湿孔；**不得用密封胶堵孔**
3. **量程与精度要求**：0–100%RH、−20~+60℃ 级；**精度优于 ±2%RH / ±0.3℃**——这是为了能判读"目标区 40–50%RH"与"报警线 65%RH"。AHT20（±2%RH/±0.3℃）满足；若换用更差精度的器件，需求方不认可
4. **热源隔离量化（理由）**：U7 距模组/TP4056/HT7333/USB-C **≥10mm**。器件**自发热会同时抬高温度读数、拉低湿度读数**——这是"读数不可信"的主要原因，不是纯粹的理论担忧
5. **外壳材料限制（保存场景特有）**：外壳与壳内配件**不得使用 PVC 或含增塑剂塑料、木质/密度板(MDF)、普通纸板、酸性胶粘剂/泡棉**——它们会逸出乙酸/甲醛类污染物或使增塑剂迁移，对卡纸是长期损伤；建议 **PP / ABS / PC** 壳体 + **中性（无酸）双面胶**；**壳内不得贴酸性标签/纸卡**
6. **展示面（墨水屏/前框）不承担透气功能**：透气孔独立于显示区，避免影响外观与密封

---

## 六、布局与射频要求（更新 V1 §3.2）

1. **PCB 天线净空（重点）**：模组天线端应**伸出板边**；**天线区域及其正下方所有层不得铺铜、不得走线**；天线前方约 **15mm** 范围内不放置金属件/电池/大块铜箔；模组尽量远离电芯与大块金属。
2. **USB 差分线 D+/D-**：尽量短、等长、避免跨分割，串阻/ESD 器件靠近 USB-C。
3. **SPI（模组→墨水屏）走线尽量短**；EPD 的去耦电容靠近 FPC 座。
4. **ADC 分压（VBAT_SENSE）**远离 SPI、USB、充电电路等高频/大电流区域。
5. **充电电路**（TP4056）走线足够宽；D3/D4 靠近电源入口。
6. 模组下方地平面完整，模组四周多打地过孔（散热与射频回流）。
7. **电芯区（屏与板之间，见 §5.5）**：PCB 上该区域对应的走线/过孔允许（电芯不在 PCB 表面），但**丝印须标出电芯外形与极性**；电芯投影不得进入天线净空区，且与天线区间隔 ≥5mm。
8. **两个侧按键（SW1/SW2）**位于尾部区板边，丝印标注功能（SW1 复位 / SW2 短按刷新·长按重置）；**板面不设安装孔**。
9. **（V2.1）温湿度传感器 U7**：尾部区靠板边；周围**稀疏铺铜**、距热源 ≥10mm；I2C 上拉电阻（R16/R17）**靠近 U7** 放置；丝印标注 **U7 用途**与**感湿面朝向**（见 §5.7）

---

## 七、Flash 与分区要求（需求方固件侧负责，设计方仅需按此选型/留分区）

- **Flash 容量 4MB 即可**（实测固件 1.29MB）；选型后缀 **-N4**；如需 OTA 余量可选 -N8，但非必须
- 分区表必须包含：
  - `nvs` ≥ 20KB（设备配置、渲染指令、槽位参数）
  - **`fat`（FFat）分区 ≥ 64KB** —— 固件用 FFat 存放位图帧文件（约 8KB）。**若分区表中只有 spiffs 分区，FFat 将挂载失败**，请务必保留一个 `data, fat` 分区
  - `app` ≥ 2MB
- **注意**：Arduino 默认的 4MB 分区方案（app 槽仅 1.2MB）**装不下本固件**，请使用自定义分区表

---

## 八、交付物与验收标准（增补 V1 §3.3 / §七）

**交付物（在 V1 基础上补充）**
1. KiCad 7 原理图（已完成全量连线、ERC 通过）+ PDF
2. PCB 源文件 + Gerber（RS-274X）+ 钻孔（Excellon）+ BOM（Excel）+ 贴片坐标
3. **位号图/装配图**（标注 SW1/SW2 位置与功能）
4. BOM 中 U1 必须写**完整型号**（`ESP32-C6-MINI-1-N4`），且**整份 BOM 须与附件《BOM锁定表-V2.1》逐项一致**（位号、型号、品牌、封装、参数）；凡锁定件不得自行替换

**验收标准（新增/修改）**
1. ✅ 原理图 ERC 通过、PCB DRC 通过，所有网络连通
2. ✅ **天线区域净空检查通过**（天线区及正下方无铜、无走线）
3. ✅ **USB-C 直连电脑即可烧录，全程不需要按任何按键**
4. ✅ **电池分压输出实测**：满电时采样点电压 ≈ VBAT/2（约 2.1V），不得出现饱和
5. ✅ 两个侧按键按压力/手感正常（160–250gf），短按与长按均能被固件识别（电气验证由需求方固件侧完成）
6. ✅ 无电池时插 USB-C 系统可正常运行
7. ✅ 分区表含 fat 分区（见 §7）
8. ✅ **插 USB 时 VBUS_DET（IO18）读到高电平**，拔掉后为低电平
9. ✅ **充电电流按所选电芯的 0.5C 实测**（R3 按 §5.4 调整），充电中红灯亮、充满绿灯亮
10. ✅ 电池焊盘极性丝印正确、电芯可完整放入"屏与板之间"的位置且不压天线净空区
11. ✅ **两个侧按键按压力 160–250gf 手感正常**，按钮端突出板边 0.3–1.0mm
12. ✅ **板面无安装孔**；整机总厚按 §5.5 区域法计算 **≤9.6mm**（0.6mm 板 + 4mm 电芯）
13. ✅ **（V2.1）I2C 上拉电阻 R16/R17 已装**（10kΩ → 3.3V），且 U7 的 SDA/SCL 走线无断线、无短路
14. ✅ **（V2.1）U7 位置检查**：距模组/TP4056/HT7333/USB-C ≥10mm；U7 下方与四周铺铜已按要求稀疏化；丝印标注完整
15. ✅ **（V2.1）上电后固件读数合理**：温度接近室温、湿度在 20–80%RH 区间（不在密封壳内时的读数才算数；样机阶段可先不装壳验证）

---

## 九、改板步骤（建议顺序，供设计方参考）

1. 在 V1 工程中**替换 U1** 库符号/封装为 `ESP32-C6-MINI-1`（含 keepout 区），按 §5.1 重排全部网络
2. **删除** CH340N 及其外围、R2、R8/R9、J4、IO2 拨动开关（§3.1）
3. **USB 网络改向**：USB-C D+/D- 直接接模组 IO12/IO13（§5.1）
4. **补/改电池分压**：R12/R13/C21 接到 IO2（§5.2）
5. **按键重接**：SW1（侧按键）→ EN、SW2（侧按键）→ IO3 + 10k 上拉（§4）
6. **删除 J3**，背面新增 BAT+/BAT- 焊盘，按 §5.4 布置电芯区（避开天线净空）
7. **新增 VBUS 检测**（VBUS→100k→IO18→100k→GND + 100nF，§5.3），并**按最终电芯容量调整 R3**（§5.4）
8. 按 §5.5/§5.6 核对板尺寸、**板厚 0.6mm**、**无安装孔**三项，再按 §6 完成布局与净空，跑 ERC/DRC，导出制造文件
9. **（V2.1）新增温湿度检测**：按 §5.7 放置 U7、R16/R17、C23；I2C 走 IO0/IO1；U7 靠板边、周围稀疏铺铜、远离开关电源与充电回路；同步在结构件上留透气孔（§5.7）
10. 样机回来后按下述顺序验证：USB 直连烧录（免按键）→ 电池分压电压（≈VBAT/2）→ VBUS 检测电平 → **温湿度 I2C 读数（温度≈室温、湿度合理）** → 充电电流与 LED → 按键短按刷新/长按重置

---

## 十、待确认事项（请贵方答复或标注）

**已确认（需求方答复，设计方照此执行）**
1. ✅ **D1/D2 充电指示 LED 保留**，行为与现在一致（充电中红、充满绿）
2. ✅ **增加 USB VBUS 检测**（§5.3），与本版电量显示配合实现"供电来源 + 电池电量"
3. ✅ **取消 PH2.0 插座**，电芯极耳直接焊在 PCB 上；**电芯位置改为夹在屏与 PCB 之间**（§5.5）
4. ✅ **SW1、SW2 两个按键都做实体键**（§4）
5. ✅ **整机堆叠：屏朝外 → 电芯 → PCB（元件面朝背面）**（§5.5）
6. ✅ 电芯走"**减薄 + 面积做满**"路线，**厚度 ≤4mm**（§5.4）

7. ✅ **接受"屏外尾部区"**：板尺寸定为 **67×28mm**（屏区 59.2 + 尾部 8），USB-C 放尾部区
8. ✅ **电芯厚度 ≤4mm**（容量 450–620mAh，见 §5.4）

9. ✅ **两个按键改为侧按式**（从卡片侧边按，型号见 §4）
10. ✅ **外壳条件不纳入本版约束**：设计方无须等待外壳资料、无须做外壳干涉核对
11. ✅ **HT7333 保留不换**，3.3V 侧加强储能电容（见 §3.3）
12. ✅ **板厚 0.6mm、板面不设安装孔**（双面胶/泡棉胶固定）

**需设计方反馈（不影响开工，出图后一并答复）**
- 所选侧按键的**具体型号与尺寸**（需求方据此确认手感与采购）
- 电芯容量最终档：**现货 402550（4×25×50，450mAh）** 还是 **定制 4×27×52（≈560–620mAh）**——请给交期与单价
- 若 0.6mm 板影响 USB-C 座焊接强度，请提出**加强做法**（加大焊盘/补强），不要改回 1.6mm

**⚠️ 出图前必须先闭环的红线项（不闭环不许打样）**

- **FPC 针数/间距/金手指朝向核对**：V1 图纸用的是 **FPC-26P**；本版选定的屏为 **GDEY0213Z98**，而现役实机面板是 **QYEG0213RYF661**。三者（图纸 ↔ 屏厂规格书 ↔ 实机来料）**必须逐一核对一致**。请设计方**在打样前向屏厂索取该型号的 FPC 定义图**并与图纸比对，把结论写回文件——**此项不一致会导致整批屏装不上**。

**V2.1 需设计方反馈**
- 温湿度传感器选型确认：**按 AHT20 出图**（推荐，¥2.68/片 @1000pcs 级），还是改 **SHT40/SHT41**（±1.8%RH、测量 8.3ms，约 ¥6.5/片，**封装不同需另开一版**）？
- **外壳透气方案**：设计方是否同步负责开孔？孔径/膜方案请给建议——**密封壳体内测湿度无效，此项为硬要求**
- IO0/IO1 改用 I2C 后，贵方原计划的测试盘是否受影响？若不便请提出，改用 IO22/IO23（需双方同步确认）
- **【待需求方决定，不在本版出图范围】是否预留一个环境光/UV 传感器位？** 保存场景里"褪色"的主因之一是**直射光与 UV**，若后续做"被晒到提醒"，**本期留位成本最低**（1 路 I2C 从机位，可与 U7 共总线，或用一个普通 GPIO）。**不预留则本期按不加处理**，请贵方在图中预留一个 0603/DFN 空位即可（是否贴件由需求方决定）

**关于 HT7333（第 6 项的区别说明）**
- HT7333-A：3.3V、额定输出 **150mA 级**（部分渠道标 250mA）、**静态电流低（µA 级）**，但**额定电流远低于 Wi-Fi 发射瞬态峰值**
- 500mA 级替代品的差别在三个指标上互相拉扯：
  - **TPS77x33 类**：500mA、压差 169mV@500mA，但 **Iq ≈ 92µA** → 直接打破 deep sleep <20µA 的目标，**不可用**
  - **ME6211 类**：500mA，Iq ≈ 40µA → 同样超预算
  - **TPS7A02 类**：Iq 仅 25nA，但只有 200mA，且压差 270mV(max)@200mA → 电池 3.4V 时输出不足 3.3V，**压差不够**
- **结论（建议）**：本版**保持 HT7333 不变**，把 3.3V 侧储能做足（模组旁 100µF 低 ESR + 10µF + 100nF），用容性储能顶住 Wi-Fi 发射的毫秒级峰值——这与现版做法一致，C6 的峰值电流与 WROOM-32 同量级，**不会比现在更差**。若样机实测出现发射瞬间掉线/复位，再改 **TPS63802 类 buck-boost（2A、Iq ≈11µA）** 根治（需加电感，增加面积与成本）。

---

## 十一、参考文档（新增）

- ESP32-C6-MINI-1 & MINI-1U 数据手册（引脚定义、strapping 脚、PCB 布局建议、keepout 区）
- ESP32-C6 系列数据手册（外设引脚、ADC 通道、USB Serial/JTAG）
- V1 文件：《ESP32 墨水屏胸牌 PCB 设计外包需求》
- **AHT20 规格书**（广州奥松）：测量时间 80ms、上电等待 40ms、建议 ≥2s 测一次、**要求外壳通风与铺铜稀疏**
- **Sensirion SHT4x 规格书**（可选方案）：高重复率测量 **−6.9/+8.3 ms**
- **GoodDisplay GDEY0213Z98** 面板规格（本机所用 2.13" 三色屏，控制器 SSD1680）

---
*本说明由需求方出具；如与 V1 冲突，以本说明为准。*

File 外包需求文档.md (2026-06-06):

# ESP32 墨水屏胸牌 PCB 设计外包需求

## 一、项目概述

设计一款基于 ESP32 的 2.13 英寸三色墨水屏低功耗胸牌/桌面摆件。

### 核心功能
- ESP32-WROOM-32D 主控（WiFi + BLE）
- 2.13 英寸三色墨水屏（红/黑/白，SPI 驱动）
- 软包聚合物锂电池供电（103040，1200mAh），PH2.0 插头连接
- USB-C 充电 + 串口烧录（共用一个 USB-C 口）
- 支持无电池插入 USB-C 直接运行（USB 直供电）
- 超低功耗设计（deep sleep 续航 >1年）
- 电池电量 ADC 检测

### 关键约束
- **极低功耗优先**：deep sleep 电流目标 <20μA
- **体积最小化**：板子尽量小，能装进胸牌外壳
- **BOM 成本敏感**：单台目标 ¥35 以内
- **双面板即可**

---

## 二、电源路径设计（重要）

### 2.1 电源路径管理（新增）

使用肖特基二极管实现 USB/电池自动切换，支持无电池运行：

```
USB-C VBUS(5V) ──→ D3(SS14) ──┐
                                ├──→ VCC_RAIL → HT7333 VIN → 3.3V → 系统
电池 VBAT(3.7~4.2V) ──→ D4(SS14) ──┘
```

- **USB 插入，有电池**：VBUS(5V) > VBAT，D3 导通 D4 截止 → USB 供电 + TP4056 给电池充电
- **USB 插入，无电池**：VBUS(5V) → D3 → HT7333 → 3.3V，系统正常运行
- **USB 拔掉，有电池**：D4 导通 → 电池供电
- **USB 拔掉，无电池**：系统断电（正常行为）

### 2.2 新增器件

| 位号 | 器件 | 封装 | 数量 | 说明 |
|---|---|---|---|---|
| D3 | SS14 肖特基二极管 | SMA | 1 | USB 供电路径 |
| D4 | SS14 肖特基二极管 | SMA | 1 | 电池供电路径 |

### 2.3 USB-C 统一功能

USB-C 口同时承担三个功能，**不需要额外充电口**：
1. **供电**：VBUS(5V) → D3 → HT7333 → 3.3V（无电池也能跑）
2. **充电**：VBUS(5V) → TP4056 → 给电池充电
3. **数据**：D+/D- → CH340N → ESP32 烧录/调试

---

## 三、交付物要求

### 3.1 原理图
- 基于 KiCad 7 格式（已提供骨架文件，52个组件已放置）
- 已补充 D3/D4/J3/VBAT_SENSE 关键 wire 与网络标签，仍需在 KiCad GUI 中按 pin-to-pin 要求完成全量连线并跑 ERC
- **已新增 D3、D4 二极管切换电路与 J3 PH2.0 电池接口**
- 连线完成后需通过 ERC（Electrical Rules Check）无错误
- 导出 PDF 原理图

### 3.2 PCB 布局
- 双面板
- 板子尺寸：建议 ≤70mm × 50mm（可协商）
- 接口位置要求：
  - USB-C 口放在板子一侧短边
  - 墨水屏 FPC 接口放在板子另一侧短边
  - 电池接口（PH2.0）放在板子长边侧面或背面
  - RST/BOOT 按键放在板子边缘可触及位置
- 注意事项：
  - ESP32 天线区域下方不可铺铜、不可走线
  - USB 差分线 D+/D- 等长、尽量短
  - SPI 信号线尽量短（ESP32→墨水屏）
  - 模拟部分（ADC 分压）远离数字高频信号
  - 充电电路（TP4056）走线足够宽
  - 肖特基二极管 D3/D4 靠近电源入口放置

### 3.3 制造文件
- Gerber 文件（RS-274X）
- 钻孔文件（Excellon）
- BOM 清单（Excel）
- 贴片坐标文件（Pick & Place）
- 3D 渲染图（可选）

---

## 四、原理图连线需求（Pin-to-Pin）

### 4.1 电源网络

| 网络 | 连接 |
|---|---|
| **VBUS** | USB-C VBUS(J1) → FB1 → TP4056 VCC(4) → C6 正极 → D3 阳极 |
| **VBAT** | 电池正极 → J3 pin1 → TP4056 BAT(5) → D4 阳极 → R12 上端 → C1/C9/C11 正极 |
| **VCC_RAIL** | D3 阴极 + D4 阴极 汇聚 → HT7333 VIN(3) |
| **3V3** | HT7333 VOUT(2) → C8/C12 正极 → ESP32 VDD → 墨水屏 VCC → CH340 VCC(16) → 去耦电容正极 |
| **GND** | 所有组件 GND 汇聚 → J3 pin2 → USB-C GND → HT7333 GND(1) |

### 4.2 充电电路

| 网络 | 连接 |
|---|---|
| **VBUS→TP4056** | USB-C VBUS → FB1 → TP4056 VCC(4) → C6 正极 → CH340 VCC(16) |
| **CHRG** | TP4056 CHRG(1) → R4 → D1(LED红) 阳极 → D1阴极→GND |
| **STDBY** | TP4056 STDBY(3) → R5 → D2(LED绿) 阳极 → D2阴极→GND |
| **PROG** | TP4056 PROG(2) → R3 → GND (R3=1.2kΩ → 充电电流≈1A) |

### 4.3 电池保护

| 网络 | 连接 |
|---|---|
| **CS** | 电池正极 → R6(10k) → DW01A CS(3) → R7(100Ω) → GND → C10(100nF) |
| **OD** | DW01A OD(1) → 8205A G1(2) |
| **OC** | DW01A OC(3) → 8205A G2(4) |
| **BAT-** | 电池负极 → 8205A 源极/漏极 → TP4056 GND(3) |

### 4.4 ESP32 主控

| 网络 | 连接 |
|---|---|
| **EN** | ESP32 EN → R1(10k) → 3V3 → C10(100nF) → GND → SW1 → GND |
| **IO0** | ESP32 IO0 → R2(10k) → 3V3 → SW2 → GND |
| **TX** | ESP32 TX(GPIO1) → R8(1k) → CH340 RX(2) |
| **RX** | ESP32 RX(GPIO3) → R9(1k) → CH340 TX(3) |

### 4.5 墨水屏 SPI

| 网络 | 连接 |
|---|---|
| **EPD_MOSI** | ESP32 GPIO13 → J2 MOSI |
| **EPD_CLK** | ESP32 GPIO14 → J2 SCK |
| **EPD_CS** | ESP32 GPIO15 → J2 CS |
| **EPD_DC** | ESP32 GPIO27 → J2 DC |
| **EPD_RST** | ESP32 GPIO26 → J2 RST |
| **EPD_BSY** | ESP32 GPIO25 → J2 BUSY |

### 4.6 USB 转串口

| 网络 | 连接 |
|---|---|
| **D+** | USB-C D+(J1) → CH340 D+(5) |
| **D-** | USB-C D-(J1) → CH340 D-(6) |

### 4.7 电池电量检测

| 网络 | 连接 |
|---|---|
| **VBAT_SENSE** | R12(100k, VBAT端) → R13(100k, GND端) 中点 → C21(100nF)//R13 → ESP32 GPIO34(ADC1_CH6) |

---

## 五、BOM 清单

| 序号 | 位号 | 器件 | 封装 | 数量 | 参考价格(¥) | 备注 |
|---|---|---|---|---|---|---|
| 1 | U1 | ESP32-WROOM-32D | 模组 | 1 | 12.00 | 乐鑫 |
| 2 | U2 | HT7333-A | SOT-89 | 1 | 0.30 | 3.3V LDO, Iq=1μA |
| 3 | U3 | TP4056 | SOP-8 | 1 | 0.30 | 锂电充电 |
| 4 | U4 | DW01A | SOT-23-6 | 1 | 0.15 | 电池保护 |
| 5 | U5 | 8205A | TSSOP-8 | 1 | 0.20 | 双N-MOS |
| 6 | U6 | CH340N | SOP-8 | 1 | 0.60 | USB转串口 |
| 7 | J1 | USB-C 16pin | 母座 | 1 | 0.50 | 充电+供电+数据 |
| 8 | J2 | FPC 24pin 0.5mm | 下接 | 1 | 0.30 | 墨水屏接口 |
| 9 | J3 | PH 2.0mm 2pin | 卧式 | 1 | 0.10 | 电池接口（软包电池插头） |
| 10 | J4 | 排针 2×3 2.54mm | 直插 | 1 | 0.10 | ESP32烧录口 |
| 11 | R1-R2 | 10kΩ | 0402 | 2 | 0.01 | 上拉 |
| 12 | R3 | 1.2kΩ | 0402 | 1 | 0.01 | TP4056 PROG |
| 13 | R4-R5 | 470Ω | 0402 | 2 | 0.01 | LED限流 |
| 14 | R6 | 10kΩ | 0402 | 1 | 0.01 | DW01A CS |
| 15 | R7 | 100Ω | 0402 | 1 | 0.01 | DW01A CS |
| 16 | R8-R9 | 1kΩ | 0402 | 2 | 0.01 | 串口 |
| 17 | R10-R11 | 10kΩ | 0402 | 2 | 0.01 | 按钮 |
| 18 | R12-R13 | 100kΩ | 0402 | 2 | 0.02 | VBAT分压 |
| 19 | C1 | 100μF | 0805/钽 | 1 | 0.15 | VBAT滤波 |
| 20 | C2,C15 | 10μF | 0402 | 2 | 0.05 | 3.3V/屏滤波 |
| 21 | C3-C5,C7,C8,C10-C21 | 100nF | 0402 | 16 | 0.16 | 去耦 |
| 22 | C6,C16,C19 | 1μF | 0402 | 3 | 0.06 | 滤波 |
| 23 | C9 | 10μF | 0402 | 1 | 0.03 | HT7333输入 |
| 24 | D1 | LED 红 | 0402 | 1 | 0.03 | 充电指示 |
| 25 | D2 | LED 绿 | 0402 | 1 | 0.03 | 充满指示 |
| 26 | D3 | SS14 肖特基二极管 | SMA | 1 | 0.05 | USB供电路径 |
| 27 | D4 | SS14 肖特基二极管 | SMA | 1 | 0.05 | 电池供电路径 |
| 28 | SW1-SW2 | 轻触按键 6×6mm | 四脚 | 2 | 0.10 | RST/BOOT |
| 29 | FB1 | 磁珠 600Ω@100MHz | 0402 | 1 | 0.02 | USB EMI |
| | | | | **合计 ≈ ¥15** | | 不含ESP32/屏/电池 |

### 电池（外购，不贴片）

| 器件 | 规格 | 参考价格(¥) | 备注 |
|---|---|---|---|
| 软包聚合物锂电池 103040 | 3.7V 1200mAh，带 PH2.0 插头线 | ¥12 | 厚10mm，双面胶粘贴在外壳内壁 |

---

## 六、参考文档

- ESP32-WROOM-32D 数据手册：https://www.espressif.com/sites/default/files/documentation/esp32-wroom-32_datasheet_cn.pdf
- HT7333 数据手册：合泰(Holtek)
- TP4056 数据手册：南京微盟
- DW01A+8205A 电池保护参考设计
- CH340N 数据手册：沁恒(WCH)
- SS14 肖特基二极管数据手册
- 2.13" 三色墨水屏（参考 GoodDisplay Waveshare 213inch 3color）

---

## 七、验收标准

1. ✅ 原理图 ERC 通过，无错误
2. ✅ PCB DRC 通过，无错误
3. ✅ 所有网络连通，无断线
4. ✅ ESP32 天线区域净空
5. ✅ USB D+/D- 差分等长
6. ✅ 无电池时插入 USB-C 系统可正常运行
7. ✅ 输出完整 Gerber + BOM + 坐标文件
8. ✅ KiCad 7 源文件可正常打开编辑

---

## 八、提供文件

- `esp32-epaper.kicad_sch` — KiCad 7 原理图（52个组件已放置，需完成全量连线/ERC）
- GitHub 仓库：https://github.com/LuckyDogzyc/esp32-epaper-badge

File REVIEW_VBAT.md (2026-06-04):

# ESP32 E-Paper Badge — VBAT Sensing 审核清单

## 1. 电路拓扑 ✅

```
BAT+ ──── R12(100kΩ) ──┬── R13(100kΩ) ──┬── GND
                        │                  │
                        ├── C21(100nF) ────┘
                        │
                    GPIO34 (ADC1_CH6)
                    "VBAT_SENSE"
```

拓扑正确：分压器 + 低通滤波。

## 2. 分压比计算 ✅

- R12 = R13 = 100kΩ
- 分压比 = R13 / (R12 + R13) = 100k / 200k = 0.5
- BAT+ = 4.2V → VBAT_SENSE = 4.2 × 0.5 = 2.1V
- BAT+ = 3.0V → VBAT_SENSE = 3.0 × 0.5 = 1.5V
- ESP32 ADC1 量程 (atten=11dB): 0 ~ 3.6V
- **2.1V < 3.6V → 安全余量 71%** ✅

## 3. 功耗影响 ✅

- 静态电流 = VBAT / (R12 + R13) = 4.2V / 200kΩ = 21μA
- 24h 耗电 = 21μA × 24h = 504μAh
- 103040 软包电池容量 1200mAh → 日耗占比 = 504/1200 = 0.042%
- 年耗 = 184mAh → 续航影响约 15%（如果需要进一步压低 deep sleep 电流，后续可改为高阻值分压或用 MOSFET 控制分压上电）
- **对 1200mAh 软包电池有可见续航影响，后续量产建议评估高阻值或受控分压方案** ⚠️

## 4. GPIO 引脚选择 ✅

- GPIO34 = ADC1_CH6
- GPIO34 是 input-only 引脚 → 适合 ADC 读取 ✅
- GPIO34 属于 ADC1（不受 WiFi 影响，ADC2 在 WiFi 开启时不可用）✅
- GPIO34 原理图中已分配给 ESP32 pin 24 (IO34) ✅
- VBAT_SENSE label 同时出现在分压器中点和 ESP32 IO34 附近 ✅

## 5. 滤波电容 ✅

- C21 = 100nF 与 R12//R13 形成低通滤波
- 截止频率 f = 1/(2π×RC) = 1/(2π×50kΩ×100nF) ≈ 32Hz
- 足以滤除高频噪声，保留 DC 电池电压 ✅

## 6. 组件位置 ✅

- R12 at (230, 260) — 电源管理区域
- R13 at (230, 270) — 紧邻电池 BT1/J3
- C21 at (245, 270) — 旁路到 GND
- 所有位于 Section C (Power Management) 区域内

## 7. 组件命名 ✅

- R12, R13 延续已有 R 序列 (R1~R11)
- C21 延续已有 C 序列 (C1~C20)
- 无命名冲突

## 8. BOM 更新

| Ref | Value | 数量 | 单价(¥) |
|-----|---|---|---|
| R12 | 100kΩ 0402 | 1 | 0.01 |
| R13 | 100kΩ 0402 | 1 | 0.01 |
| C21 | 100nF 0402 | 1 | 0.02 |
| **合计** | | **3** | **0.04** |

新增 BOM 成本 ¥0.04，可忽略。

## 9. 已知局限

⚠️ 整个原理图当前仍为**骨架级**：52 个组件已放置，D3/D4/J3/VBAT_SENSE 关键网络已补充 wire/label，但多数模块仍需在 KiCad GUI 中按外包需求文档完成精确 pin-to-pin 连线。
程序化生成的 wire/label 只能作为网络意图标注，最终 ERC/PCB 前必须在 KiCad GUI 中核对并完成所有引脚端点连接。

## 10. 总评 ✅

- 电路设计正确，分压比合理
- GPIO34 选择恰当（ADC1, input-only, 不受 WiFi 影响）
- 功耗影响 < 5%
- 新增成本 ¥0.04
- 文件通过 KiCad 7 验证（netlist + PDF export）

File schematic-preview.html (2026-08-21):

# ESP32 E-Paper Badge — Next-PCB Schematic Preview v1.2

55 components placed | GPIO33 USER_BTN_N active-low (R14 10k + C22 100nF + SW2) | EN/RST remains reset-only

USB-C VBUS 5V→D3 SS14 ↘VCC_RAIL→HT7333→3V3 System 103040 VBAT→D4 SS14↗

## MCU

### U1 ESP32-WROOM-32D

C1/C2/C3, R1/R2/R3, GPIO34 VBAT_SENSE

## E-Paper

### U2 SSD1680 + J2 FPC-26P

L1, Q1, D6-D8, R7/R8, C7-C18

## USB/Charge

### J1 USB-C + U3 TP4056

R4, C4/C5, R9/R10 CC pull-down

## Power Path

### D3/D4 SS14 OR-ing

VBUS/VBAT -> VCC_RAIL -> U6 HT7333 -> 3V3

## Battery

### J3 PH2.0 + BT1 103040 LiPo

R12/R13 100k divider + C21 filter -> GPIO34

## Protection

### U4 DW01A + U5 FS8205A

Li-ion overcharge/overdischarge/overcurrent protection

## User IO

### SW1 Debug switch + SW2 USER_BTN + D5 LED

GPIO33 USER_BTN_N: R14 10k pull-up + C22 100nF debounce; short=status, >=5s=provisioning

Ref | Value | Package | Function
U1 | ESP32-WROOM-32D | Module | MCU + WiFi/BLE
U2 | SSD1680 | QFN | E-paper driver
U3 | TP4056 | SOP-8 | Li-ion charger
U4 | DW01A | SOT-23-6 | Battery protection controller
U5 | FS8205A | TSSOP-8 | Dual N-MOSFET protection switch
U6 | HT7333-1 | SOT-89 | Low-Iq 3.3V LDO
J1 | USB-C 16P | SMD | Charging/power input
J2 | FPC-26P | 0.5mm | E-paper display connector
J3 | PH2.0 2P | Connector | 103040 LiPo battery input
BT1 | 103040 LiPo | External | Battery placeholder/marking
D3,D4 | SS14 | SMA | USB/Battery power-path OR-ing
D5 | Green LED | SMD | Status indicator
D6,D7,D8 | MBR0530 | SOD-123 | SSD1680 charge pump
R1-R14 | 10k/1.2k/100R/0.47R/5.1k/1k/100k | SMD | Pull-up, charge, CC, LED, VBAT sense, USER_BTN
C1-C22 | 10uF/1uF/100nF/4.7uF | SMD | Decoupling, charge pump, VBAT and USER_BTN filters
L1 | 68uH | Power inductor | SSD1680 charge pump
Q1 | AO3400A | SOT-23 | SSD1680 gate drive
SW1 | SPDT switch | SMD | Debug/normal mode
SW2 | USER_BTN (NO) | TL3301AN/SMD | GPIO33 active-low user button; no EN/RST connection

注意：该 HTML 是下一版 PCB 的需求/组件/网络意图预览。KiCad 原理图的 USER_BTN_N 已通过 netlist 导出验证：GPIO33、R14、C22、SW2 和 3V3/GND 端点连接正确，且 USER_BTN 不连接 EN/RST。全量既有骨架原理图在 PCB 前仍需在 KiCad GUI 中完成 ERC/DRC 与其余 pin-to-pin 审核；现有外部原型 GPIO 映射不同。

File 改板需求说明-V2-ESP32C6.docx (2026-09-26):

# ESP32 墨水屏胸牌 —— PCB 改板需求说明（V2）

文件性质：本文件是在《ESP32 墨水屏胸牌 PCB 设计外包需求（V1）》基础上的变更说明。

未提到的内容沿用 V1；凡与本文件冲突处，以本文件为准。

适用对象：PCB 设计外包方。变更原因栏为实测/原理依据，可据此判断改动的必要性。

## 一、变更摘要（一句话）

主控由 经典 ESP32-WROOM-32D + CH340N USB 转串口桥片，更换为 ESP32-C6-MINI-1-N4（自带 PCB 天线、原生 USB、4MB Flash）；随之删除 USB 转串口电路、手动烧录按键与拨动开关，修正电池电量采样电路，并重新定义两个按键的功能。

本文件的使用方式：你们（设计方）已交付并制作过 V1 板，本文件即在你们那版 V1 基础上的改板制造说明——请按"三、器件变更总表"逐项增删改，未提及处一律沿用 V1 画法与你们既有的工艺。有冲突处以本文件为准。

机械结论（本版已定）：板 67 × 28 mm（屏区 + 8mm 尾部区）；堆叠为 屏朝外 → 电芯 → PCB（元件面朝卡片背面）；电芯 ≤4mm 厚；USB-C 与两个侧按键布置在屏外尾部区；板厚 0.6mm、不设安装孔，整机总厚 ≈9.1–9.6mm。详见 §5.5。

## 二、变更原因（实测依据，供理解改动必要性）

序号 | 问题 | 实测/原理
1 | 烧录必须手动拨开关进下载模式 | 板上 CH340N 是 SOP-8 精简版，只有 UART+RTS，没有 DTR；ESP32 自动下载时序必须同时用 DTR 和 RTS，因此这版硬件做不出自动下载。另外该拨动开关接在 IO2（strapping 脚）上，上电拉低会影响启动/下载判定，属隐患
2 | 换 C6 后是否还会卡在烧录 | C6 具备片内 USB-Serial/JTAG，由 ROM 控制：常规烧录不需要任何按键，固件损坏也仍可恢复（砖了能救）
3 | 16MB Flash 是否必要 | 用本项目固件实测编译：经典 ESP32 = 1,355,704 B；ESP32-C6 = 1,353,644 B（约 1.29MB）。4MB Flash 足够，原 16MB 要求取消
4 | 电池电量显示无效 | 实测：采样脚直连 VBAT，满电时 ADC 饱和（raw=4095、≈3.14V）；图纸标注的 GPIO34 分压点无信号。直连 4.2V 超出 ADC 量程，且经输入 ESD 二极管向 3.3V 轨漏电、影响待机功耗。必须补分压并固定采样脚
5 | 体积/成本 | 模组面积由 18.0×25.5 = 459mm² 降至 13.2×16.6 = 219mm²（-52%），厚度 3.1→2.4mm；删除器件再省约 165mm²

## 三、器件变更总表

### 3.1 删除项（V1 位号）

位号 | 器件 | 处理 | 原因
U6 | CH340N USB 转串口 | 删除 | C6 使用原生 USB，不需要桥片
R8, R9 | 1kΩ（TX/RX 串阻） | 删除 | 随 CH340N 一并废弃
J4 | 排针 2×3 2.54mm（烧录口） | 删除 | USB-C 直连即可烧录/调试，无需排针
C（CH340 相关） | CH340 的 V3/VCC 去耦 | 删除 | 随 U6 删除（具体位号由设计方在网表中识别）
SW（IO2 拨动开关） | 调试模式拨动开关 | 删除 | 功能移入固件；且 IO2 为 strapping 脚，不可外挂开关
R2 | 10kΩ（IO0 上拉） | 删除 | BOOT 按键取消，上拉一并废弃
J3 | PH2.0 电池插座 | 删除 | 本版改为电芯极耳直接焊在 PCB 背面，PCB 上新增 B+/B- 焊接焊盘（见 §5.4）

### 3.2 替换项

位号 | 原 | 新 | 说明
U1 | ESP32-WROOM-32D（18.0×25.5×3.1） | ESP32-C6-MINI-1-N4（13.2×16.6×2.4，自带 PCB 天线，4MB Flash） | 焊盘与 ESP32-C3-MINI-1 pin-to-pin 兼容，便于后续互换/防缺货。注意选型：必须选 `ESP32-C6-MINI-1`（PCB 天线版），不要 -1U（外置天线版）

### 3.3 保留项（不要动）

- EN 上拉 R1(10k) + C10(100nF)（EN 脚不可悬空，模组数据手册明确要求）
- 电源路径 D3/D4（SS14）、FB1、HT7333（U2）：本版确认保留、不更换（需求方决定：不换 LDO、不加 buck-boost）。请在 3.3V 侧加强储能——模组旁 100µF 低 ESR + 10µF + 100nF，用于顶住 Wi-Fi 发射的毫秒级峰值电流
- 充电与保护 TP4056(U3) / DW01A(U4) / 8205A(U5) 及指示 LED D1/D2（保留，行为与现在一致：充电中红灯亮、充满绿灯亮）
- 请确保 U3 的 CHRG → R4 → D1、STDBY → R5 → D2 两条支路连线完整（按 V1 §4.2），否则指示灯不亮
- USB-C（J1）及 CC 5.1k×2 下拉、USB ESD 保护（USB-C 供电必需，切勿删）
- 墨水屏 FPC（J2）及其 SPI 网络
- 板载电池保护（DW01A+8205A）继续使用：因取消 PH2.0 插座、电芯直接焊接，过充/过放/短路保护必须依靠板载保护电路，不可省略
- 电池分压 R12/R13（100kΩ）+ C21(100nF)（见 §5.2，仅接线改向）

## 四、按键与用户交互（重新定义，重要）

V1 中的"SW1-SW2 = RST/BOOT"作废。新定义如下（两个键都保留，均为侧按式）：

位号 | 功能 | 连接 | 说明
SW1 | 复位（实体键） | EN → SW1 → GND（保留 R1 10k 上拉、C10 100nF） | 本版按实体按键出图；硬件复位，也是固件卡死/深睡时唯一的恢复手段
SW2 | 功能键 | IO3 → SW2 → GND，配 10kΩ 外部上拉（R10），可选并联 100nF 去抖 | 低电平有效；详见下方功能定义

SW2 功能定义（固件侧实现）

- 短按（<1s）：立即刷新——取价 + 重刷墨水屏
- 长按 ≥5s：进入配网模式——清除 Wi-Fi 配置并开启 AP 热点（手机连接配网）
- 长按 ≥15s（可选档，建议保留）：恢复出厂设置（清除全部配置）

按键选型与结构（本版全部改为「侧按式」，需求方已确认）

- SW1、SW2 都改用"侧按式"贴片轻触开关：作动方向平行于板面、从卡片侧边按压；开关贴板边安装，按钮端突出板边约 0.3–1.0mm
- 可选型号（三选一，或由设计方提供等效件并注明型号）：

型号 | 尺寸 | 关键参数
Panasonic EVQ-P7A01P 类 | 3.5 × 2.9mm，安装高度 1.35mm | 侧按、约 220gf、回流焊，通用性最好
Panasonic EVP-AK 系列 | 3.8 × 1.9mm | 行程 0.12mm，寿命可达 500,000 次（最薄）
国产等效（2×4mm / 2.3×2.95mm 卧式贴片侧按键） | 约 2×4mm | 成本更低、交期更快

- 共同要求：操作力 160–250gf、寿命 ≥100,000 次（推荐 200,000+）、回流焊、RoHS
- 位置：放在屏外尾部区的侧边（见 §5.5/§5.6），两键中心距 ≥6mm 防连按；避开墨水屏 FPC 弯折区与电芯位置
- 按键位置：置于尾部区板边、作动方向朝板外；机械按压通道由需求方后续处理（见 §5.6）
- 建议按键两侧加小电容/TVS 抗 ESD（人手接触）
- 仍建议在 EN/GND 旁并两个测试盘（产线复位用，与 SW1 并联）

技术约束（务必遵守，否则按键唤不醒芯片）

- 功能键必须接在 RTC/LP GPIO（IO0–IO7 之一），才支持深睡中被按键唤醒；本方案选 IO3
- 禁止将按键接在 strapping 脚 IO4、IO5、IO8、IO9、IO15 上
- IO8、IO9 必须保持默认（不外挂上拉/下拉）——它们决定启动模式；IO15 也不得外挂上下拉（决定 JTAG 信号源，默认即片内 USB）

## 五、原理图连线变更（Pin-to-Pin，请按此重连）

### 5.1 主控引脚映射（ESP32-C6-MINI-1）

功能 | 模组脚号 | GPIO | 备注
EPD_SCLK | 15 | IO6 | 使用默认 FSPICLK，信号完整性最佳
EPD_MOSI | 16 | IO7 | 使用默认 FSPID（SPI 主机输出）
EPD_CS | 19 | IO14 | 普通 GPIO（软件片选）
EPD_DC | 25 | IO19 | 普通 GPIO
EPD_RST | 26 | IO20 | 普通 GPIO
EPD_BSY | 27 | IO21 | 普通 GPIO，输入
VBAT_SENSE | 5 | IO2 | ADC1_CH2；见 §5.2 分压要求
USER_BTN（SW2） | 6 | IO3 | LP_GPIO3，支持深睡唤醒；10k 上拉 + 按下接地（见 §4）
VBUS_DET（新增） | 24 | IO18 | USB 供电检测；见 §5.3
BAT+ / BAT- | — | — | 电芯极耳焊接焊盘（新增，见 §5.4）
EN（SW1 复位） | 8 | EN | R1 10k 上拉 + C10 100nF 到 GND，不可悬空
USB_D- | 17 | IO12 | 直连 USB-C D-
USB_D+ | 18 | IO13 | 直连 USB-C D+
3V3 | 3 | 3V3 | 加 10µF + 100nF 去耦
GND | 1、2、11、14、36–53 | GND | 全部接地
备用（建议留测试盘） | 12、13、9、10、20、22、23、28、29、30、31 | IO0、IO1、IO4、IO5、IO15、IO8、IO9、IO22、IO23、RXD0(IO17)、TXD0(IO16) | 留测试盘；IO8/IO9/IO15 不得外挂上下拉；TXD0/RXD0 保留为备用串口日志口
EN 复位（测试盘） | 8 | EN | 见 §4：以 EN + GND 两个测试盘实现（推荐），或按贵方结构改为实体键

说明：USB_D+/D- 在 V1 中是接到 CH340 的，现直接接 USB-C 的 D+/D-；V1 §4.6 的连线作废。

补充：IO6/IO7 也是引脚级 JTAG（MTCK/MTDO）的默认位置。本方案使用片内 USB-Serial/JTAG，不影响 SPI 功能；若贵方希望保留引脚级 JTAG 调试能力，可将 EPD_SCLK/EPD_MOSI 改用 IO22/IO23（其余不变），或与需求方确认后调整。IO2/IO4/IO5/IO6/IO7 同时是 LP_I2C/FSPI 复用脚，作为普通 GPIO 使用没有问题。

### 5.2 电池电量采样（必须修正，V1 §4.7 作废）

VBAT(电池正极) ── R12(100kΩ) ──┬── VBAT_SENSE ── ESP32-C6 IO2 (脚 5, ADC1_CH2)

│

C21(100nF)

│

R13(100kΩ)

│

GND

- 分压比 2:1（4.2V → 2.1V，落在 ADC 量程内）
- 禁止把 VBAT 直接接到任何 GPIO（V1 当前的实测问题即由此产生）
- 采样节点（IO2）到 GND 之间加 100nF 滤波
- 可选优化（建议）：在 R12 前串一个高边 P-MOS 开关，仅在测量瞬间导通，可把分压常耗电流从约 21µA 降到 0（对深睡电流目标有意义）

### 5.3 USB 供电检测（新增，V1 无此电路）

现状说明：V1 及目前实物均没有 USB 检测电路（固件注释明确写着 "No USB-present signal is wired"），现在界面上的"USB/未接电池"只是固件在 ADC 读数无效时的兜底文案，并非真实检测。

USB-C VBUS(5V) ── R14(100kΩ) ──┬── VBUS_DET ── ESP32-C6 IO18 (脚 24)

│

C22(100nF)

│

R15(100kΩ)

│

GND

- 分压比 2:1（5V → 2.5V），插 USB 时 IO18 读到高电平，固件据此显示"USB 供电 / 充电中"
- 该分压接在 VBUS 侧，不插 USB 时不通电，不会消耗电池（与 §5.2 的电池分压不同）
- 保留 §5.2 的电池分压，两者配合即可实现"供电来源 + 电池电量"同时显示

### 5.4 电池：取消插座，改为背贴焊接（本版变更）

取消 J3（PH2.0 插座），电芯极耳直接焊到 PCB 背面焊盘。要求：

1. 新增焊盘：BAT+ / BAT- 两个焊盘，位置与所选电芯极耳位置对应；丝印标注极性（B+/B-），极性标反会烧板，务必双人复核
2. 电芯必须带焊片/镍带（Tab），不接受裸极耳；焊接工艺：烙铁 ≤350℃、单点 ≤3s、焊点离电芯本体 ≥2mm，焊后用硅胶/UV 胶加固
3. 背面电池区域：不得有过孔、不得有裸露走线（防刺穿短路）；电芯与 PCB 之间垫绝缘片（青稞纸/PET）
4. 必须避开模组天线净空区：电芯不得压在天线正下方及其前方净空区内（见 §6）
5. 四周留 0.5mm 膨胀余量，厚度方向留 1mm；电芯与板边平行放置

电芯选型（依 §5.5 堆叠：电芯夹在墨水屏与 PCB 之间；已锁定厚度 ≤4mm）

方案 | 尺寸（厚×宽×长 mm） | 标称容量 | 说明
标准现货（推荐先打样用） | 402550：4×25×50 | 450mAh | 现货可买，长度 50mm ≤ 可用 52mm ✓
标准现货（备选） | 402540：4×25×40 | 400–420mAh | 更短，容量略小
定制（量产最优） | 4×27×52 | 约 560–620mAh | 面积做满；软包按尺寸裁切，一般 MOQ 500–1000

可用电芯区（板 67×28，见 §5.5）：约 52 × 27 mm

续航估算（可用容量按 80%、自放电 2%/月计；"不刷屏"= 价格未变化时跳过墨水屏刷新）

电芯 | 60 分钟唤醒 | 60min + 不刷屏 | 120 分钟唤醒 | 120min + 不刷屏
402540（420mAh） | 41 天 | 58 天 | 77 天 | 108 天
402550（450mAh） | 43 天 | 62 天 | 82 天 | 115 天
定制 4mm（600mAh） | 57 天 | 81 天 | 107 天 | 148 天
定制 4mm（620mAh） | 59 天 | 84 天 | 110 天 | 153 天

说明：4mm 厚度下容量由面积决定，因此定制 27×52 比标准 25×50 多约 30% 容量。若续航不满意，最有效的杠杆是延长唤醒周期（60→120 分钟几乎翻倍）与价格未变不刷屏，而不是加厚电芯。

### 5.5 整机堆叠与厚度（本版新增，决定性章节）

堆叠顺序（由外到内）

[卡片正面] 墨水屏（屏幕朝外）

↓

电芯（夹在屏与板之间，可用约 55×27mm）

↓

PCB（元件面朝卡片背面：模组、USB-C、按键、电源）

↓

[卡片背面] 背壳（塑料，需留按键按点与 USB 开孔）

射频判断：该堆叠下模组的 PCB 天线位于元件面，朝卡片背面辐射；屏与电芯都在板的另一侧，不再挡在天线正前方 → 射频环境比"屏盖板"方案好得多，方向性判断成立。但仍须遵守三条：

6. 天线净空区必须全层无铜（天线下方、模组投影区内，板的正反两面都不铺铜、不走线）——这条与堆叠无关，是硬要求；
7. 电芯的投影不要压在天线正上方：虽然电芯在板的另一侧，但大面积金属膜仍会失谐 → 建议电芯与天线区间隔 ≥5mm；
8. 背壳必须是塑料（非金属），背面不得贴金属标牌、铝箔、NFC 金属贴等；装配后必须实测 RSSI 与连接距离（不能只看理论）。

厚度账（分区域取最大值，单位 mm）

厚度不是各层相加，而是"屏区"与"尾部区"各自计算后取较大值（模组、USB-C 都在尾部区，不与屏/电芯叠加）：

- 屏区 = 屏 1.05 + 屏胶 0.2 + 电芯 T + 缓冲 0.3 + PCB + 屏区最高元件 + 背壳内隙 0.4 + 背壳 0.6
- 尾部区 = PCB + 模组 2.4 + 背壳内隙 0.4 + 背壳 0.6 + 前壳 0.6 ≈ 4.6（不是瓶颈）

PCB 厚度 | 电芯 3.0mm | 电芯 3.5mm | 电芯 4.0mm
0.6mm（推荐） | ≈8.6 | ≈9.1 | ≈9.6
0.8mm | ≈8.8 | ≈9.3 | ≈9.8

（屏区最高元件按 FPC 座 2.0mm 计；若屏区元件压到 1.5mm，可整体再减 0.5mm）

✅ 本版已确定的机械配置

项目 | 取值
板子尺寸 | 67 × 28 mm（屏区 59.2 + 尾部区 8）
板厚 | 0.6mm（推荐），可选 0.8mm
安装孔 | 不设安装孔/定位孔（板在壳内以双面胶/泡棉胶固定）
USB-C 位置 | 屏外尾部区（不在屏下 → 3.2mm 不计入总厚）
电芯 | 厚度 ≤4mm，面积约 52×27mm（见 §5.4）
整机总厚 | ≈9.1–9.6mm（0.6mm 板 + 4mm 电芯）

尾部区（8mm）建议布置：模组（天线朝卡片外端）+ USB-C（与模组并排于短边）+ 两个侧按键；屏的 FPC 座放在屏区外侧短边。

再减薄的空间（可选）：电芯 3.5mm → -0.5；屏区最高元件压到 1.5mm → -0.5；缓冲 0.3→0.2、背壳 0.6→0.5 → 各 -0.1。

结构要求

- 电芯四周留 0.5mm、厚度方向留 1mm 膨胀空间；电芯与屏之间加 0.2–0.3mm 缓冲垫（防压屏）
- 电芯极耳/镍带走向与 PCB 焊盘对齐（见 §5.4），不得跨过 FPC 弯折区
- 板子固定方式：双面胶/0.5mm 泡棉胶贴装（3M 200MP 类）→ 因此板面不设螺丝孔与定位孔
- 0.6mm 板注意：USB-C 座的焊接强度会下降，请加大固定焊盘/加锡量或做局部补强（不要因此改回 1.6mm）

### 5.6 结构固定与按键通道（与外壳解耦）

- 本版不与外壳/开孔绑定：设计方按 §5.5 的板尺寸与堆叠出图即可，无需等待外壳资料，也不必做外壳干涉核对
- 板子不设安装孔：靠双面胶/泡棉胶固定在壳内（省下孔位及周围禁布区约 40–120mm²，也省掉螺丝高度）
- 两个侧按键：位于板边、作动方向朝板外、按钮端突出板边 0.3–1.0mm；机械按压通道由需求方后续与外壳方案一并处理。设计方只需保证：位于尾部区侧边、两键中心距 ≥6mm、不与电芯/FPC 冲突、丝印标注功能（SW1 复位 / SW2 短按刷新·长按重置）
- 屏与板的相对定位由电芯缓冲垫与胶带保证；屏 59.2mm 与板 67mm 的 8mm 差值即尾部区

## 六、布局与射频要求（更新 V1 §3.2）

9. PCB 天线净空（重点）：模组天线端应伸出板边；天线区域及其正下方所有层不得铺铜、不得走线；天线前方约 15mm 范围内不放置金属件/电池/大块铜箔；模组尽量远离电芯与大块金属。
10. USB 差分线 D+/D-：尽量短、等长、避免跨分割，串阻/ESD 器件靠近 USB-C。
11. SPI（模组→墨水屏）走线尽量短；EPD 的去耦电容靠近 FPC 座。
12. ADC 分压（VBAT_SENSE）远离 SPI、USB、充电电路等高频/大电流区域。
13. 充电电路（TP4056）走线足够宽；D3/D4 靠近电源入口。
14. 模组下方地平面完整，模组四周多打地过孔（散热与射频回流）。
15. 电芯区（屏与板之间，见 §5.5）：PCB 上该区域对应的走线/过孔允许（电芯不在 PCB 表面），但丝印须标出电芯外形与极性；电芯投影不得进入天线净空区，且与天线区间隔 ≥5mm。
16. 两个侧按键（SW1/SW2）位于尾部区板边，丝印标注功能（SW1 复位 / SW2 短按刷新·长按重置）；板面不设安装孔。

## 七、Flash 与分区要求（需求方固件侧负责，设计方仅需按此选型/留分区）

- Flash 容量 4MB 即可（实测固件 1.29MB）；选型后缀 -N4；如需 OTA 余量可选 -N8，但非必须
- 分区表必须包含：
- nvs ≥ 20KB（设备配置、渲染指令、槽位参数）
- `fat`（FFat）分区 ≥ 64KB —— 固件用 FFat 存放位图帧文件（约 8KB）。若分区表中只有 spiffs 分区，FFat 将挂载失败，请务必保留一个 data, fat 分区
- app ≥ 2MB
- 注意：Arduino 默认的 4MB 分区方案（app 槽仅 1.2MB）装不下本固件，请使用自定义分区表

## 八、交付物与验收标准（增补 V1 §3.3 / §七）

交付物（在 V1 基础上补充）

17. KiCad 7 原理图（已完成全量连线、ERC 通过）+ PDF
18. PCB 源文件 + Gerber（RS-274X）+ 钻孔（Excellon）+ BOM（Excel）+ 贴片坐标
19. 位号图/装配图（标注 SW1/SW2 位置与功能）
20. BOM 中 U1 必须写完整型号（ESP32-C6-MINI-1-N4）

验收标准（新增/修改）

21. ✅ 原理图 ERC 通过、PCB DRC 通过，所有网络连通
22. ✅ 天线区域净空检查通过（天线区及正下方无铜、无走线）
23. ✅ USB-C 直连电脑即可烧录，全程不需要按任何按键
24. ✅ 电池分压输出实测：满电时采样点电压 ≈ VBAT/2（约 2.1V），不得出现饱和
25. ✅ 两个侧按键按压力/手感正常（160–250gf），短按与长按均能被固件识别（电气验证由需求方固件侧完成）
26. ✅ 无电池时插 USB-C 系统可正常运行
27. ✅ 分区表含 fat 分区（见 §7）
28. ✅ 插 USB 时 VBUS_DET（IO18）读到高电平，拔掉后为低电平
29. ✅ 充电电流按所选电芯的 0.5C 实测（R3 按 §5.4 调整），充电中红灯亮、充满绿灯亮
30. ✅ 电池焊盘极性丝印正确、电芯可完整放入"屏与板之间"的位置且不压天线净空区
31. ✅ 两个侧按键按压力 160–250gf 手感正常，按钮端突出板边 0.3–1.0mm
32. ✅ 板面无安装孔；整机总厚按 §5.5 区域法计算 ≤9.6mm（0.6mm 板 + 4mm 电芯）

## 九、改板步骤（建议顺序，供设计方参考）

33. 在 V1 工程中替换 U1 库符号/封装为 ESP32-C6-MINI-1（含 keepout 区），按 §5.1 重排全部网络
34. 删除 CH340N 及其外围、R2、R8/R9、J4、IO2 拨动开关（§3.1）
35. USB 网络改向：USB-C D+/D- 直接接模组 IO12/IO13（§5.1）
36. 补/改电池分压：R12/R13/C21 接到 IO2（§5.2）
37. 按键重接：SW1（侧按键）→ EN、SW2（侧按键）→ IO3 + 10k 上拉（§4）
38. 删除 J3，背面新增 BAT+/BAT- 焊盘，按 §5.4 布置电芯区（避开天线净空）
39. 新增 VBUS 检测（VBUS→100k→IO18→100k→GND + 100nF，§5.3），并按最终电芯容量调整 R3（§5.4）
40. 按 §5.5/§5.6 核对板尺寸、板厚 0.6mm、无安装孔三项，再按 §6 完成布局与净空，跑 ERC/DRC，导出制造文件
41. 样机回来后按下述顺序验证：USB 直连烧录（免按键）→ 电池分压电压（≈VBAT/2）→ VBUS 检测电平 → 充电电流与 LED → 按键短按刷新/长按重置

## 十、待确认事项（请贵方答复或标注）

已确认（需求方答复，设计方照此执行）

42. ✅ D1/D2 充电指示 LED 保留，行为与现在一致（充电中红、充满绿）
43. ✅ 增加 USB VBUS 检测（§5.3），与本版电量显示配合实现"供电来源 + 电池电量"
44. ✅ 取消 PH2.0 插座，电芯极耳直接焊在 PCB 上；电芯位置改为夹在屏与 PCB 之间（§5.5）
45. ✅ SW1、SW2 两个按键都做实体键（§4）
46. ✅ 整机堆叠：屏朝外 → 电芯 → PCB（元件面朝背面）（§5.5）
47. ✅ 电芯走"减薄 + 面积做满"路线，厚度 ≤4mm（§5.4）
48. ✅ 接受"屏外尾部区"：板尺寸定为 67×28mm（屏区 59.2 + 尾部 8），USB-C 放尾部区
49. ✅ 电芯厚度 ≤4mm（容量 450–620mAh，见 §5.4）
50. ✅ 两个按键改为侧按式（从卡片侧边按，型号见 §4）
51. ✅ 外壳条件不纳入本版约束：设计方无须等待外壳资料、无须做外壳干涉核对
52. ✅ HT7333 保留不换，3.3V 侧加强储能电容（见 §3.3）
53. ✅ 板厚 0.6mm、板面不设安装孔（双面胶/泡棉胶固定）

需设计方反馈（不影响开工，出图后一并答复）

- 所选侧按键的具体型号与尺寸（需求方据此确认手感与采购）
- 电芯容量最终档：现货 402550（4×25×50，450mAh） 还是 定制 4×27×52（≈560–620mAh）——请给交期与单价
- 若 0.6mm 板影响 USB-C 座焊接强度，请提出加强做法（加大焊盘/补强），不要改回 1.6mm

关于 HT7333（第 6 项的区别说明）

- HT7333-A：3.3V、额定输出 150mA 级（部分渠道标 250mA）、静态电流低（µA 级），但额定电流远低于 Wi-Fi 发射瞬态峰值
- 500mA 级替代品的差别在三个指标上互相拉扯：
- TPS77x33 类：500mA、压差 169mV@500mA，但 Iq ≈ 92µA → 直接打破 deep sleep <20µA 的目标，不可用
- ME6211 类：500mA，Iq ≈ 40µA → 同样超预算
- TPS7A02 类：Iq 仅 25nA，但只有 200mA，且压差 270mV(max)@200mA → 电池 3.4V 时输出不足 3.3V，压差不够
- 结论（建议）：本版保持 HT7333 不变，把 3.3V 侧储能做足（模组旁 100µF 低 ESR + 10µF + 100nF），用容性储能顶住 Wi-Fi 发射的毫秒级峰值——这与现版做法一致，C6 的峰值电流与 WROOM-32 同量级，不会比现在更差。若样机实测出现发射瞬间掉线/复位，再改 TPS63802 类 buck-boost（2A、Iq ≈11µA） 根治（需加电感，增加面积与成本）。

## 十一、参考文档（新增）

- ESP32-C6-MINI-1 & MINI-1U 数据手册（引脚定义、strapping 脚、PCB 布局建议、keepout 区）
- ESP32-C6 系列数据手册（外设引脚、ADC 通道、USB Serial/JTAG）
- V1 文件：《ESP32 墨水屏胸牌 PCB 设计外包需求》

*本说明由需求方出具；如与 V1 冲突，以本说明为准。*

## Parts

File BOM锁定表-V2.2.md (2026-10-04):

# 器件锁定 BOM（V2.2 · 需求方指定 · 换 C3 主控并降本 · 墨水屏按 ¥9 计）

> 本表**由需求方（我们）出具**，随《改板需求说明-V2.2-ESP32C3-降本》一并生效。
>
> **职责划分（先说清楚）**：选型由**需求方**决定，设计方/板厂按本表选料与贴装。
> **标"锁定"的器件必须照此采购**；标"参数锁定"的可按参数选等效件，但**等效替代需经需求方书面同意**（不接受口头替换、不接受"脚对脚一样"就自行换型号）。
> 价格/库存为 **2026-10-04 立创商城实时页** 抓取值，仅供成本参考，**下单前请复核**。
>
> **V2.2 变更**：U1 由 C6 换 **ESP32-C3-MINI-1-N4**（省 ¥4.73/台）；电芯改为**不带保护板 PCM 的裸电芯 + 镍带**（板载已有 DW01A+8205A，省 ¥0.5–1.0）。
> 未列入本表的通用件（阻容/磁珠/LED/二三极管）按"参数 + 封装"采购即可，无需锁 C 编号。

## 一、锁定件（照此采购）

| 位号 | 功能 | 指定型号 | 品牌 | 封装 | 立创编号 | 现货 | 参考价 |
|---|---|---|---|---|---|---|---|
| **U1** | 主控模组 | **ESP32-C3-MINI-1-N4** | ESPRESSIF 乐鑫 | SMD-53P（13.2×16.6×2.4） | **C2838502** | 11 → **需订货** | **¥12.48 @650+** / ¥13.03 @100+ |
| **U4** | 电池保护 IC | **DW01A** | HL 富海微（备选：永裕泰 C2927799） | SOT-23-6 | **C18164398** | 9180 | ¥0.078 @9000 |
| **U5** | 保护 MOS | **FS8205A** | TECH PUBLIC 台舟（备选：富芯森美 C908265） | SOT-23-6 | **C2830320** | 51 | ¥0.165 @6000 |
| **U7** | 温湿度传感器 | **AHT20** | 广州奥松 | DFN-4 3.0×3.0×1.0 | **C2757850** | 34 | ¥2.76 @500 / ¥2.68 @1000 |
| **屏** | 2.13″ 三色墨水屏 | **GDEY0213Z98**（122×250，SSD1680 驱动，24 针级） | 大连佳显 GoodDisplay | 屏 + FPC | 立创无售 | — | **¥9.00（V2.2 需求方给定假设）** ⚠️ 须确认是**黑白双色**还是**红黑白三色**（FPC 针数可能不同，且影响固件是否用红色） |
| **BT** | 软包电芯 | **402550（4×25×50mm）3.7V 450mAh，带镍带/焊片；V2.2 起不要自带保护板 PCM**（板载已有 DW01A+8205A，重复保护无必要） | 待定 | 软包 | — | — | ¥5.6–7.2（$0.78–1.0，去 PCM 可再省 ¥0.5–1.0） |

**U1 特别注意（V2.2：已由 C6 改为 C3）**
- 必须是 **`ESP32-C3-MINI-1`（PCB 天线版）**；**-1U（外置天线版）不允许**
- 后缀 **N4 = 4MB Flash 片内**（C3 实测固件 1.27MB，够用且比 C6 小 22KB）；若要 OTA 双槽余量可换 -N8，**需先书面确认**
- **与 C6-MINI-1 焊盘 pin-to-pin 兼容**：模组封装/外形不变，**但引脚映射与 USB 走线必须按改板说明 §5.1 重排** ⚠️
- **立创现货仅个位数，需订货**：请设计方在出图前确认货期；若交期不可接受，需求方另行安排代理采购
- C6 版（C5736265，¥17.21@1300）**仅作对照**，本版不再采用

**U7 特别注意**（换料会牵动封装）
- 本版按 **AHT20（DFN-4 3×3mm）** 出图
- 若改用 **Sensirion SHT40/SHT41**（1.5×1.5mm，I2C 0x44，测量 8.3ms）：**封装与走线不同，必须另开一版**，并书面通知需求方（固件同步改）
- **不接受**用 DHT11/DHT22 等单总线器件替代（待机 50–60µA，对本产品日均 1–6mAh 的预算不可接受）

## 二、参数锁定件（可按参数选等效件，替代需书面同意）

| 位号 | 功能 | 必须满足的参数 | 封装 | 参考价 |
|---|---|---|---|---|
| **U2** | LDO 3.3V | **输出电压 3.3V ±2%；额定 ≥250mA；静态电流 Iq ≤ 4µA**（HT7333 原厂 1µA 级）。**明确不接受** AMS1117（Iq 5mA）、TPS77x33（Iq 92µA）、ME6211（Iq 40µA） | SOT-89 / SOT-23 | ¥0.15–0.21 |
| **U3** | 锂电充电 | TP4056 类，SOP-8/ESOP-8（**带散热焊盘**），**恒压精度 ≤1.5%**，可外置 PROG 电阻设充电电流 | ESOP-8 | ¥0.16–0.21 |
| **J1** | USB-C 母座 | 16P，**沉板/卧贴按结构定**，含 CC 引脚；插拔寿命 ≥10,000 次 | 16P | ¥0.20–0.37 |
| **J2** | 墨水屏 FPC 座 | **针数与间距必须与所选屏的 FPC 完全一致（见"待核对"第 1 条）**；翻盖式、金手指厚度匹配 | 按屏 | ¥0.2–0.4 |
| **SW1/SW2** | 侧按键 ×2（V2.2 优先国产以降价）| **侧按式（作动方向平行板面）**；**操作力 160–250gf；寿命 ≥100,000 次（建议 200,000+）**；回流焊、RoHS；按钮端突出板边 0.3–1.0mm。可参考 Panasonic **EVQ-P7A01P 类**（3.5×2.9×1.35mm）或国产 2×4mm 卧式侧按 | 侧按 SMD | ¥0.3–2.0 |
| **D3/D4** | 电源路径肖特基 | SS14 / SS24 类，**正向电流 ≥1A**，低压降 | SMA | ¥0.08–0.12 |
| **FB1** | 磁珠 | 0603，**额定 ≥1A，DCR ≤ 0.1Ω**（电源路径用） | 0603 | ¥0.03–0.06 |
| **D1/D2** | 充电指示 LED | 红/绿，**0603 或 0805**，VF/亮度与现有行为一致（充电红、满绿） | 0603/0805 | ¥0.03–0.06 |
| 阻容 | 约 30 件 | 0402/0603；**分压电阻 1%**（电量采样 100k×2）、其余 5%；电容按容值/耐压选 | 0402/0603 | ¥0.6–1.0（合计） |

## 三、待核对（出图前必须闭环，否则可能整批报废）

1. **⚠️ FPC 针数与间距**：V1 图纸用的是 **FPC-26P**；而本版选定的 **GDEY0213Z98** 与现有实机面板（QYEG0213RYF661）的 **FPC 针数/间距/金手指朝向必须逐一核对**，三者（图纸 ↔ 屏厂规格书 ↔ 实机来料）**必须完全一致**。
   → 请设计方在打样前**向屏厂索取该型号的 FPC 定义图**并与图纸比对，把结论写回本文件。
2. **侧按键的封装与结构通道**：型号由需求方锁定（见二类），但**封装尺寸、贴板方向、按钮端突出量**需设计方按结构确认，并回报所选型号的**具体料号**。
3. **USB-C 座在 0.6mm 板上的焊接强度**：请提出加强做法（加大固定焊盘/补强/加锡量），**不要因此改回 1.6mm**。
4. **U1 货期**：立创现货为 0，请在出图前确认交期或提出替代渠道（不接受换型号，需先书面确认）。
5. **电芯供应商**：请按"4×25×50、450mAh、带镍带、与板上焊盘间距匹配"给出可下单的供应商与型号，并确认 PCM 一体件方案。

## 四、成本参考（V2.2 · 屏按 ¥9 / 1000–1300 片量级）

**电子 BOM**

- U1 ESP32-C3-MINI-1-N4 ¥12.48（@650+，立创 C2838502）
- 墨水屏 2.13″ **¥9.00**（需求方给定假设）
- U7 AHT20 ¥2.68（立创 C2757850）
- 电芯 402550 450mAh（去 PCM）¥5.10–6.70
- U2 LDO ¥0.15–0.21 / U3 TP4056 ¥0.16–0.21 / U4 DW01A ¥0.08 / U5 FS8205A ¥0.17
- J1 USB-C ¥0.20–0.37 / J2 FPC 座 ¥0.20–0.40
- SW1/SW2 按键（国产）¥0.60–1.20 / D1-D4 ¥0.22–0.36 / FB1 ¥0.03–0.06
- 阻容约 30 件 ¥0.60–1.00
- **小计 ¥31.67–34.92**

**制造 / 结构（结构件非设计方采购范围，此处仅内部成本核算）**

- PCB 0.6mm 67×28（喷锡 + 拼板，1000 片）¥0.80–1.50
- SMT 贴装（单面 + 拼板）¥1.50–3.00
- **塑料外壳（注塑单价）¥1.50–3.00**（开模另计）
- **正面外观件：拉丝铝 + 阳极氧化（推荐）/ 铁片（需电镀，不推荐）¥0.50–3.00**（冲压/落料 $0.03–0.65/片 + 表面处理；**拉丝+阳极比喷涂铁皮约 +¥0.2–0.8，需正式询价**）
- 装配 + 测试 + 包装 ¥3.00–6.00
- **小计 ¥7.30–16.50**

**单台制造成本 ≈ ¥38.97–51.42**（V2.1/V2.2 旧口径"屏 ¥18–28"时约 ¥50–73 → **降 ¥11–22**）

**一次性（NRE）**

- 塑料外壳开模 ¥15,000–40,000（常规小型两片壳）
- 铁皮冲压模 ¥3,000–10,000（简单落料/冲孔；含折弯/拉伸更高）
- **合计 ¥18,000–50,000**

**定价参考**（成本 × 倍数，含毛利、不含渠道/物流/售后）

- ×2.5 → ¥97–129
- ×3.0 → ¥117–154
- ×3.5 → ¥136–180
- 若走收藏品定位 ¥199–299：毛利率约 **74%–87%**

⚠️ **正面外观金属件的约束（务必与结构件方案一起执行）**：仅**正面**、纯外观；**不得覆盖屏显示区**（按可见区 48.55×23.71mm 开窗）、**不得遮挡透气孔**、**尾部区尽量收窄或断开、边缘与天线区投影至少留 15mm**。**材料建议拉丝铝+阳极氧化**（铁易锈、铁磁、同厚重 3 倍：0.3mm 时铝 1.52g vs 铁 4.43g）。装配完整机后**实测 RSSI**，与裸板对比**衰减 >6dB 判不合格**。详见改板说明 §5.5 第 4 条。

*本表由需求方出具，与《改板需求说明-V2.1》同等效力；两文件冲突处，以本表为准。*

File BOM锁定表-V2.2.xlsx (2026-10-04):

位号 | 功能 | 指定型号/参数 | 品牌 | 封装 | 立创编号 | 现货 | 参考价 | 所属章节
U1 | 主控模组 | ESP32-C3-MINI-1-N4 | ESPRESSIF 乐鑫 | SMD-53P（13.2×16.6×2.4） | C2838502 | 11 → 需订货 | ¥12.48 @650+ / ¥13.03 @100+ | 一、锁定件（照此采购）
U4 | 电池保护 IC | DW01A | HL 富海微（备选：永裕泰 C2927799） | SOT-23-6 | C18164398 | 9180 | ¥0.078 @9000 | 一、锁定件（照此采购）
U5 | 保护 MOS | FS8205A | TECH PUBLIC 台舟（备选：富芯森美 C908265） | SOT-23-6 | C2830320 | 51 | ¥0.165 @6000 | 一、锁定件（照此采购）
U7 | 温湿度传感器 | AHT20 | 广州奥松 | DFN-4 3.0×3.0×1.0 | C2757850 | 34 | ¥2.76 @500 / ¥2.68 @1000 | 一、锁定件（照此采购）
屏 | 2.13″ 三色墨水屏 | GDEY0213Z98（122×250，SSD1680 驱动，24 针级） | 大连佳显 GoodDisplay | 屏 + FPC | 立创无售 | — | ¥9.00（V2.2 需求方给定假设） ⚠️ 须确认是黑白双色还是红黑白三色（FPC 针数可能不同，且影响固件是否用红色） | 一、锁定件（照此采购）
BT | 软包电芯 | 402550（4×25×50mm）3.7V 450mAh，带镍带/焊片；V2.2 起不要自带保护板 PCM（板载已有 DW01A+8205A，重复保护无必要） | 待定 | 软包 | — | — | ¥5.6–7.2（$0.78–1.0，去 PCM 可再省 ¥0.5–1.0） | 一、锁定件（照此采购）
U2 | LDO 3.3V | 输出电压 3.3V ±2%；额定 ≥250mA；静态电流 Iq ≤ 4µA（HT7333 原厂 1µA 级）。明确不接受 AMS1117（Iq 5mA）、TPS77x33（Iq 92µA）、ME6211（Iq 40µA） | SOT-89 / SOT-23 | ¥0.15–0.21 |  |  |  | 二、参数锁定件（可按参数选等效件，替代需书面同意）
U3 | 锂电充电 | TP4056 类，SOP-8/ESOP-8（带散热焊盘），恒压精度 ≤1.5%，可外置 PROG 电阻设充电电流 | ESOP-8 | ¥0.16–0.21 |  |  |  | 二、参数锁定件（可按参数选等效件，替代需书面同意）
J1 | USB-C 母座 | 16P，沉板/卧贴按结构定，含 CC 引脚；插拔寿命 ≥10,000 次 | 16P | ¥0.20–0.37 |  |  |  | 二、参数锁定件（可按参数选等效件，替代需书面同意）
J2 | 墨水屏 FPC 座 | 针数与间距必须与所选屏的 FPC 完全一致（见"待核对"第 1 条）；翻盖式、金手指厚度匹配 | 按屏 | ¥0.2–0.4 |  |  |  | 二、参数锁定件（可按参数选等效件，替代需书面同意）
SW1/SW2 | 侧按键 ×2（V2.2 优先国产以降价） | 侧按式（作动方向平行板面）；操作力 160–250gf；寿命 ≥100,000 次（建议 200,000+）；回流焊、RoHS；按钮端突出板边 0.3–1.0mm。可参考 Panasonic EVQ-P7A01P 类（3.5×2.9×1.35mm）或国产 2×4mm 卧式侧按 | 侧按 SMD | ¥0.3–2.0 |  |  |  | 二、参数锁定件（可按参数选等效件，替代需书面同意）
D3/D4 | 电源路径肖特基 | SS14 / SS24 类，正向电流 ≥1A，低压降 | SMA | ¥0.08–0.12 |  |  |  | 二、参数锁定件（可按参数选等效件，替代需书面同意）
FB1 | 磁珠 | 0603，额定 ≥1A，DCR ≤ 0.1Ω（电源路径用） | 0603 | ¥0.03–0.06 |  |  |  | 二、参数锁定件（可按参数选等效件，替代需书面同意）
D1/D2 | 充电指示 LED | 红/绿，0603 或 0805，VF/亮度与现有行为一致（充电红、满绿） | 0603/0805 | ¥0.03–0.06 |  |  |  | 二、参数锁定件（可按参数选等效件，替代需书面同意）
阻容 | 约 30 件 | 0402/0603；分压电阻 1%（电量采样 100k×2）、其余 5%；电容按容值/耐压选 | 0402/0603 | ¥0.6–1.0（合计） |  |  |  | 二、参数锁定件（可按参数选等效件，替代需书面同意）

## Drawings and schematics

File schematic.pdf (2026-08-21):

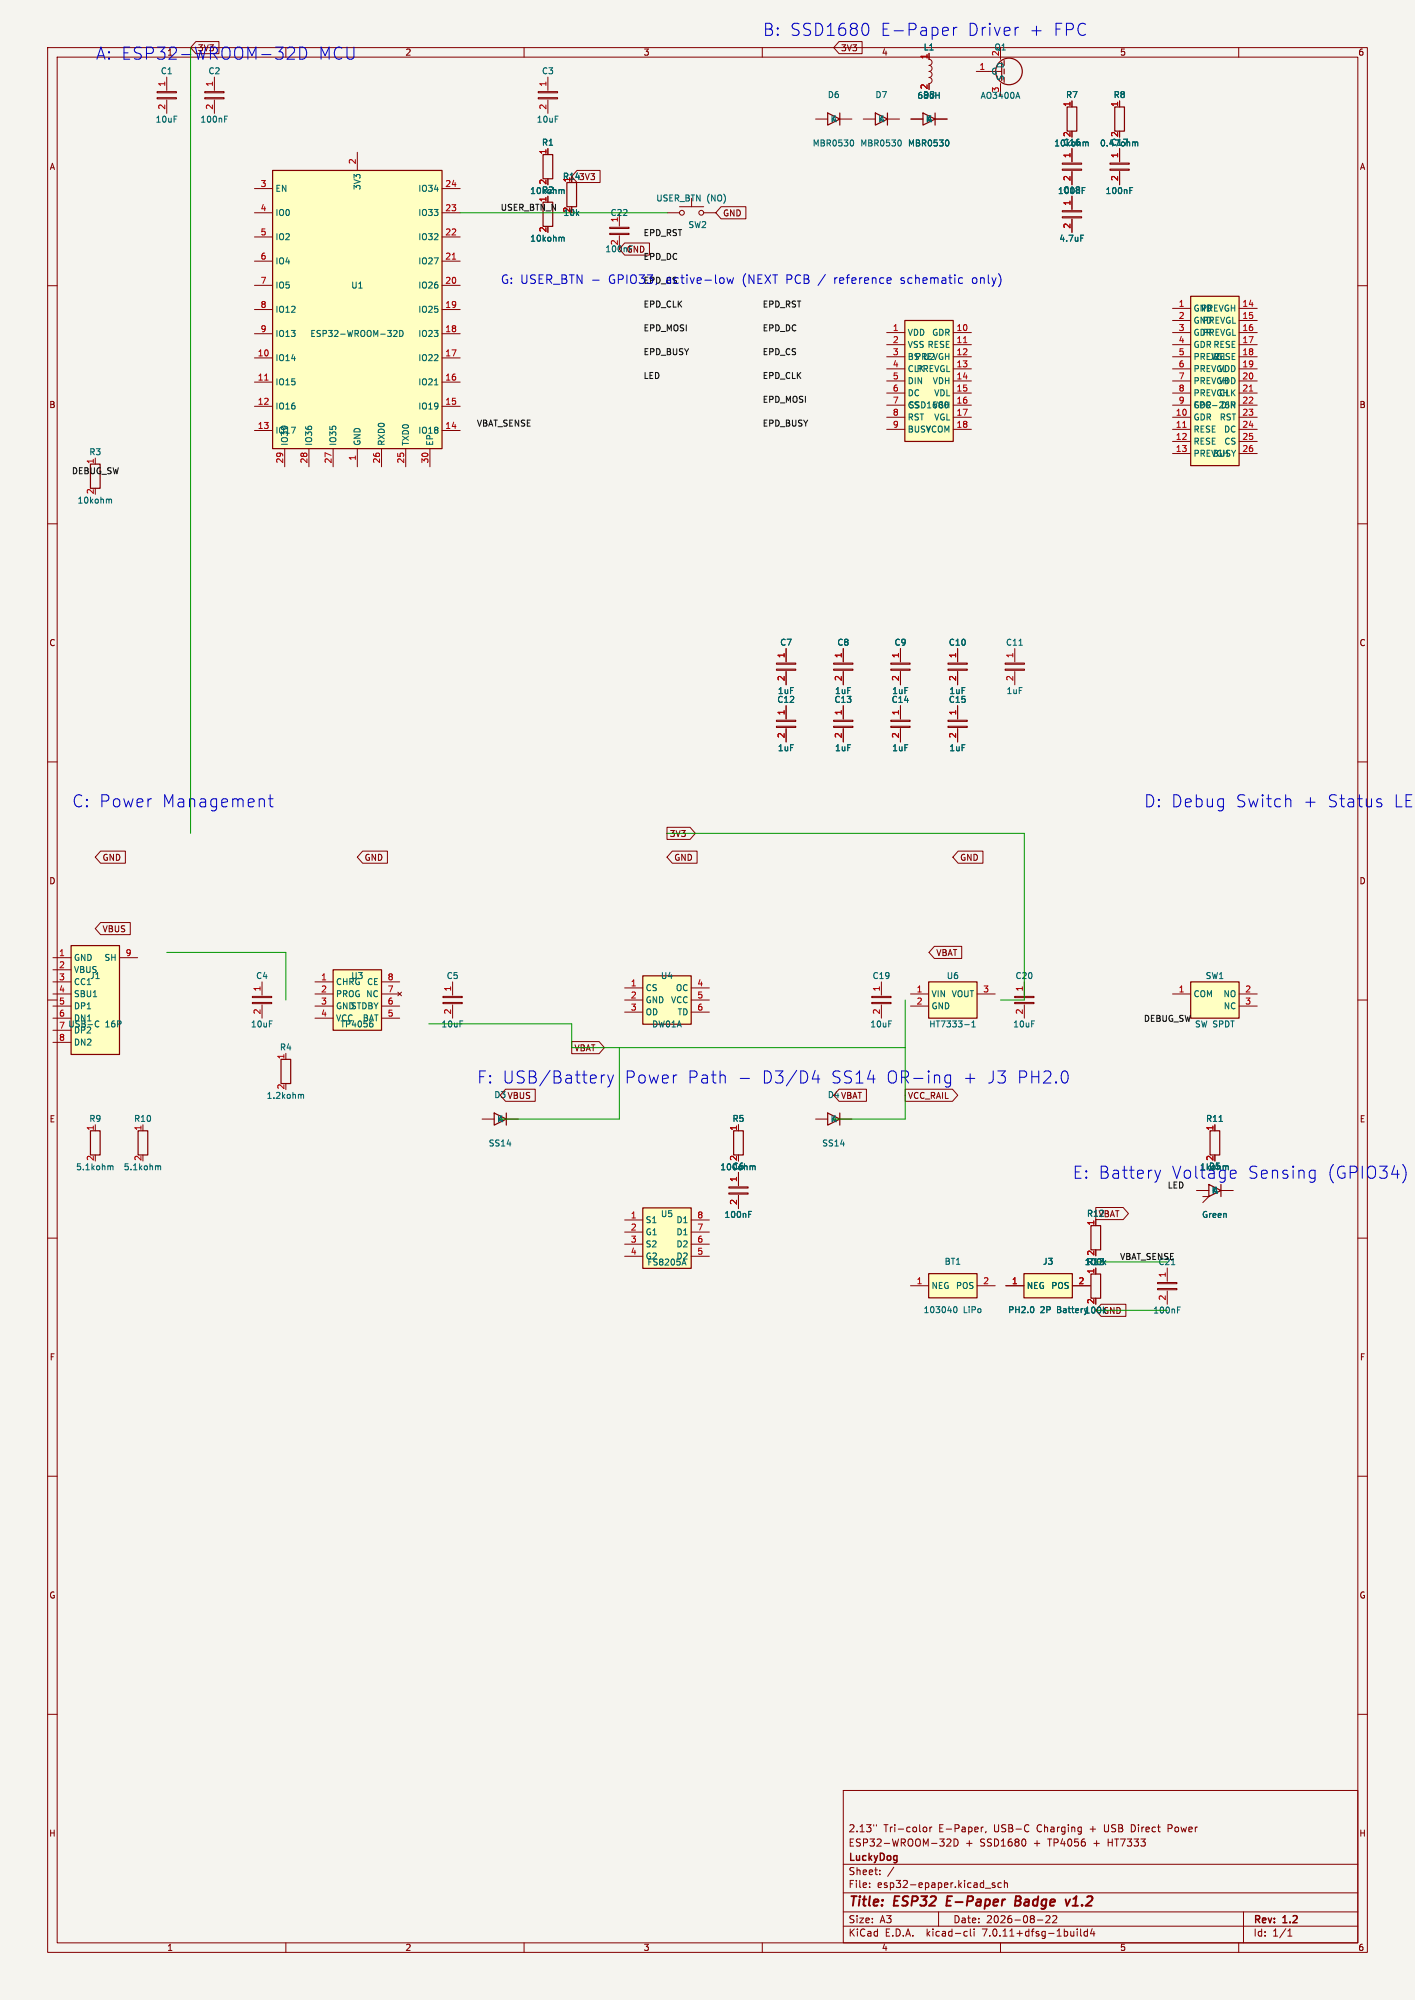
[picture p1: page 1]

VBAT_SENSE D: Debug Switch + Status LED

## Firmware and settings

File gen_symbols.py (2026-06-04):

#!/usr/bin/env python3
"""Generate KiCad 7 symbol library for ESP32 E-Paper Badge.

Custom parts: TP4056, DW01A, FS8205A, HT7333-1, SSD1680, USB-C-16P, FPC-26P,
PH2.0 battery connector, ToggleSwitch
"""
import os, sys
from kiutils.symbol import (
    SymbolLib, Symbol as SySymbol, SymbolPin,
    SyRect, Stroke, Fill, Effects, Font, Property,
    Position as SyPos,
)

OUT = os.path.dirname(os.path.abspath(__file__))

def make_sym(name, ref_prefix, left_pins, right_pins, body_w=600, body_h=None):
    """Create an IC symbol.
    
    left_pins/right_pins: list of (number, name, electrical_type)
    """
    pin_spacing = 100  # mil between pins
    pin_length = 200   # mil (0.2 inches)
    
    max_pins = max(len(left_pins), len(right_pins), 1)
    if body_h is None:
        body_h = (max_pins + 1) * pin_spacing
    
    half_w = body_w // 2
    half_h = body_h // 2
    
    # Body rectangle (kiutils uses inches)
    graphics = [
        SyRect(
            start=SyPos(X=-half_w/1000, Y=-half_h/1000),
            end=SyPos(X=half_w/1000, Y=half_h/1000),
            stroke=Stroke(width=0.254),
            fill=Fill(type='background'),
        )
    ]
    
    pins = []
    
    # Left pins (pin extends LEFT, position at left body edge)
    for i, (num, pname, etype) in enumerate(left_pins):
        y = (-half_h + (i + 1) * pin_spacing) / 1000
        pins.append(SymbolPin(
            electricalType=etype,
            graphicalStyle='line',
            position=SyPos(X=-half_w/1000, Y=y),
            length=pin_length/1000,
            name=pname,
            nameEffects=Effects(font=Font(height=0.762, width=0.762)),
            number=str(num),
            numberEffects=Effects(font=Font(height=0.762, width=0.762)),
        ))
    
    # Right pins (pin extends RIGHT, position at right body edge)
    for i, (num, pname, etype) in enumerate(right_pins):
        y = (-half_h + (i + 1) * pin_spacing) / 1000
        pins.append(SymbolPin(
            electricalType=etype,
            graphicalStyle='line',
            position=SyPos(X=half_w/1000, Y=y),
            length=pin_length/1000,
            name=pname,
            nameEffects=Effects(font=Font(height=0.762, width=0.762)),
            number=str(num),
            numberEffects=Effects(font=Font(height=0.762, width=0.762)),
        ))
    
    return SySymbol(
        libraryNickname='esp32-epaper-lib',
        entryName=name,
        properties=[
            Property(key='Reference', value=ref_prefix, id=0,
                    position=SyPos(X=0, Y=(-half_h - 60)/1000),
                    effects=Effects(font=Font(height=1.0, width=1.0))),
            Property(key='Value', value=name, id=1,
                    position=SyPos(X=0, Y=(half_h + 60)/1000),
                    effects=Effects(font=Font(height=1.0, width=1.0))),
            Property(key='Footprint', value='', id=2,
                    position=SyPos(X=0, Y=(half_h + 160)/1000),
                    effects=Effects(font=Font(height=0.635, width=0.635), hide=True)),
        ],
        graphicItems=graphics,
        pins=pins,
    )


def main():
    symbols = []
    
    # ── TP4056 (SOP-8, Battery Charger) ──
    # Source: TP4056 Datasheet Rev 1.05
    symbols.append(make_sym('TP4056', 'U',
        left_pins=[
            (1, 'CHRG',  'open_collector'),  # Charge status output
            (2, 'PROG',  'input'),            # Charge current set
            (3, 'GND',   'power_in'),
            (4, 'VCC',   'power_in'),         # Input supply
        ],
        right_pins=[
            (8, 'CE',    'input'),            # Chip enable
            (7, 'NC',    'no_connect'),
            (6, 'STDBY', 'open_collector'),   # Standby status
            (5, 'BAT',   'power_out'),        # Battery
        ],
        body_w=600, body_h=500,
    ))
    
    # ── DW01A (SOT-23-6, Battery Protection) ──
    # Source: DW01A Datasheet
    symbols.append(make_sym('DW01A', 'U',
        left_pins=[
            (1, 'CS',  'bidirectional'),
            (2, 'GND', 'power_in'),
            (3, 'OD',  'output'),
        ],
        right_pins=[
            (4, 'OC',  'output'),
            (5, 'VCC', 'power_in'),
            (6, 'TD',  'input'),
        ],
        body_w=500, body_h=500,
    ))
    
    # ── FS8205A (TSSOP-8, Dual N-MOSFET) ──
    # Source: FS8205A Datasheet
    symbols.append(make_sym('FS8205A', 'U',
        left_pins=[
            (1, 'S1', 'passive'),
            (2, 'G1', 'input'),
            (3, 'S2', 'passive'),
            (4, 'G2', 'input'),
        ],
        right_pins=[
            (8, 'D1', 'passive'),
            (7, 'D1', 'passive'),
            (6, 'D2', 'passive'),
            (5, 'D2', 'passive'),
        ],
        body_w=500, body_h=500,
    ))
    
    # ── HT7333-1 (SOT-89, LDO) ──
    # Source: HT7333 Datasheet
    symbols.append(make_sym('HT7333-1', 'U',
        left_pins=[
            (1, 'VIN',  'power_in'),
            (2, 'GND',  'power_in'),
        ],
        right_pins=[
            (3, 'VOUT', 'power_out'),
        ],
        body_w=400, body_h=300,
    ))
    
    # ── SSD1680 (QFN-48, E-Paper Driver IC) ──
    # Source: SSD1680 Datasheet v1.2 + Driver Board v1.3 Schematic
    # Simplified symbol showing only key pins (not all 48)
    symbols.append(make_sym('SSD1680', 'U',
        left_pins=[
            (1,  'VDD',    'power_in'),
            (2,  'VSS',    'power_in'),
            (3,  'BS',     'input'),       # Bus select: 0=SPI
            (4,  'CLK',    'input'),       # SPI clock
            (5,  'DIN',    'input'),       # SPI data in
            (6,  'DC',     'input'),       # Data/Command
            (7,  'CS',     'input'),       # Chip select
            (8,  'RST',    'input'),       # Reset
            (9,  'BUSY',   'output'),      # Busy status
        ],
        right_pins=[
            (10, 'GDR',    'output'),      # Gate drive
            (11, 'RESE',   'passive'),     # Current sense
            (12, 'PREVGH', 'passive'),     # Positive gate voltage
            (13, 'PREVGL', 'passive'),     # Negative gate voltage
            (14, 'VDH',    'passive'),     # Positive driving voltage
            (15, 'VDL',    'passive'),     # Negative driving voltage
            (16, 'VGH',    'passive'),     # Gate high
            (17, 'VGL',    'passive'),     # Gate low
            (18, 'VCOM',   'passive'),     # Common mode voltage
        ],
        body_w=700, body_h=1900,
    ))
    
    # ── USB-C 16Pin Receptacle ──
    # Source: USB Type-C Spec R2.1
    symbols.append(make_sym('USB-C-16P', 'J',
        left_pins=[
            (1,  'GND',  'power_in'),
            (2,  'VBUS', 'power_out'),
            (3,  'CC1',  'bidirectional'),
            (4,  'SBU1', 'bidirectional'),
            (5,  'DP1',  'bidirectional'),
            (6,  'DN1',  'bidirectional'),
            (7,  'DP2',  'bidirectional'),
            (8,  'DN2',  'bidirectional'),
        ],
        right_pins=[
            (9,  'SH',   'passive'),   # Shield
        ],
        body_w=600, body_h=900,
    ))
    
    # ── FPC 26P 0.5mm Connector (E-Paper Display) ──
    # Source: DEPG0213RWS FPC pinout
    symbols.append(make_sym('FPC-26P-Epaper', 'J',
        left_pins=[
            (1,  'GND',    'power_in'),
            (2,  'GND',    'power_in'),
            (3,  'GDR',    'passive'),
            (4,  'GDR',    'passive'),
            (5,  'PREVGL', 'passive'),
            (6,  'PREVGL', 'passive'),
            (7,  'PREVGH', 'passive'),
            (8,  'PREVGH', 'passive'),
            (9,  'GDR',    'passive'),
            (10, 'GDR',    'passive'),
            (11, 'RESE',   'passive'),
            (12, 'RESE',   'passive'),
            (13, 'PREVGH', 'passive'),
        ],
        right_pins=[
            (14, 'PREVGH', 'passive'),
            (15, 'PREVGL', 'passive'),
            (16, 'PREVGL', 'passive'),
            (17, 'RESE',   'passive'),
            (18, 'RESE',   'passive'),
            (19, 'VDD',    'power_in'),
            (20, 'VDD',    'power_in'),
            (21, 'CLK',    'input'),
            (22, 'DIN',    'input'),
            (23, 'RST',    'input'),
            (24, 'DC',     'input'),
            (25, 'CS',     'input'),
            (26, 'BUSY',   'output'),
        ],
        body_w=700, body_h=1500,
    ))
    
    # ── Battery Holder (18650) ──
    symbols.append(make_sym('BatteryHolder_18650', 'BT',
        left_pins=[
            (1, 'NEG', 'power_in'),
        ],
        right_pins=[
            (2, 'POS', 'power_out'),
        ],
        body_w=800, body_h=300,
    ))
    
    # ── PH2.0 2-pin connector for 103040 LiPo battery ──
    symbols.append(make_sym('PH2_0-2P-Battery', 'J',
        left_pins=[
            (1, 'BAT+', 'power_out'),
        ],
        right_pins=[
            (2, 'BAT-', 'power_in'),
        ],
        body_w=500, body_h=300,
    ))

    # ── Toggle Switch SPDT ──
    symbols.append(make_sym('ToggleSwitch_SPDT', 'SW',
        left_pins=[
            (1, 'COM', 'passive'),
        ],
        right_pins=[
            (2, 'NO',  'passive'),
            (3, 'NC',  'passive'),
        ],
        body_w=400, body_h=400,
    ))
    
    # Build library
    lib = SymbolLib(
        version='20211014',
        generator='kiutils',
        symbols=symbols,
    )
    
    path = os.path.join(OUT, 'esp32-epaper-lib.kicad_sym')
    lib.to_file(path, encoding='utf-8')
    print(f"✓ Symbol library saved: {path}")
    print(f"  Symbols: {len(symbols)}")
    for s in symbols:
        print(f"    - {s.entryName} ({len(s.pins)} pins)")
    return lib


if __name__ == '__main__':
    main()

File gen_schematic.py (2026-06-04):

#!/usr/bin/env python3
"""Generate complete KiCad 7 schematic for ESP32 E-Paper Badge.

Circuit blocks:
  A: ESP32-WROOM-32D (MCU) — uses Device:R, Device:C etc from KiCad standard lib
  B: SSD1680 + FPC-26P (E-Paper Driver)
  C: TP4056 + DW01A + FS8205A + HT7333 + D3/D4 USB/Battery OR-ing (Power)
  D: USB-C Connector
  E: Toggle Switch + Status LED
  F: Decoupling caps and pull-up resistors

All custom ICs use esp32-epaper-lib.
Passive components (R, C, L, LED, D) use KiCad standard Device library.
"""
import os, uuid
from kiutils.items.common import Font
from kiutils.schematic import (
    Schematic, SchematicSymbol, Position, Property, Effects,
    Connection, GlobalLabel, LocalLabel, Junction, NoConnect,
    Rectangle, Text, PageSettings, TitleBlock,
)
from kiutils.symbol import SymbolLib

OUT = os.path.dirname(os.path.abspath(__file__))

def uid():
    return str(uuid.uuid4())

# ── Pin position calculator ──────────────────────────────────
# Our symbols use body rectangles and pins at specific offsets.
# When placed at (X,Y), pin positions depend on the symbol's internal geometry.
# We need to track where each pin ends up after placement.

class PinPos:
    """Track pin locations for a placed symbol."""
    def __init__(self, x, y, pins_info):
        """
        x, y: symbol placement position (mm)
        pins_info: dict of pin_name -> (offset_x_mm, offset_y_mm) 
                   relative to symbol origin
        """
        self.x = x
        self.y = y
        self.pins = {}
        for name, (ox, oy) in pins_info.items():
            self.pins[name] = (x + ox, y + oy)
    
    def pin(self, name):
        return self.pins[name]


def wire(sch, x1, y1, x2, y2):
    """Add a wire segment."""
    sch.graphicalItems.append(Connection(
        type='wire',
        points=[Position(X=x1, Y=y1), Position(X=x2, Y=y2)],
        uuid=uid(),
    ))


def label(sch, text, x, y, shape='input'):
    """Add a global label (power net or named net)."""
    sch.globalLabels.append(GlobalLabel(
        text=text,
        shape=shape,
        position=Position(X=x, Y=y),
        effects=Effects(font=Font(height=1.27, width=1.27)),
        uuid=uid(),
    ))


def local_label(sch, text, x, y):
    """Add a local net label."""
    sch.labels.append(LocalLabel(
        text=text,
        position=Position(X=x, Y=y),
        effects=Effects(font=Font(height=1.27, width=1.27)),
        uuid=uid(),
    ))


def junction(sch, x, y):
    """Add a junction (wire node)."""
    sch.junctions.append(Junction(position=Position(X=x, Y=y), uuid=uid()))


def no_connect(sch, x, y):
    """Add a no-connect marker."""
    sch.noConnects.append(NoConnect(position=Position(X=x, Y=y), uuid=uid()))


def place_symbol(sch, lib_nick, entry, ref, value, x, y, rotation=0):
    """Place a component on the schematic."""
    sym = SchematicSymbol(
        libraryNickname=lib_nick,
        entryName=entry,
        position=Position(X=x, Y=y, angle=rotation),
        uuid=uid(),
        properties=[
            Property(key='Reference', value=ref, id=0,
                    position=Position(X=x, Y=y - 5),
                    effects=Effects(font=Font(height=1.27, width=1.27))),
            Property(key='Value', value=value, id=1,
                    position=Position(X=x, Y=y + 5),
                    effects=Effects(font=Font(height=1.27, width=1.27))),
        ],
    )
    sch.schematicSymbols.append(sym)
    return sym


def place_device(sch, ref, value, x, y, rotation=0):
    """Place a standard KiCad Device library component."""
    # Determine library ID from ref prefix
    lib_map = {
        'R':  'Device:R',
        'C':  'Device:C',
        'L':  'Device:L',
        'D':  'Device:D',
        'LED':'Device:LED',
        'Q':  'Device:Q_NMOS_GSD',
        'SW': 'Device:RotarySwitch',  # Will use custom
        'J':  'esp32-epaper-lib:USB-C-16P',
        'BT': 'esp32-epaper-lib:BatteryHolder_18650',
        'F':  'Device:Polyfuse',
    }
    
    # Custom lib parts
    custom = {
        'U3': 'esp32-epaper-lib:TP4056',
        'U4': 'esp32-epaper-lib:DW01A',
        'U5': 'esp32-epaper-lib:FS8205A',
        'U6': 'esp32-epaper-lib:HT7333-1',
        'U2': 'esp32-epaper-lib:SSD1680',
    }
    
    if ref in custom:
        lib_id = custom[ref]
    else:
        prefix = ''.join(c for c in ref if c.isalpha())
        lib_id = lib_map.get(prefix, f'Device:{prefix}')
    
    lib_nick, entry = lib_id.split(':')
    return place_symbol(sch, lib_nick, entry, ref, value, x, y, rotation)


# ── Section rectangles for visual grouping ──
def section_box(sch, x1, y1, x2, y2, title, x_title=0, y_title=0):
    """Draw a dashed rectangle around a schematic section."""
    sch.graphicalItems.append(Rectangle(
        start=Position(X=x1, Y=y1),
        end=Position(X=x2, Y=y2),
        stroke=Stroke(width=0.3, type='dash'),
        fill=Fill(type='none'),
        uuid=uid(),
    ))
    sch.graphicalItems.append(Text(
        text=title,
        position=Position(X=x_title or x1 + 5, Y=y_title or y1 - 3),
        effects=Effects(font=Font(height=2.54, width=2.54)),
        uuid=uid(),
    ))


# ══════════════════════════════════════════════════════════════
# Main schematic builder
# ══════════════════════════════════════════════════════════════
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

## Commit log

2026-05-27 feat: ESP32 E-Paper Badge schematic v1.0
    [esp32-epaper.kicad_sch]
2026-05-27 fix: KiCad 7 schematic validation - lib_symbols complete + ERC pass
    - Added 7 missing standard KiCad library symbol definitions (Device:C/R/D/L/LED/Q_NMOS, RF_Module:ESP32-WROOM-32D)
    - Fixed global_label shape types (power_out/power_in -> output/input) for KiCad 7 compatibility
    - Fixed version string to 20221206 for KiCad 7.0.x
    - Netlist export: 46 components, 186 nets
    - PDF export verified
    - Added helper scripts: fix_lib_symbols.py, test_elements.py
    [esp32-epaper.kicad_sch]
2026-05-28 feat: add battery voltage sensing divider (R12/R13/C21)
    New components:
    - R12 (100k): BAT+ to VBAT_SENSE divider top
    - R13 (100k): VBAT_SENSE to GND divider bottom
    - C21 (100nF): VBAT_SENSE filter cap to GND
    - GPIO34 (ADC1_CH6) assigned as VBAT_SENSE
    Design review:
    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
    [esp32-epaper.kicad_sch]
2026-05-28 docs: 添加PCB设计外包需求文档
2026-05-29 docs: 墨水屏FPC放另一侧短边
2026-05-29 docs: 更新外包文档-增加D3/D4电源切换+USB直供电+软包电池103040+PH2.0
2026-06-04 feat: sync schematic with v1.1 power path requirements
    [esp32-epaper.kicad_sch]
2026-08-21 feat: add next-pcb user provisioning button
    [esp32-epaper.kicad_sch]
2026-09-26 docs: 新增 V2 改板需求说明（主控换 ESP32-C6-MINI-1、原生 USB、电池分压修正、按键重定义、板 67×28 堆叠与电芯 ≤4mm）
2026-09-26 docs: V2 改板说明补充侧按按键、外壳沿用核对、HT7333 保留；板 67x28 与电芯 <=4mm 定稿
2026-09-26 docs: V2 改板说明去掉外壳约束、板厚 0.6mm、不设安装孔、厚度按区域法重算(≈9.1-9.6mm)
2026-09-27 docs: README 顶部标注 V2 为当前有效需求并加文档索引
2026-10-04 docs(pcb): 改板需求说明 V2.1 —— 在 V2 基础上增补板载温湿度检测
    新增内容（14 处增补，V2 未提及处一律沿用 V2）：
    - 新增项 §3.4：U7 AHT20(I2C,0x38) + R16/R17(10k 上拉) + C23(100nF)
    - §5.1 引脚映射：TH_SDA=IO0(脚12) / TH_SCL=IO1(脚13)；IO0/IO1 从备用脚改为 I2C 占用
    - 新增 §5.7：I2C 电路图、布局要求（稀疏铺铜/距热源≥10mm/靠板边）、外壳透气孔硬要求
    - §2 变更原因补实测数字：Flash +1,086B / RAM +16B；单次检测 9-81ms（AHT20 80ms、SHT4x 8.3ms）
    - §8 验收 +3 项，§9 改板步骤 +1 步，§10 待确认 +3 条，§11 参考文档 +3 份
    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
2026-10-04 docs(pcb): V2.1 补充卡牌保存环境要求（纯要求类，不新增器件）
    - §5.7 追加「产品用途与硬要求」6 条：测点必须透气/禁止点胶覆膜、加防水透气膜、
    量程精度 >±2%RH/±0.3℃、热源 ≥10mm 的理由量化、外壳禁用 PVC/木质/酸性材料、
    透气孔独立于显示区
    - §10 追加待确认：是否预留环境光/UV 传感器空位（保存场景褪色主因；本期留位成本最低，
    不预留则本期不加，仅在图中留 0603/DFN 空位）
2026-10-04 docs(pcb): 新增《BOM锁定表-V2.1》并接入改板说明（选型由需求方锁定）
    - BOM锁定表-V2.1.md/.xlsx：锁定件给立创编号（U1 主控 C5736265 现货0需订货、
    U4 DW01A C18164398 现货9180、U5 FS8205A C2830320、U7 AHT20 C2757850）；
    参数锁定件给硬指标与不接受项（LDO Iq≤4µA 不接受 AMS1117/TPS77x33/ME6211、
    传感器不接受 DHT11/22）；屏/电芯/开模标为须正式询价
    - 改板说明 V2.1：点明 BOM 锁定表的效力（冲突以其为准、等效替代需书面同意）、
    §3.4 U7 选型依据、§8 交付物须与锁定表逐项一致、§10 增加 FPC 针数红线项
    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
2026-10-04 docs(pcb): 补上 BOM锁定表-V2.1.xlsx（Excel 版，供外包/贴片厂直接用）
    [BOM锁定表-V2.1.xlsx]
2026-10-04 docs(pcb): V2.2 —— 主控换 ESP32-C3-MINI-1-N4 并全线降本
    主控：C6-MINI-1-N4(C5736265,¥17.21@1300) -> C3-MINI-1-N4(C2838502,¥12.48@650)
    - 依据：pin-to-pin 兼容(焊盘/外形不变)、原生 USB 保留、C3 实测固件 1,331,535B(比 C6 小 22KB)、
    ADC1 5 路(只用 1 路)、strapping 仅 GPIO2/8/9；代价 Wi-Fi 4(日连一次场景无影响)
    - 按 C3 数据手册 Table 3-1 重排全部引脚：USB 必须改到模组脚 26/27；脚 15/17/24/25 在 C3 上是 NC；
    EPD 六线改到 FSPI 默认脚 IO6/IO7/IO10 + IO8/IO9/IO2/IO5；电量采样改 IO4(ADC1_CH4)；
    VBUS 检测改 IO20；两处 strapping 脚仅作输出且明确禁止外挂上下拉
    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
    [BOM锁定表-V2.2.xlsx]
2026-10-04 docs(pcb): 屏按 ¥9 重算整机成本 + 新增金属外壳（定制铁皮）射频约束
    成本（工具计算，1000 片量级）：
    - 电子 BOM ¥31.67-34.92；制造/结构 ¥7.20-16.00
    - 单台制造成本 ≈¥38.87-50.92（旧口径屏 ¥18-28 时约 ¥50-73，降 ¥11-22）
    - 一次性：塑料壳开模 ¥1.5-4万 + 铁皮冲压模 ¥0.3-1万 = ¥1.8-5万
    - 定价参考：×2.5/3.0/3.5 = ¥97-178；收藏品定位 ¥199-299 毛利率 74-87%
    铁皮射频约束（新增到改板说明 §5.5 第4条 / §6 第1条）：
    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
    [BOM锁定表-V2.2.xlsx]
2026-10-04 docs(pcb): 正面外观金属件（拉丝）约束修订 —— 仅正面纯外观，建议改铝
    - §5.5 第4条改写：正面金属射频风险远小于背面（天线在元件面朝背面辐射，正面金属隔着 PCB 地平面）
    仍要求：不覆盖屏显示区(按可见区 48.55x23.71mm 开窗)、不挡透气孔、尾部区收窄/断开、
    边缘与天线区投影至少留 15mm、整机实测 RSSI 衰减 >6dB 判不合格
    - 材料建议：拉丝铝+阳极氧化（铁会锈、铁磁、同厚重 3 倍）；附重量实算
    0.3mm：铝 1.52g / 铁 4.43g；0.5mm：铝 2.53g / 铁 7.38g
    - §6 措辞同步；§10 待确认改为外观件尺寸/厚度/开窗/拉丝方向/阳极颜色/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
    [BOM锁定表-V2.2.xlsx]
